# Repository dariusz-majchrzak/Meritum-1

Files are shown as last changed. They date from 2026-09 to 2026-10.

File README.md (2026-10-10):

# Meritum 1 clone
This repository provides all the files needed to build a **Meritum 1 (Model 1)** ( https://pl.wikipedia.org/wiki/Meritum_(komputer) ) hardware recreation, closely following the design of the first microcomputer to be mass‑produced in Poland.<br>

Production of the Meritum computer began in mid‑1983, and its architecture was based on a design similar to the TRS‑80 Model I. Across all versions — Meritum I, II, and III — approximately 2,500 units were produced between 1984 and 1986.<br>

It has fascinated me for years as an important part of Poland’s computing history. I never had the chance to see an original unit in person, and my attempts to buy one at auctions quickly ended with prices far beyond reach. 
I also noticed that almost no modern retro‑computing projects related to it exist.

Given that, I decided to build one myself: using the documentation available online — schematics, module descriptions, and board photos — I set out to recreate the machine as my own hardware project.

**Meritum 1 (Model 1)** <br>
Basic Technical Specifications:
* RAM: 16 KB (RAMD) + 1 KB (RAMS)
* ROM: 14 KB (BASIC)
* Video Memory: 1 KB (RAMS)
* Display Modes: Text — 16×64 or 16×32
* Peripherals: serial interface (i8251), parallel interface (i8255), tape connector
* Colors: Monochrome
<br>
As of September 27, 2026, there are 4 successful builds (based on this pcb project), so the design files can be assumed valid.<br>
<br>

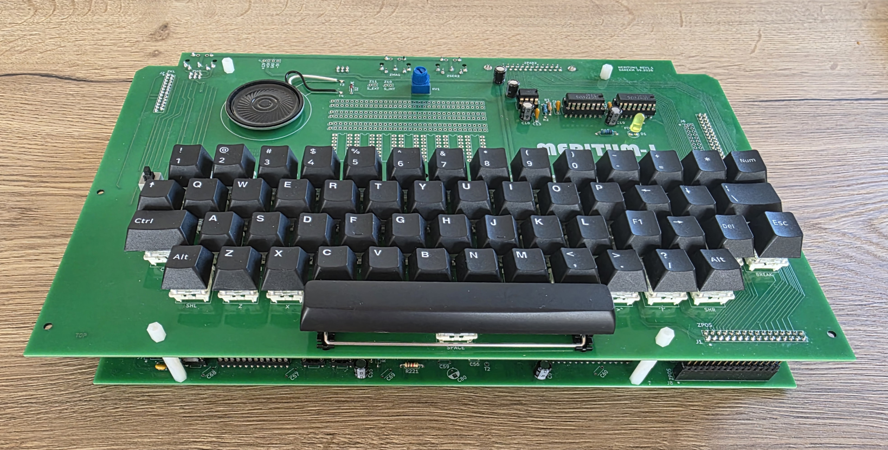
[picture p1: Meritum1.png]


Important notes:<br>
* Please note that this is a complex hardware project that requires solid technical expertise from anyone who decides to build it.<br>
* While significant care has been taken during the design and verification process, the project may still need additional fixes, especially if the original design included fixes implemented directly at the PCB level that were not reflected in the published schematics.

## PCBs
The clone consists of two separate PCBs:
* [Meritum_PGW](Meritum_PGW) (Meritum Płyta Główna) - is the main board.
* [Meritum_KLT](Meritum_KLT) (Meritum Klawiatura) - is a replacement keyboard that uses standard Cherry MX switches.

## ROMs
Since the licensing status of the ROMs used in the Meritum 1 computer is not clear to me, I have not included them in this repository.<br> 
Below, however, I provide links to a websites where they can be found, along with many other valuable resources:
* https://web.archive.org/web/20201023154655/https://sites.google.com/site/krzkomar/meritum-1
* https://www.planetemu.net/rom/mame-roms-merged/meritum1<br>
  
Many useful materials can also be found at: https://www.speccy.pl/news.php .

## Assembling
Although the mainboard includes several configuration jumpers, it does not require any additional settings that need to be adjusted before powering it on. The default configuration is sufficient.<br>

To connect mainboard with keyboard I have used:
-  single and double Row, 2.54mm straight, Gold PCB Female Sockets Connector
-  single and double Row, 2.54mm straight, Gold PCB Male Pin Header connector (h=29.5mm)
  
More to follow.

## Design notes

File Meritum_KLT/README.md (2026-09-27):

# Meritum 1 - keyboard

This part of the project is the clone of the Meritum 1 keyboard.

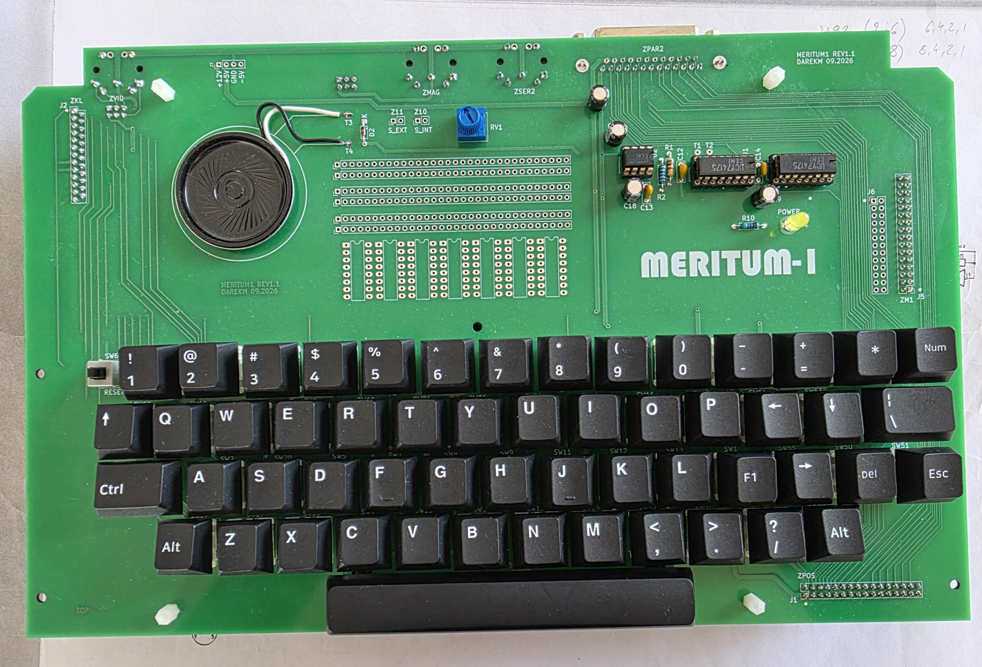
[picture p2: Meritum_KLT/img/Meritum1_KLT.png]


## Files
This directory contains: 

* [BOM](bom) - Interactive HTML BOM
* [Gerber](gerber) - files (JLCPCB-compatible zip files)
* [IMG](img) - photos of the keyboard
* [KiCAD](kicad) - project design in KiCAD 10
* [Schematic](schematic) - Schematic in PDF format

## Assembling
As for assembling the keyboard PCB, there are no major challenges here. The board is relatively straightforward to build.<br> 
One piece of information may be more important: for mounting the switches I used gold‑plated hot‑swap sockets for mechanical keyboards.
See: [Meritum1_KLT_BOTTOM](img/Meritum1_KLT_BOTTOM.png)

More to follow.

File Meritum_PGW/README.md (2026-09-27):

# Meritum 1 - mainboard

This part of the project is the clone of the Meritum 1 mainboard.

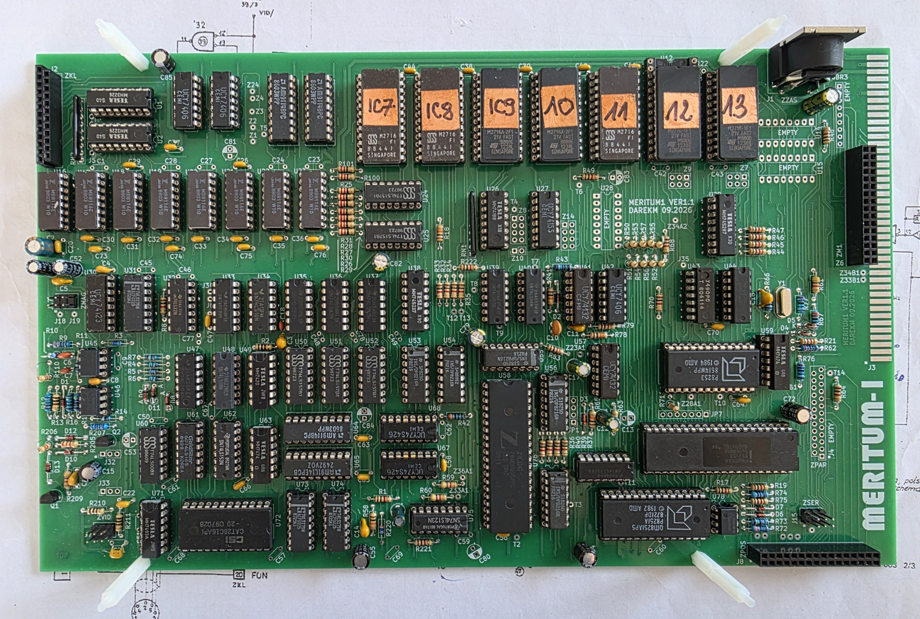
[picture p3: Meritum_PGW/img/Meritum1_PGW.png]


## Files
This directory contains: 

* [BOM](bom) - Interactive HTML BOM
* [Gerber](gerber) - files (JLCPCB-compatible zip files)
* [IMG](img) - photos of the mainboard
* [KiCAD](kicad) - project design in KiCAD 10
* [Schematic](schematic) - Schematic in PDF format

## Assembling
WIP.

More to follow.

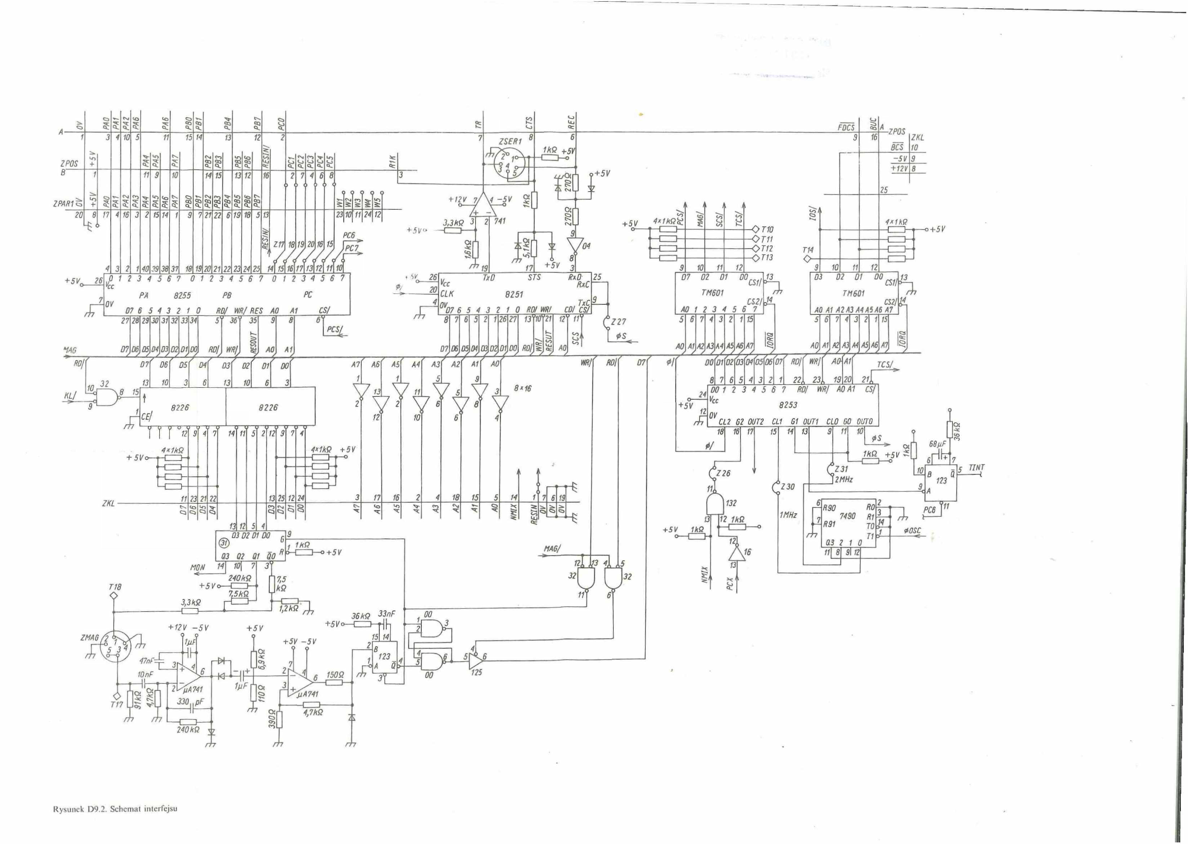
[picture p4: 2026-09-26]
docs/scans/1/interface.png

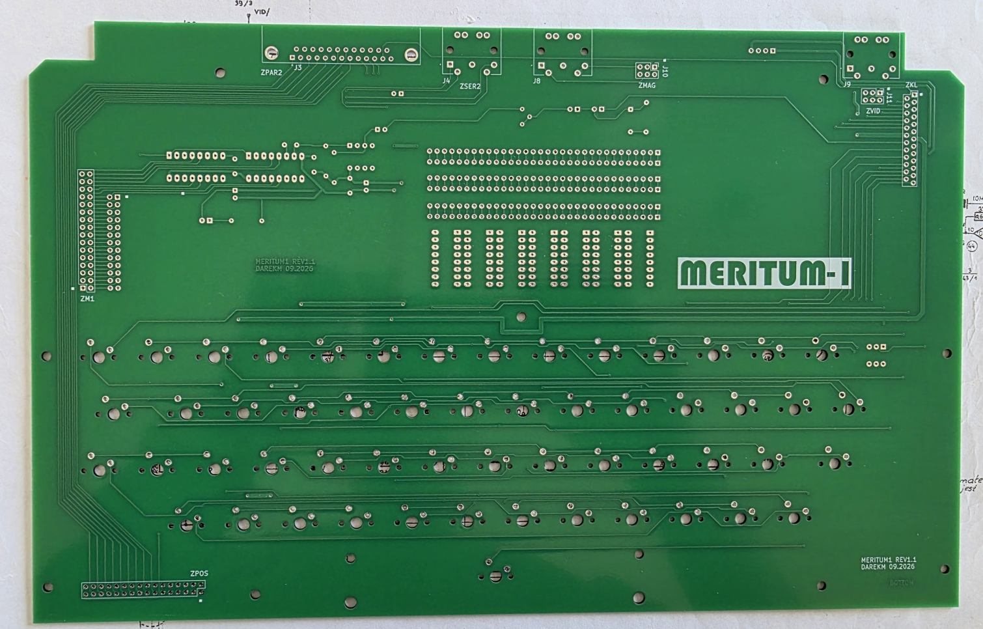
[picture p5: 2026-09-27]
Meritum_KLT/img/Meritum1_KLT_PCB_BOTTOM.png

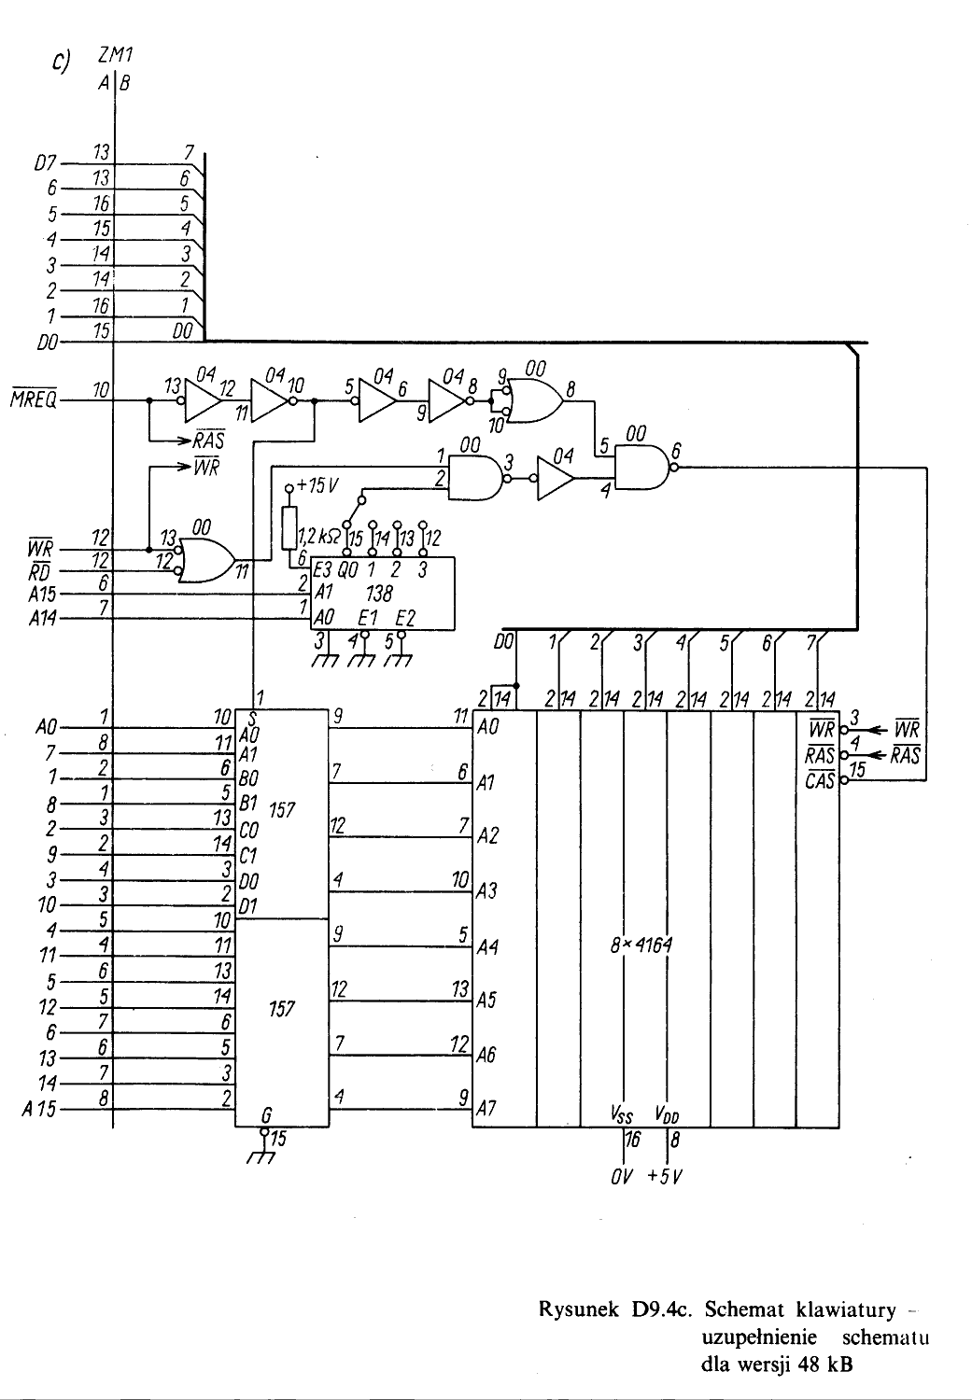
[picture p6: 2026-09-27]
docs/scans/3/D9-4c.png

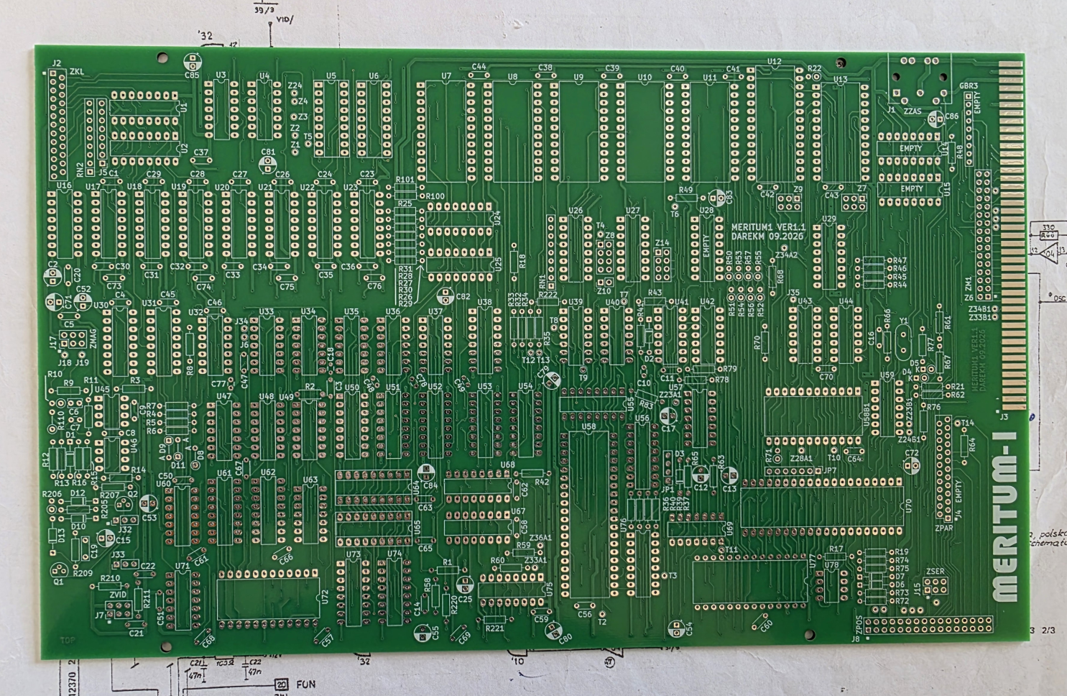
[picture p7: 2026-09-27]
Meritum_PGW/img/Meritum1_PGW_PCB_TOP.png

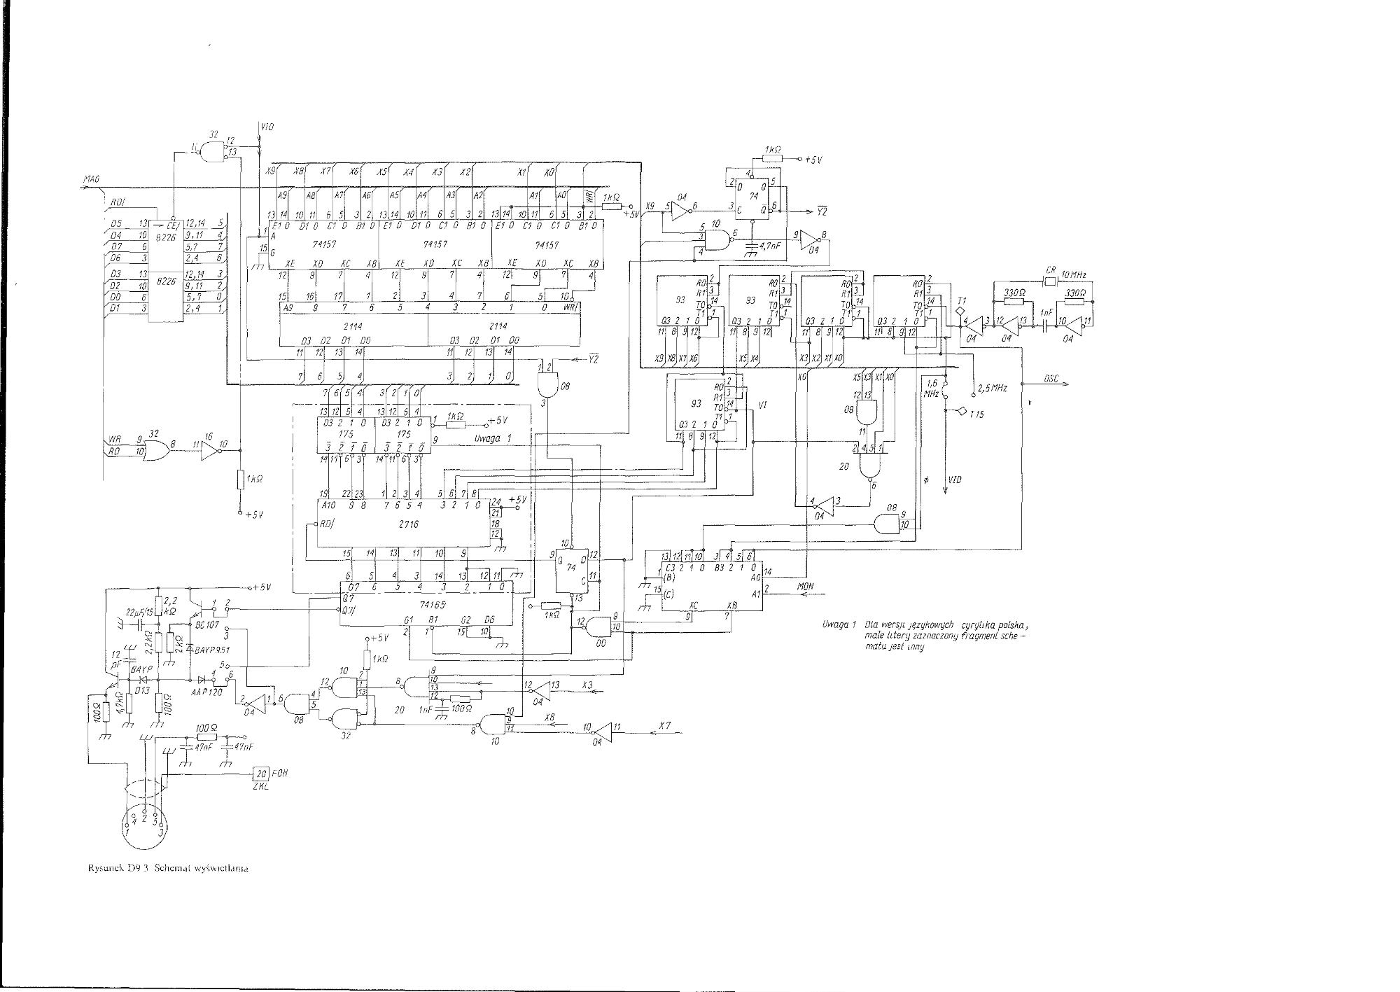
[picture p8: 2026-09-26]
docs/scans/1/display.png

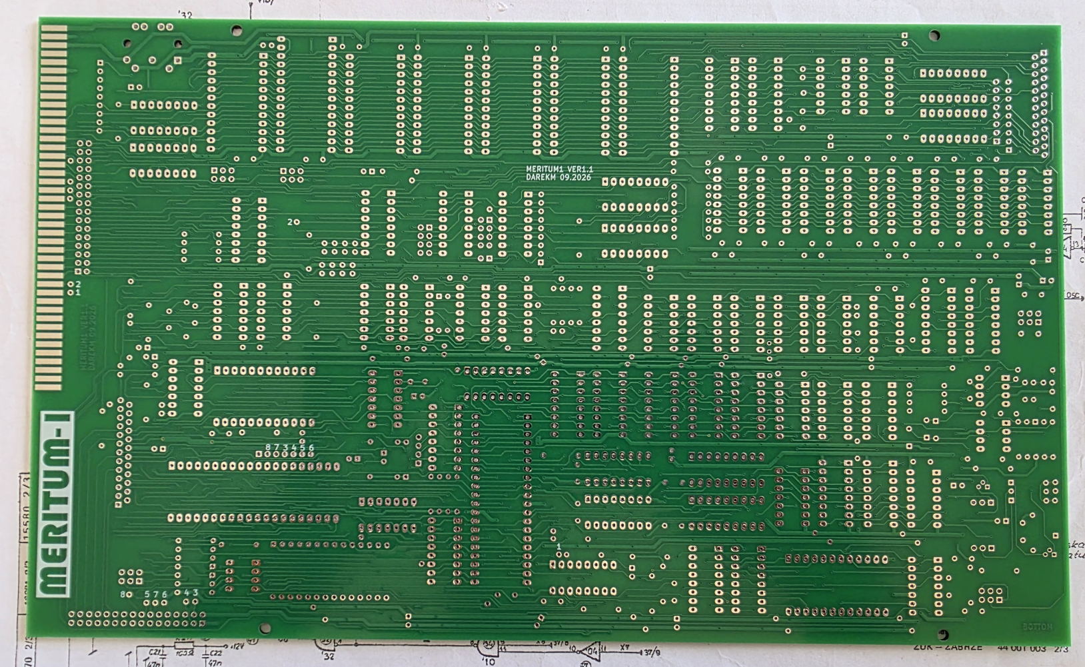
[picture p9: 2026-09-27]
Meritum_PGW/img/Meritum1_PGW_PCB_BOTTOM.png

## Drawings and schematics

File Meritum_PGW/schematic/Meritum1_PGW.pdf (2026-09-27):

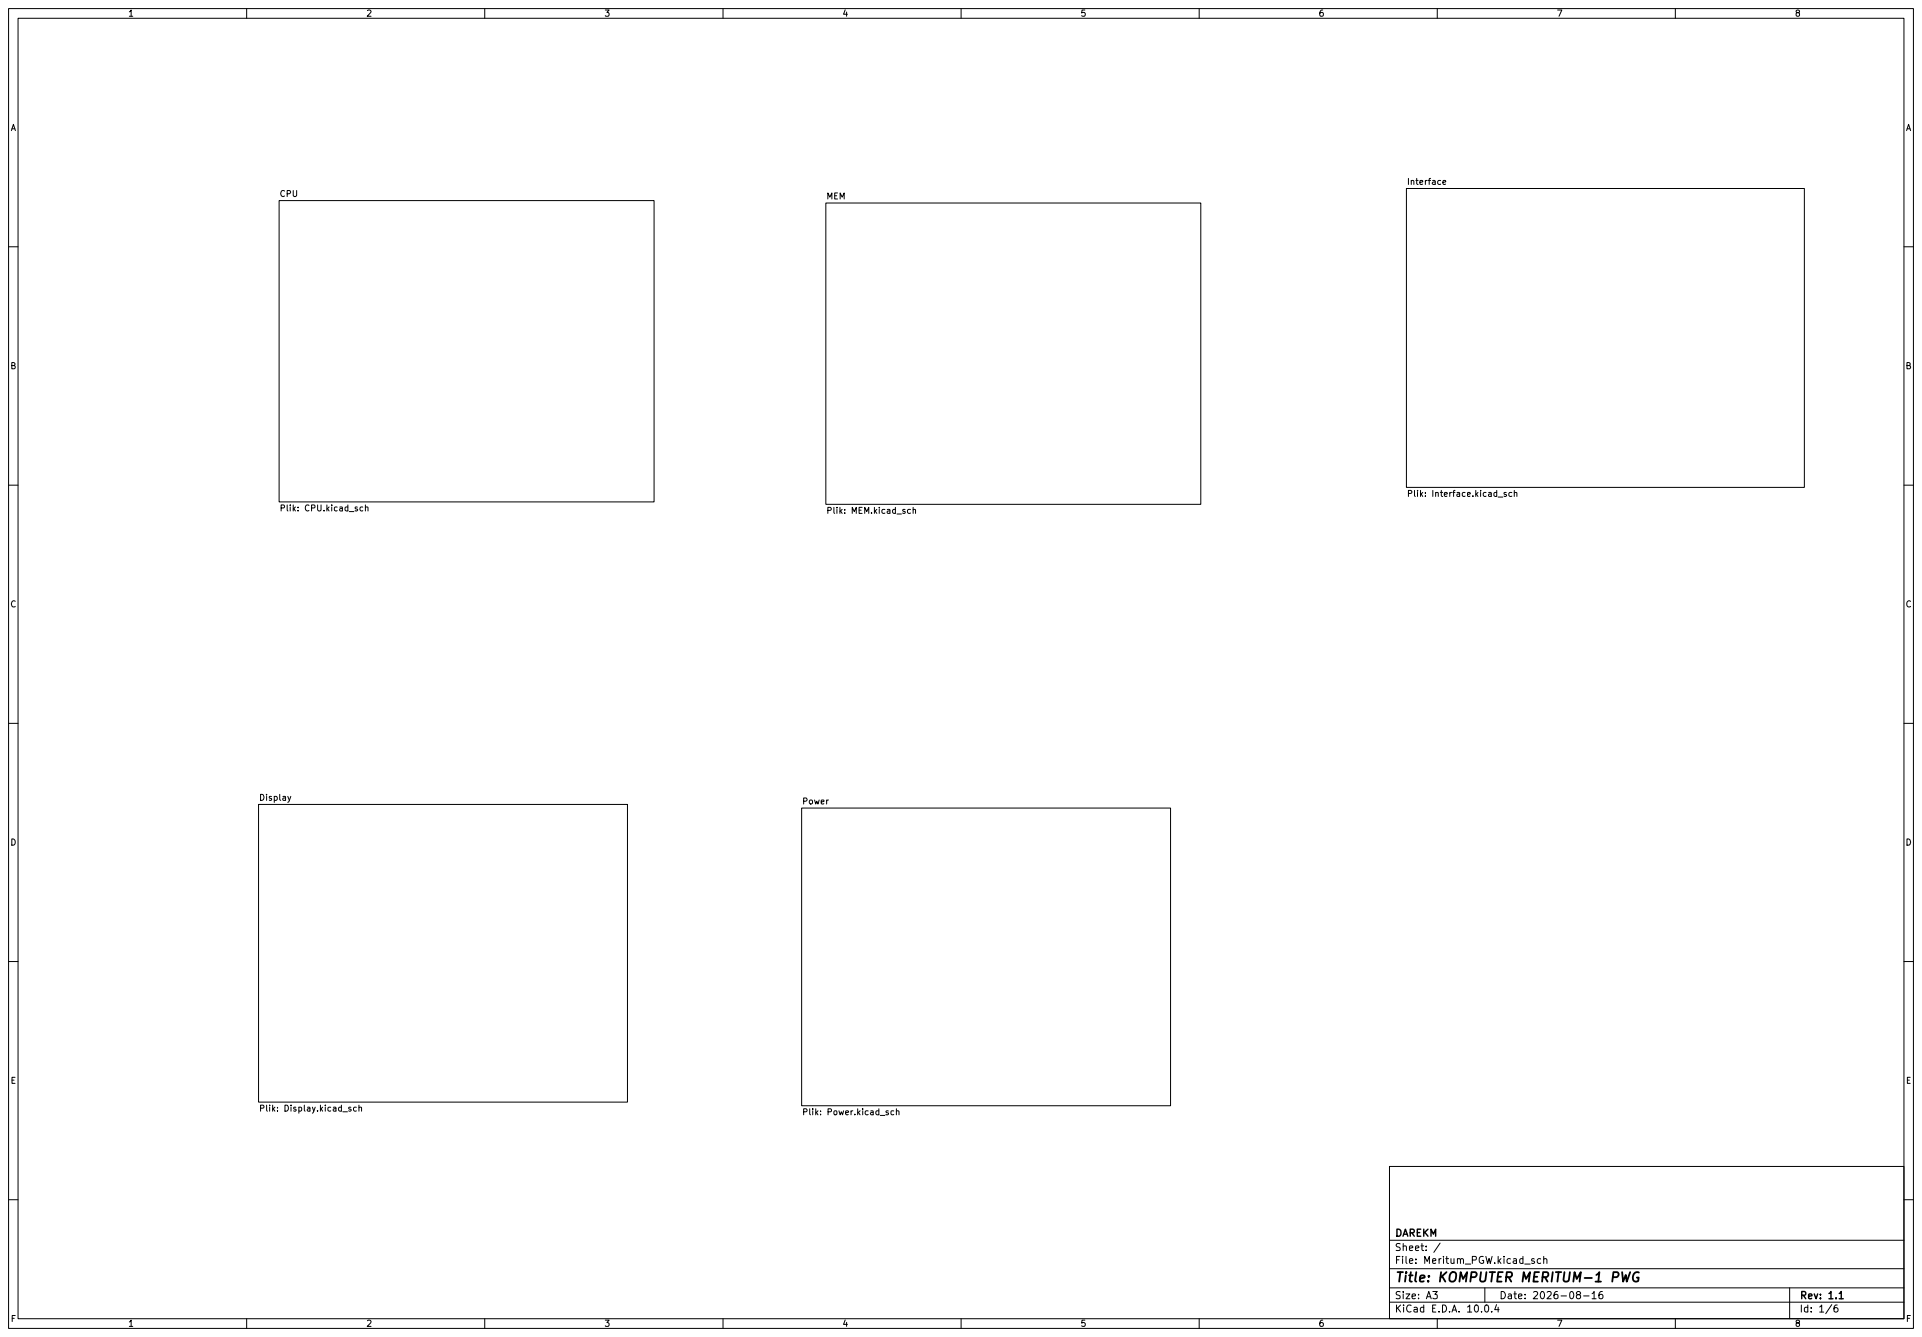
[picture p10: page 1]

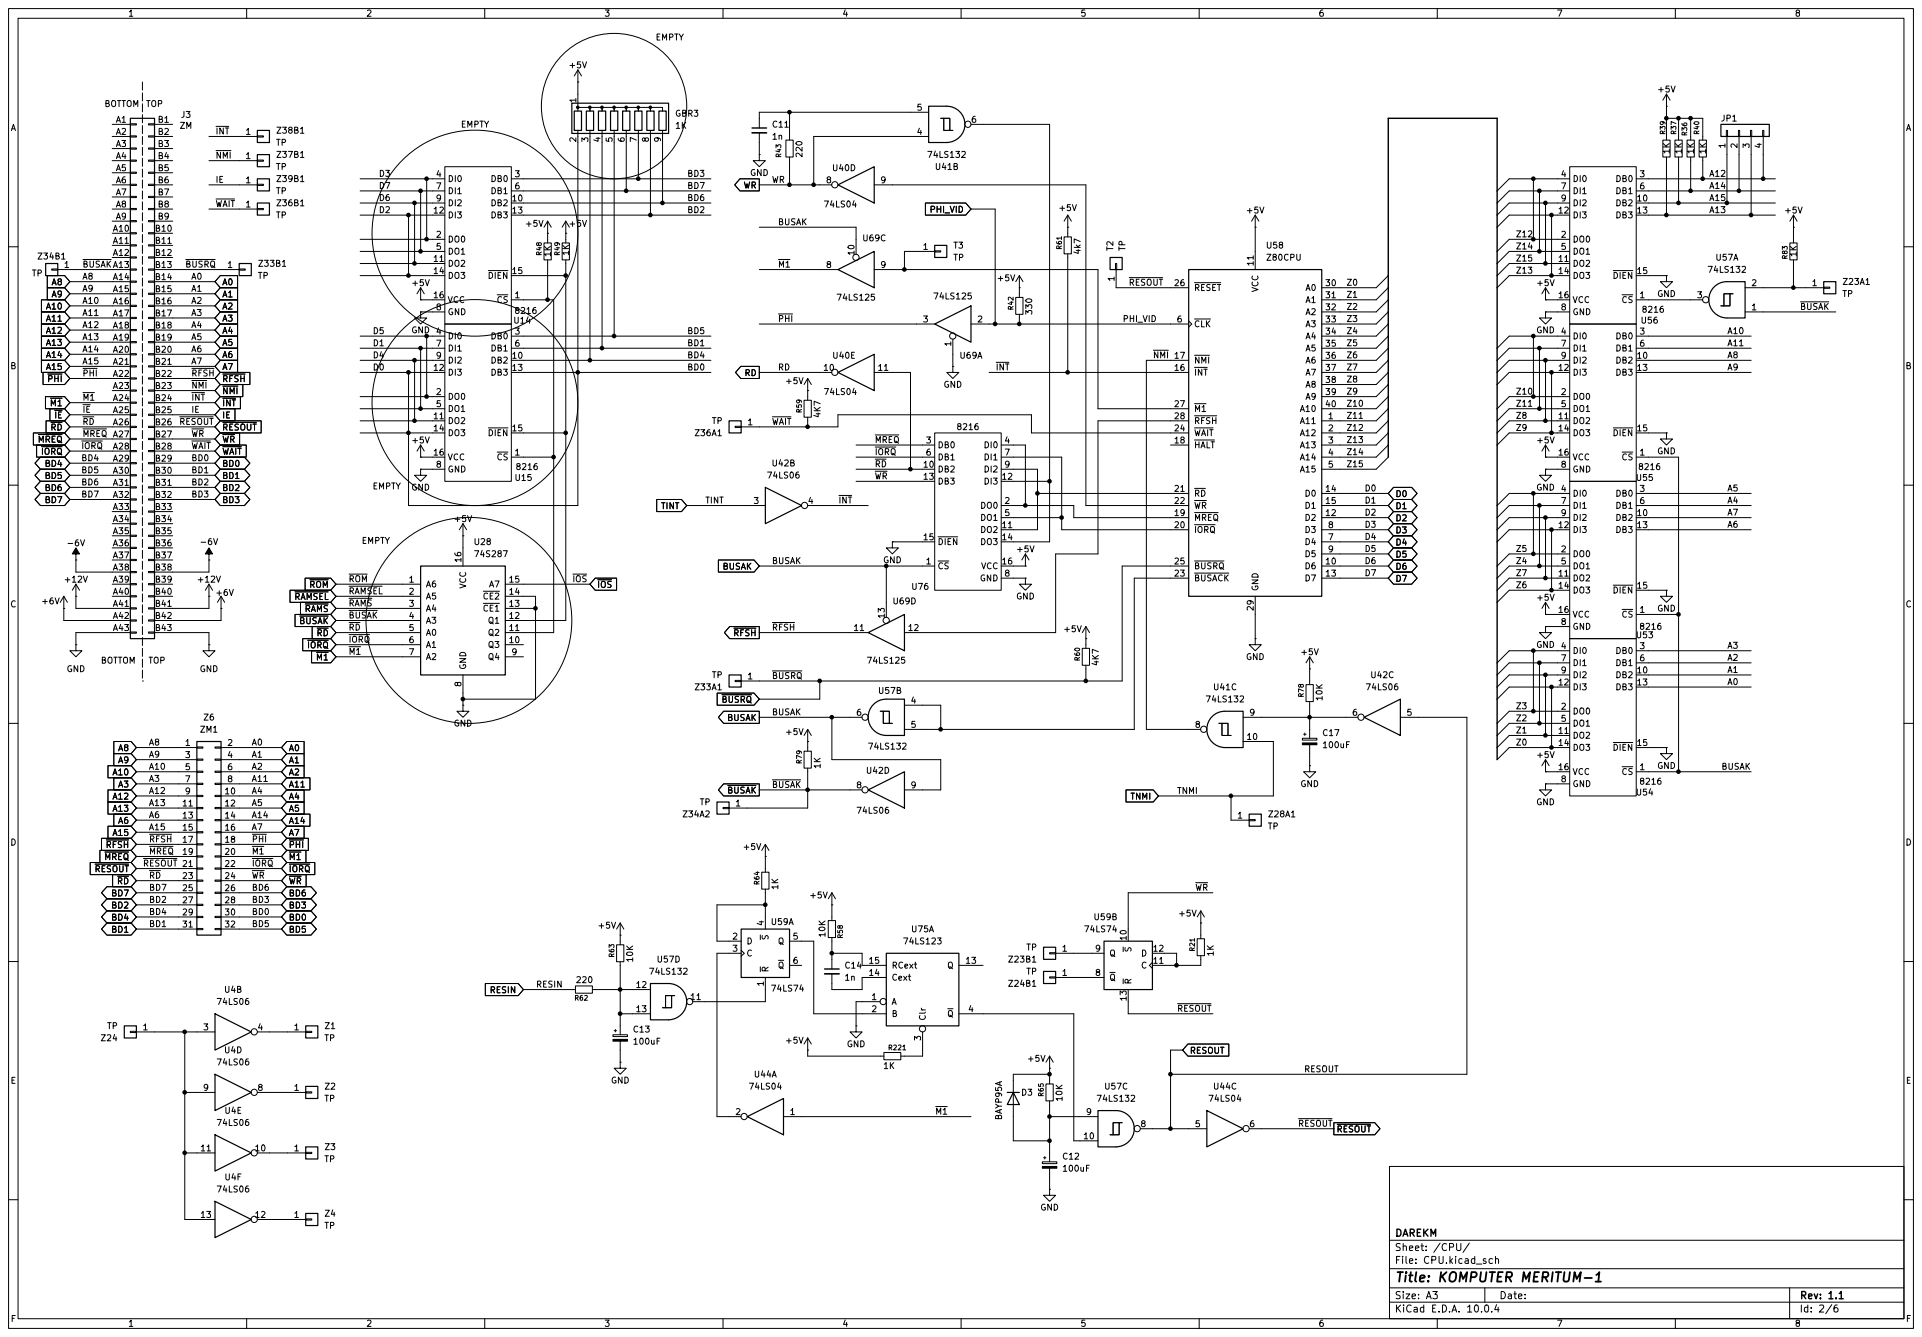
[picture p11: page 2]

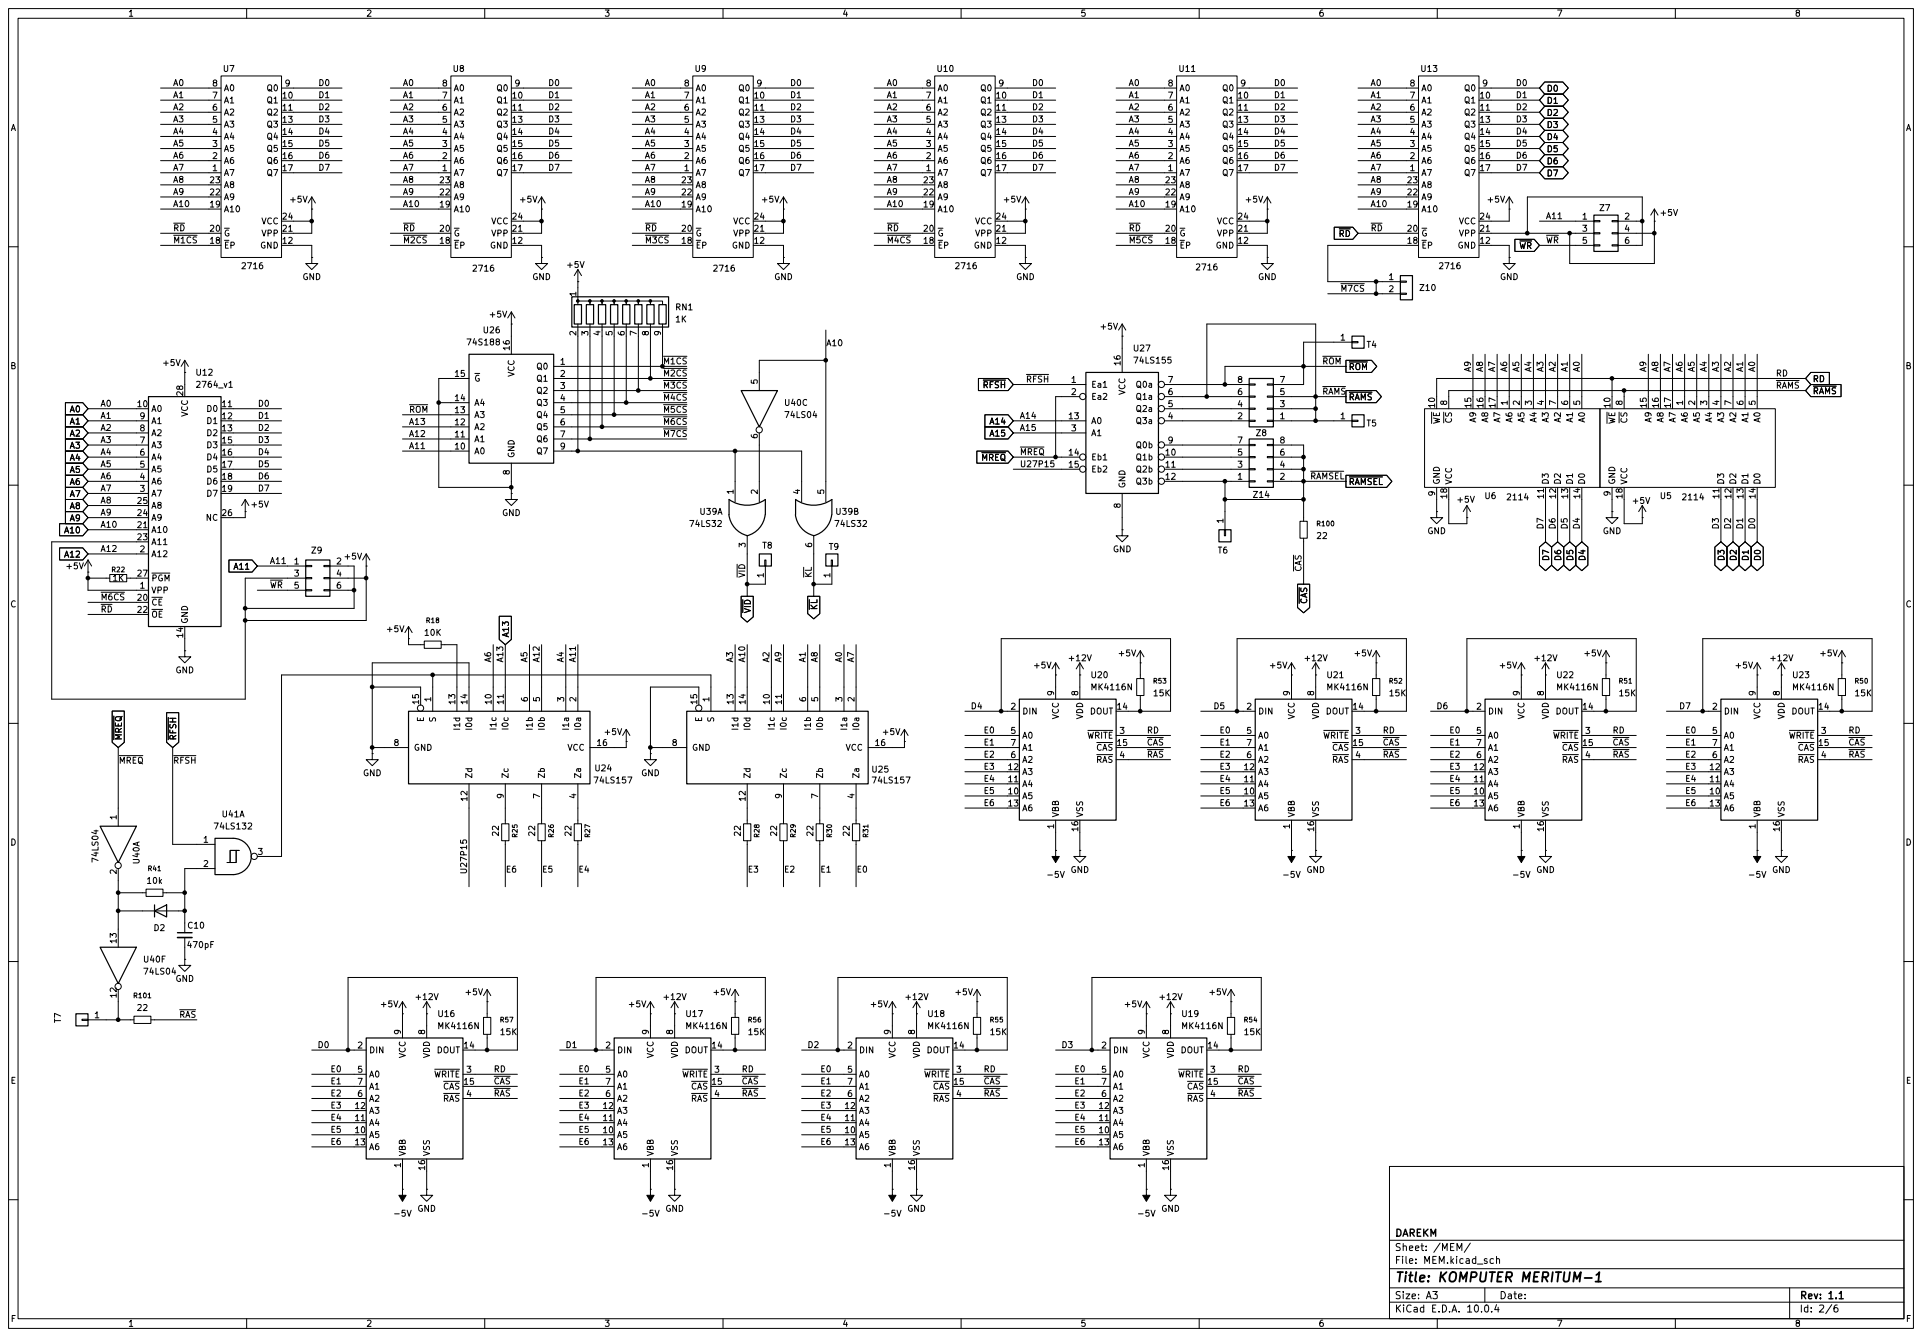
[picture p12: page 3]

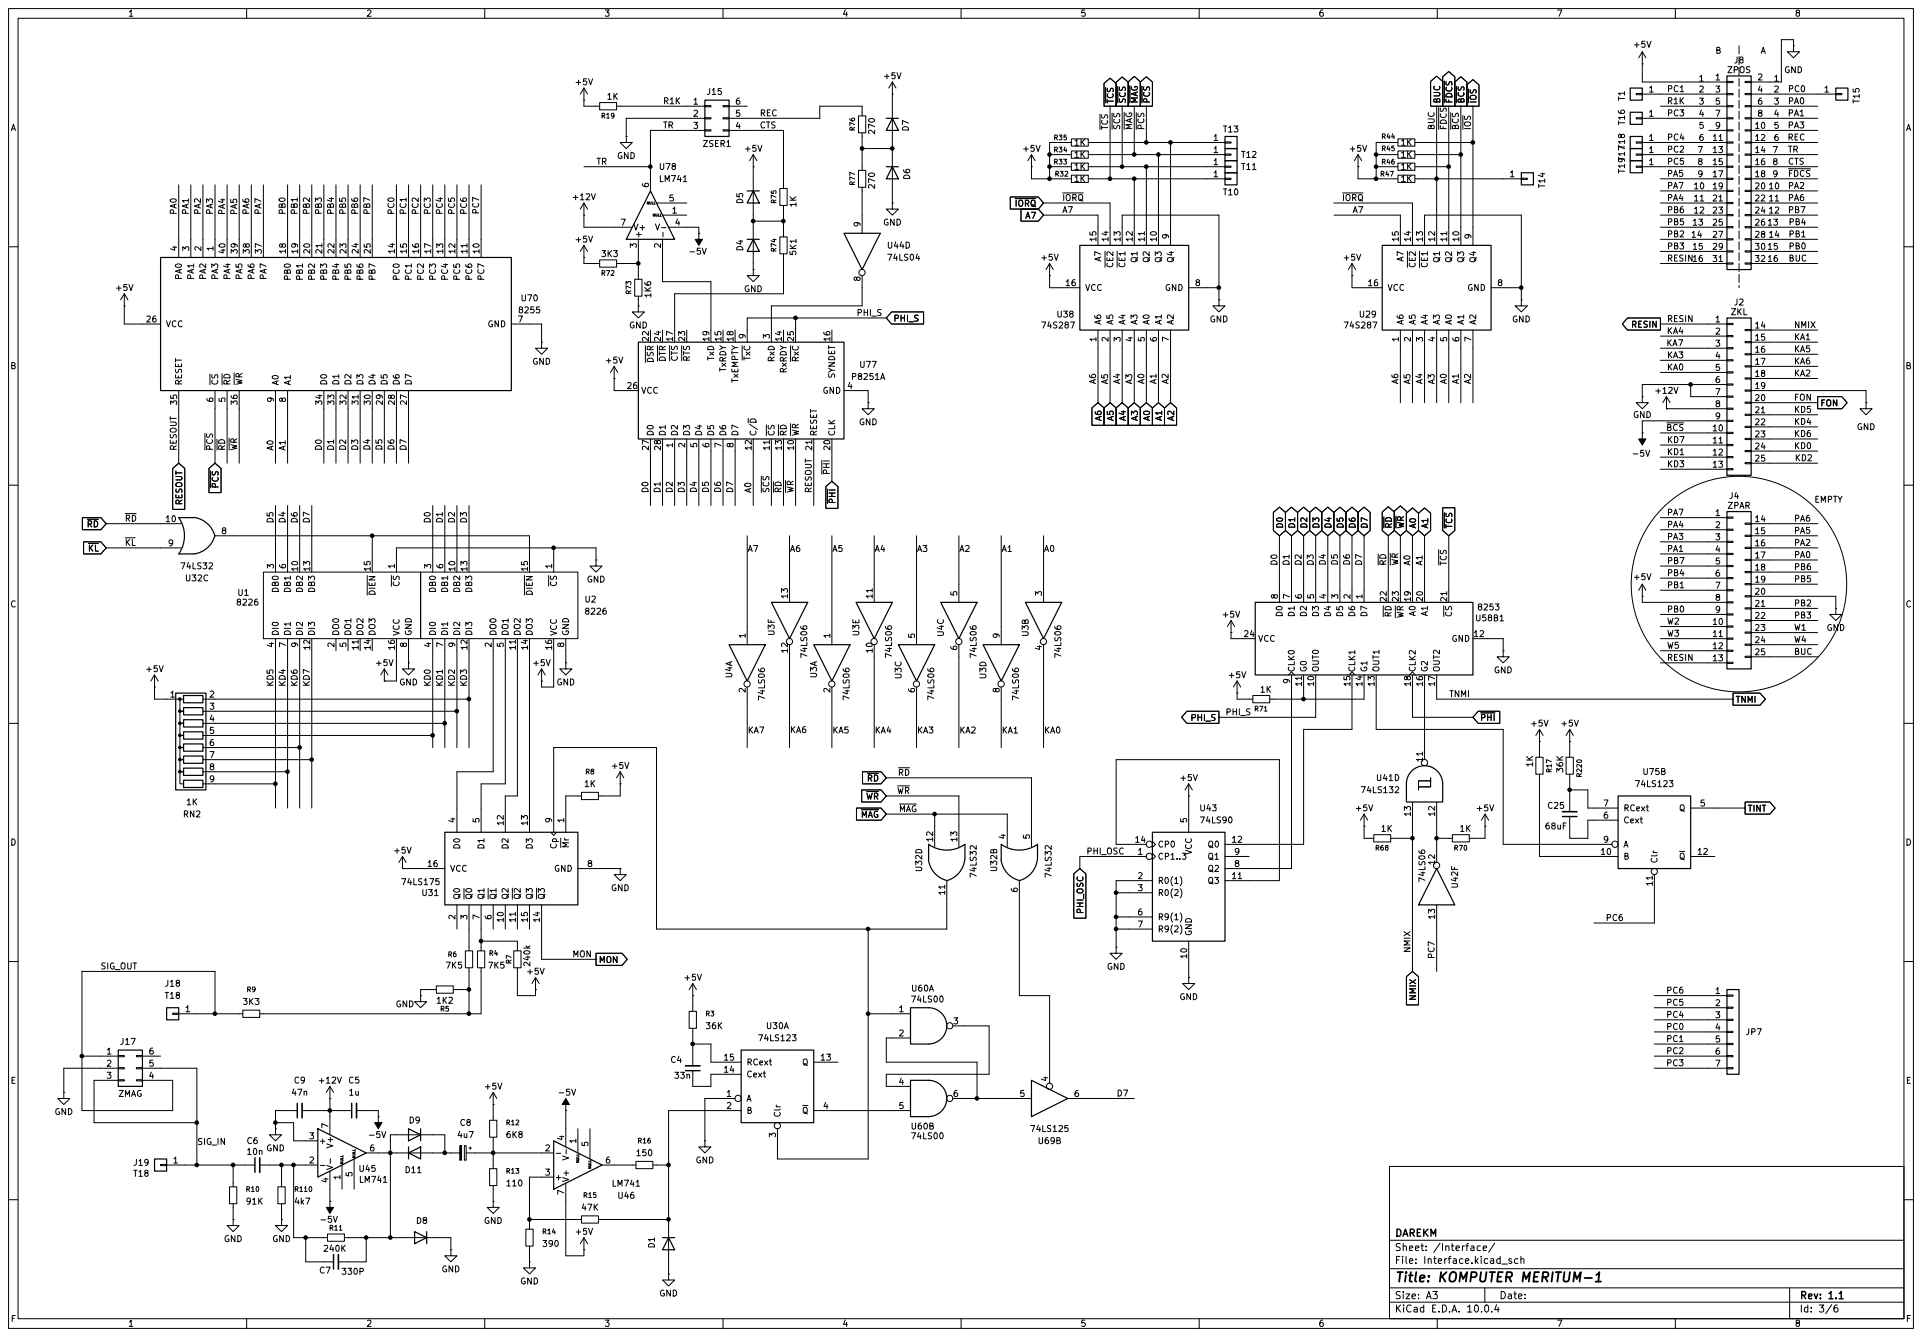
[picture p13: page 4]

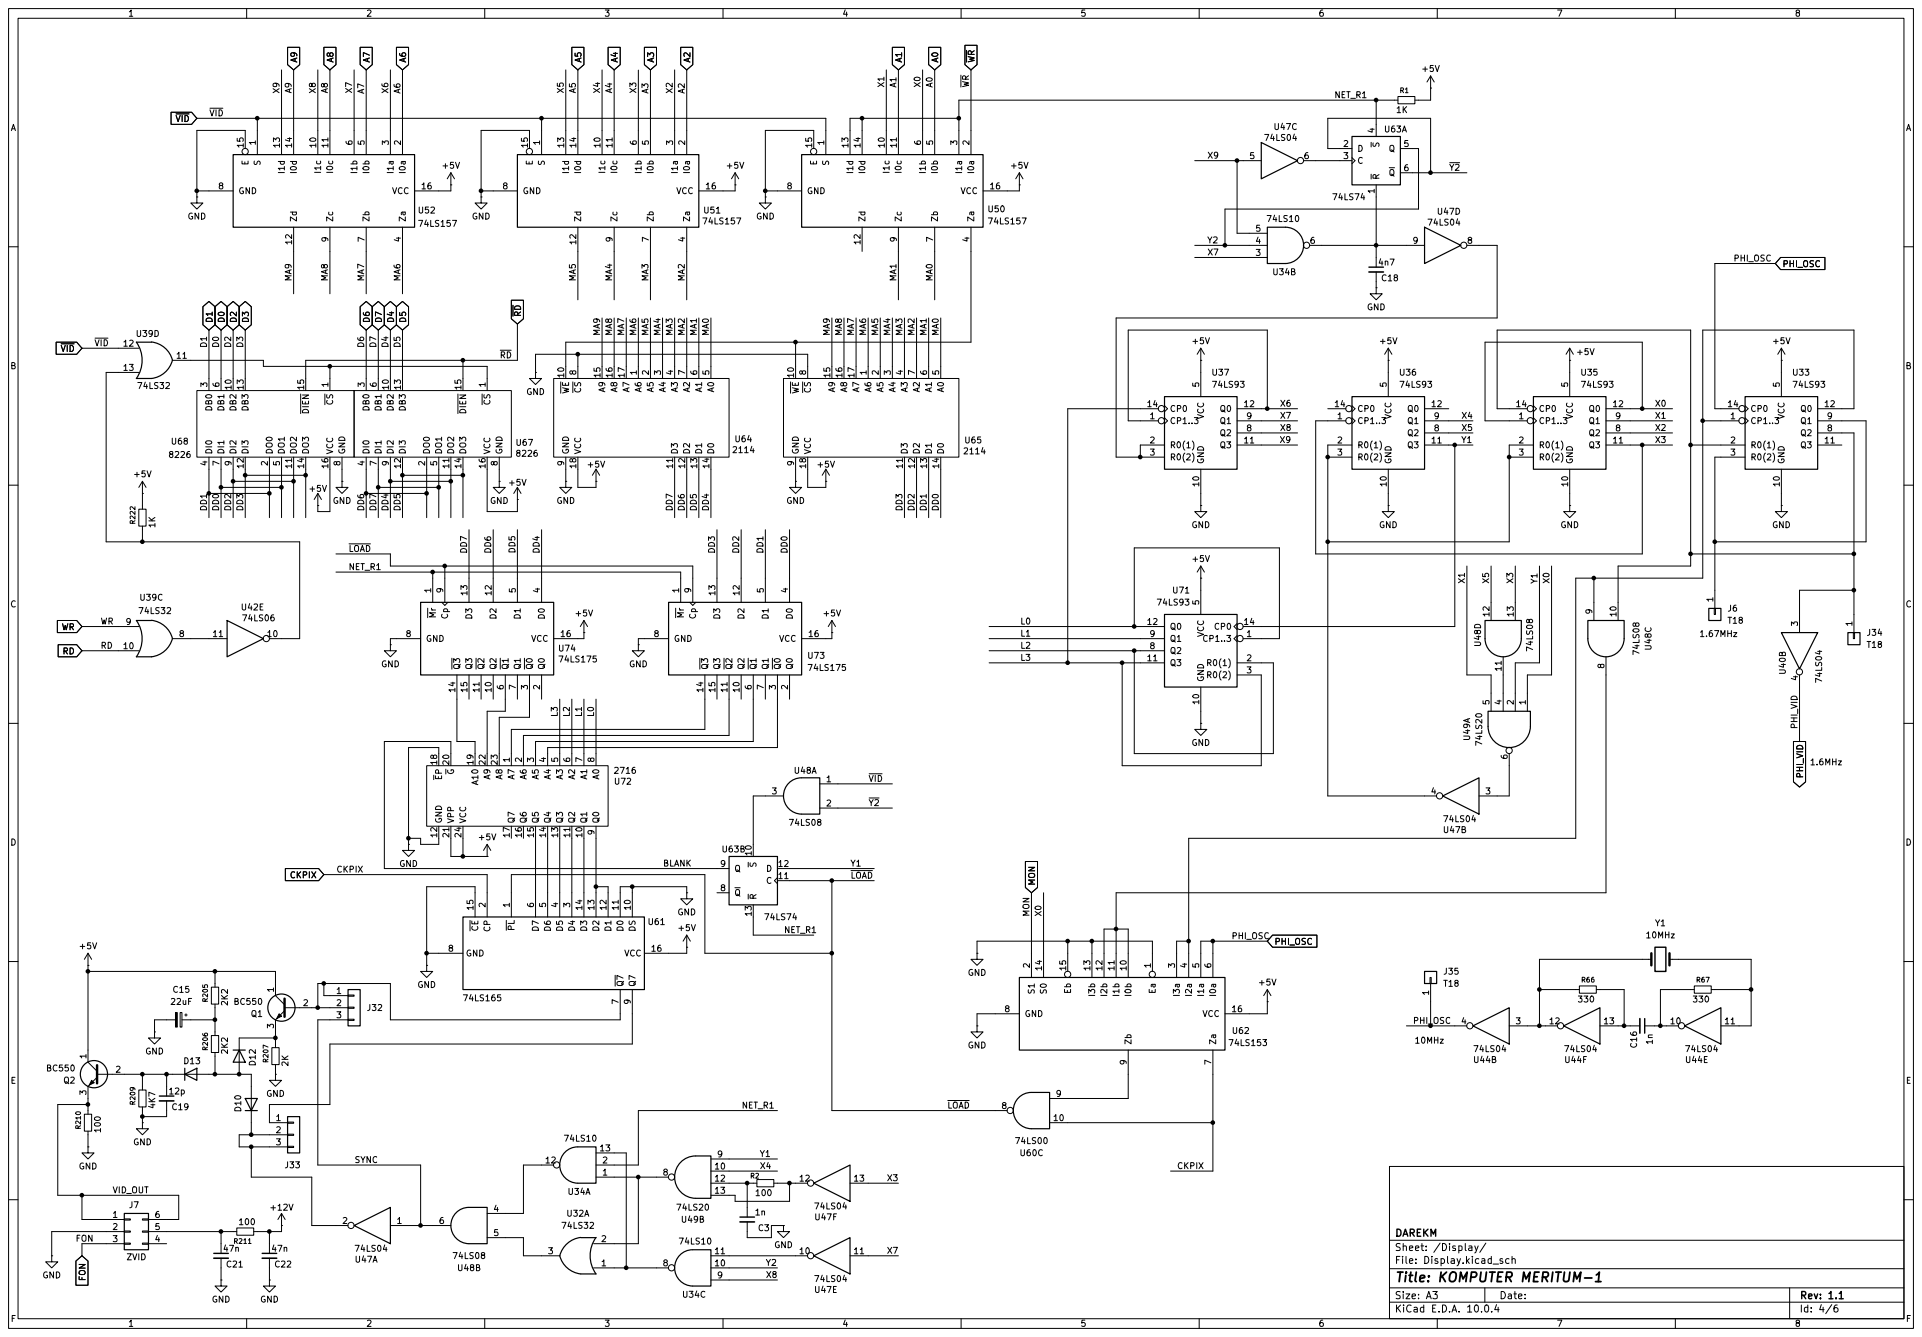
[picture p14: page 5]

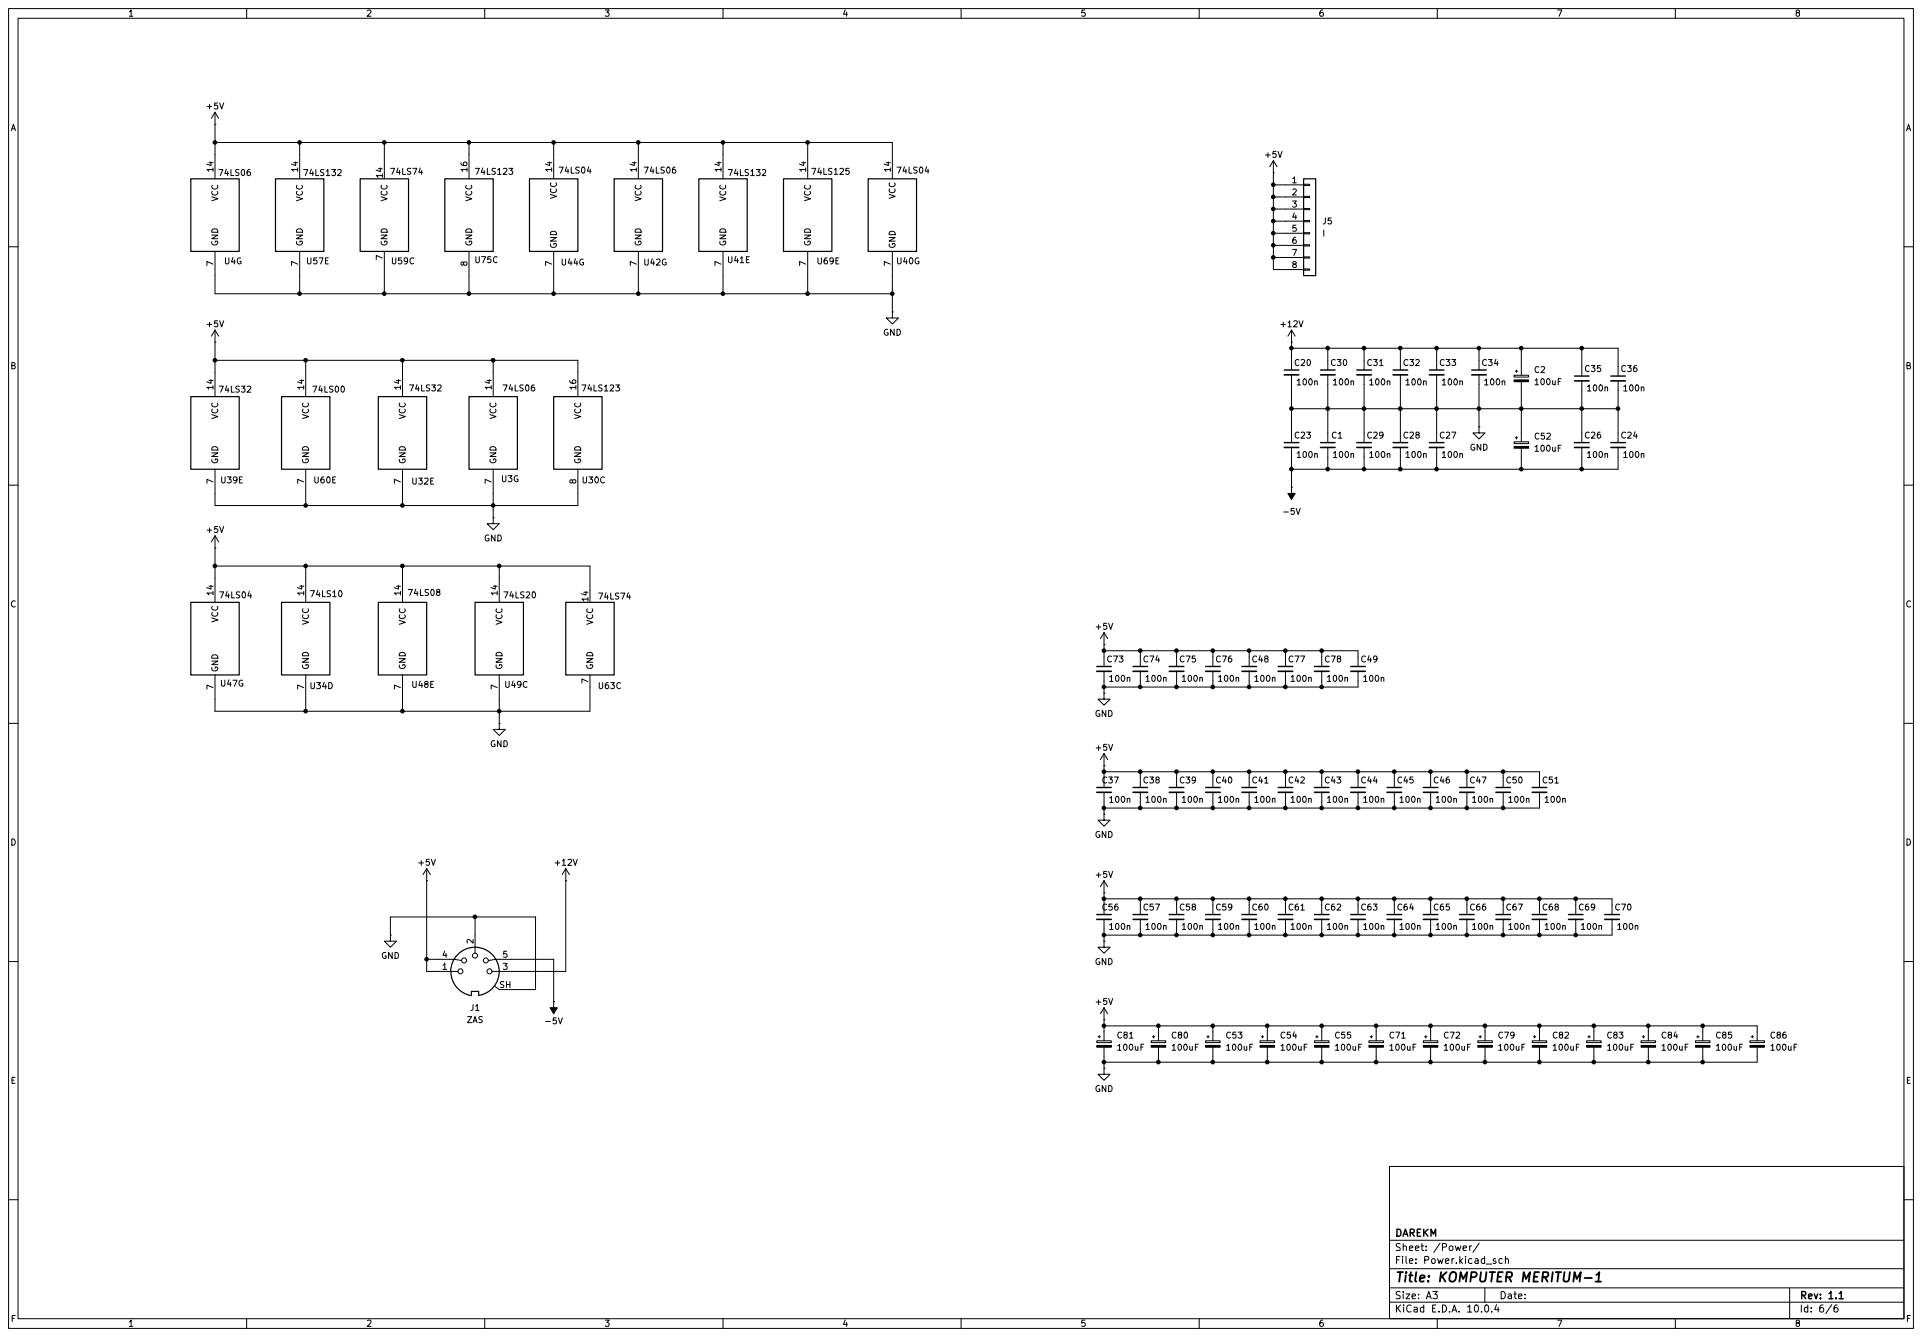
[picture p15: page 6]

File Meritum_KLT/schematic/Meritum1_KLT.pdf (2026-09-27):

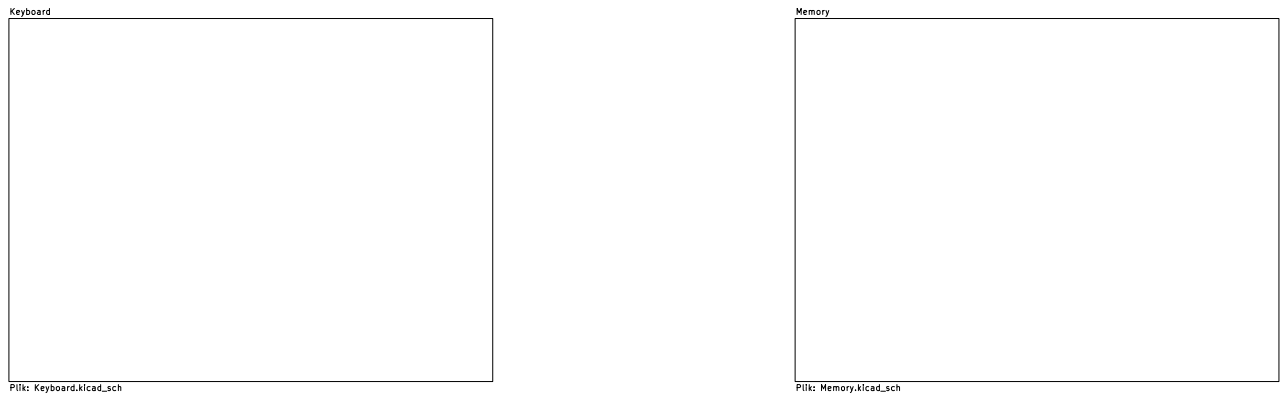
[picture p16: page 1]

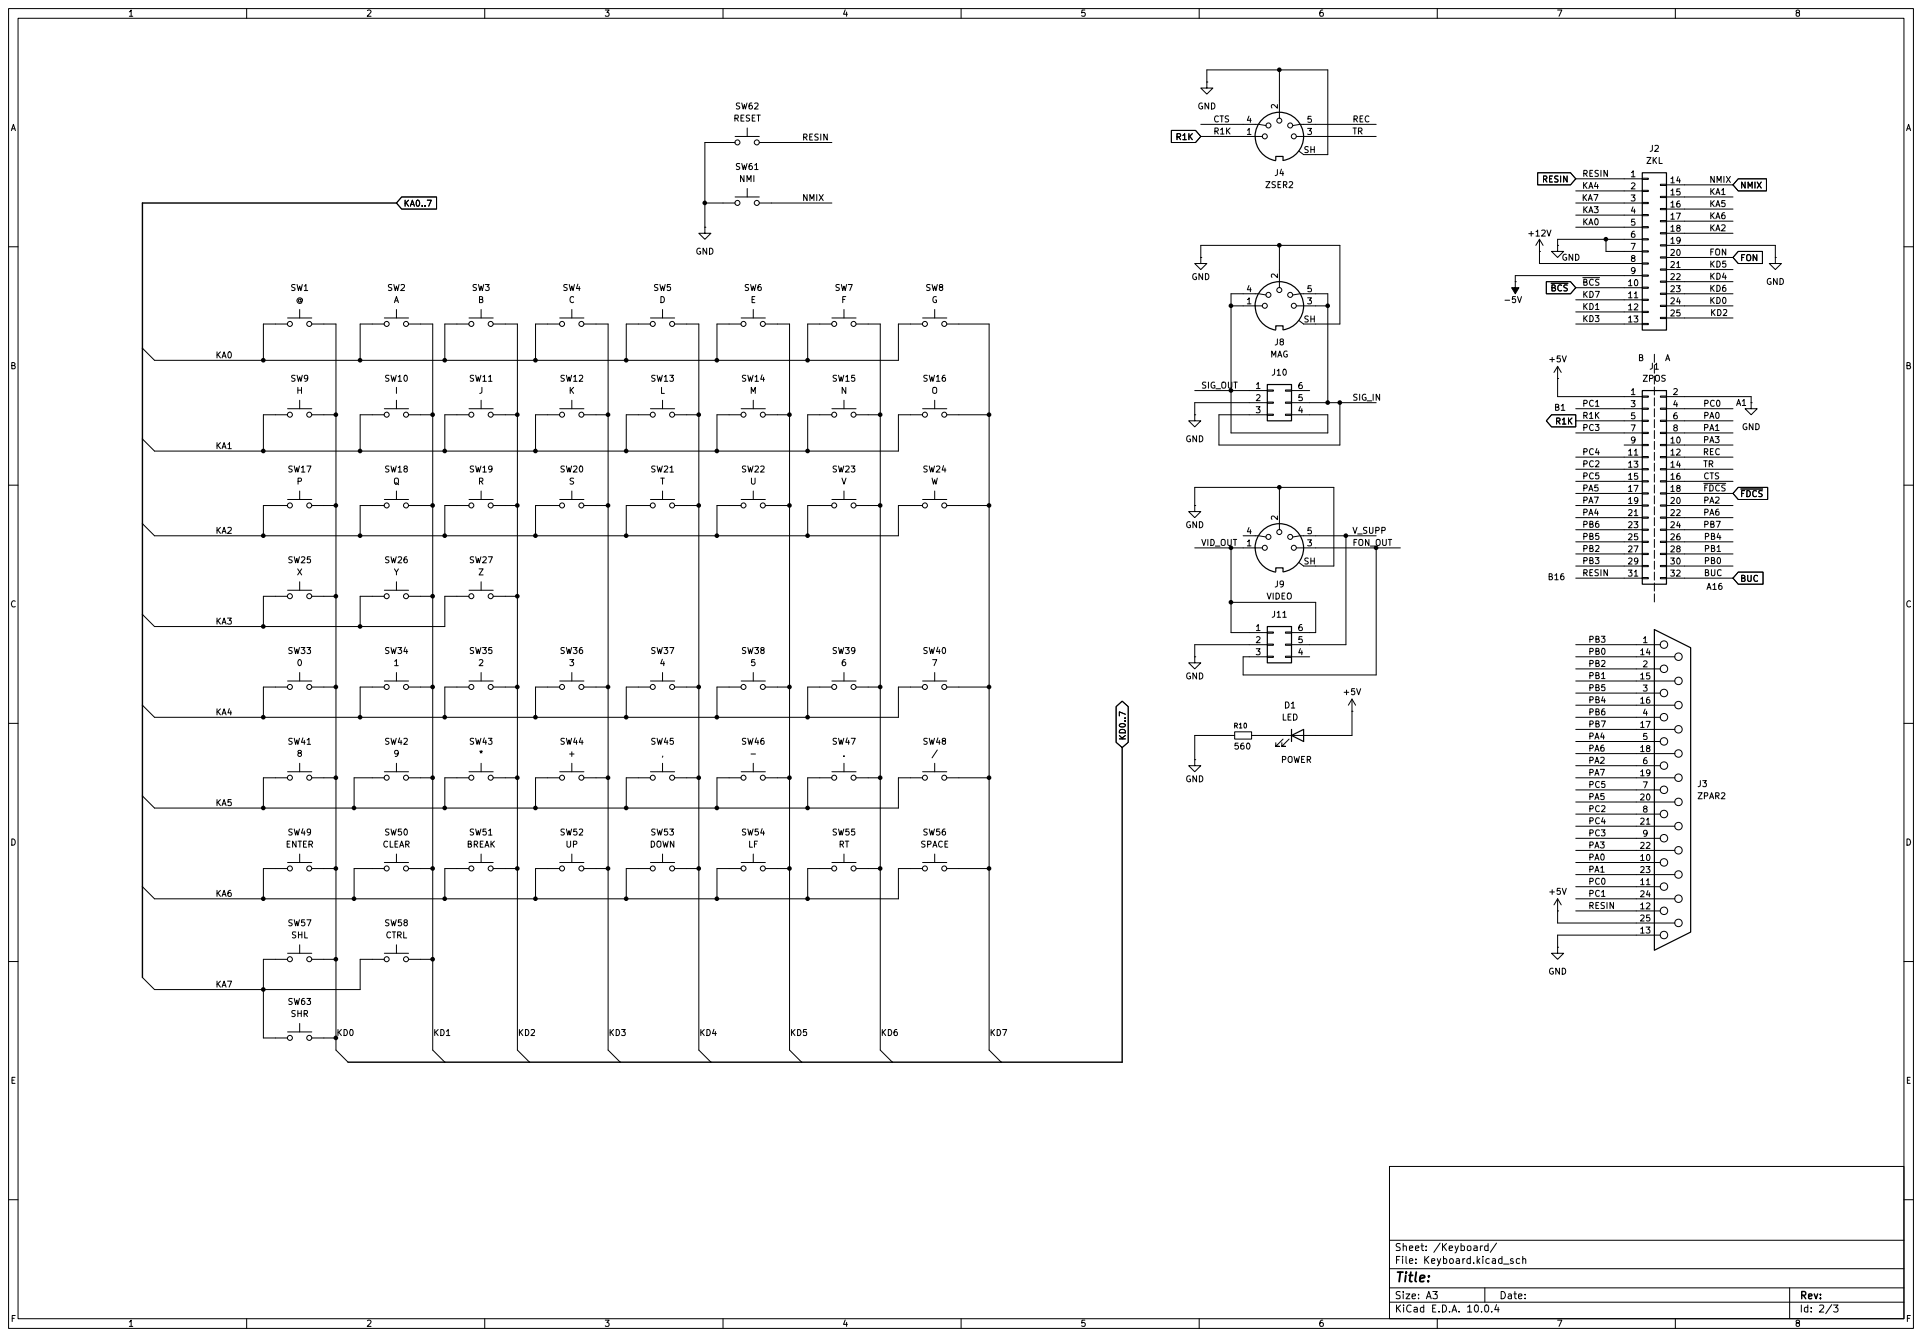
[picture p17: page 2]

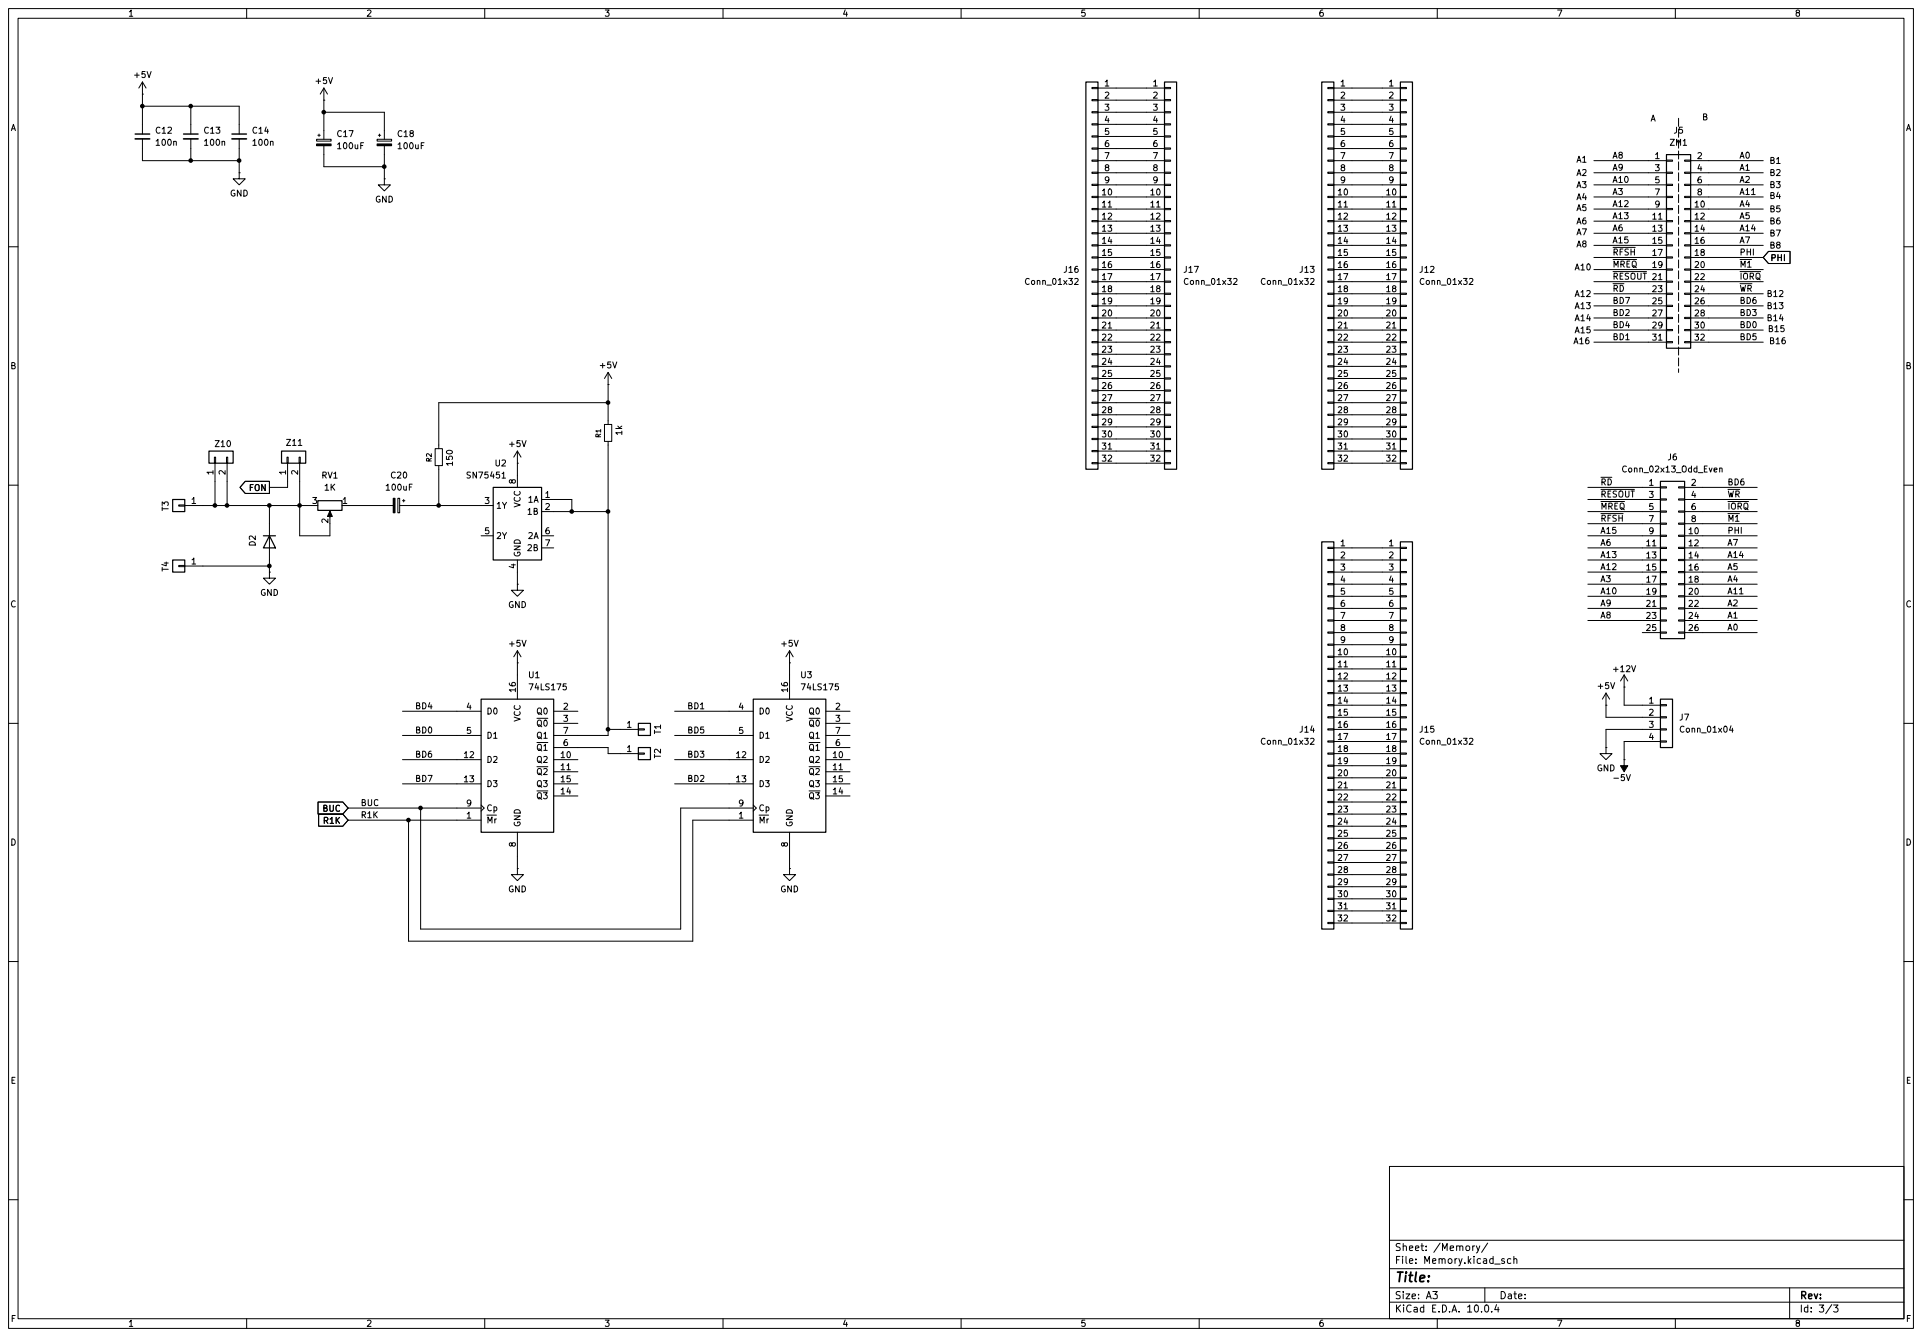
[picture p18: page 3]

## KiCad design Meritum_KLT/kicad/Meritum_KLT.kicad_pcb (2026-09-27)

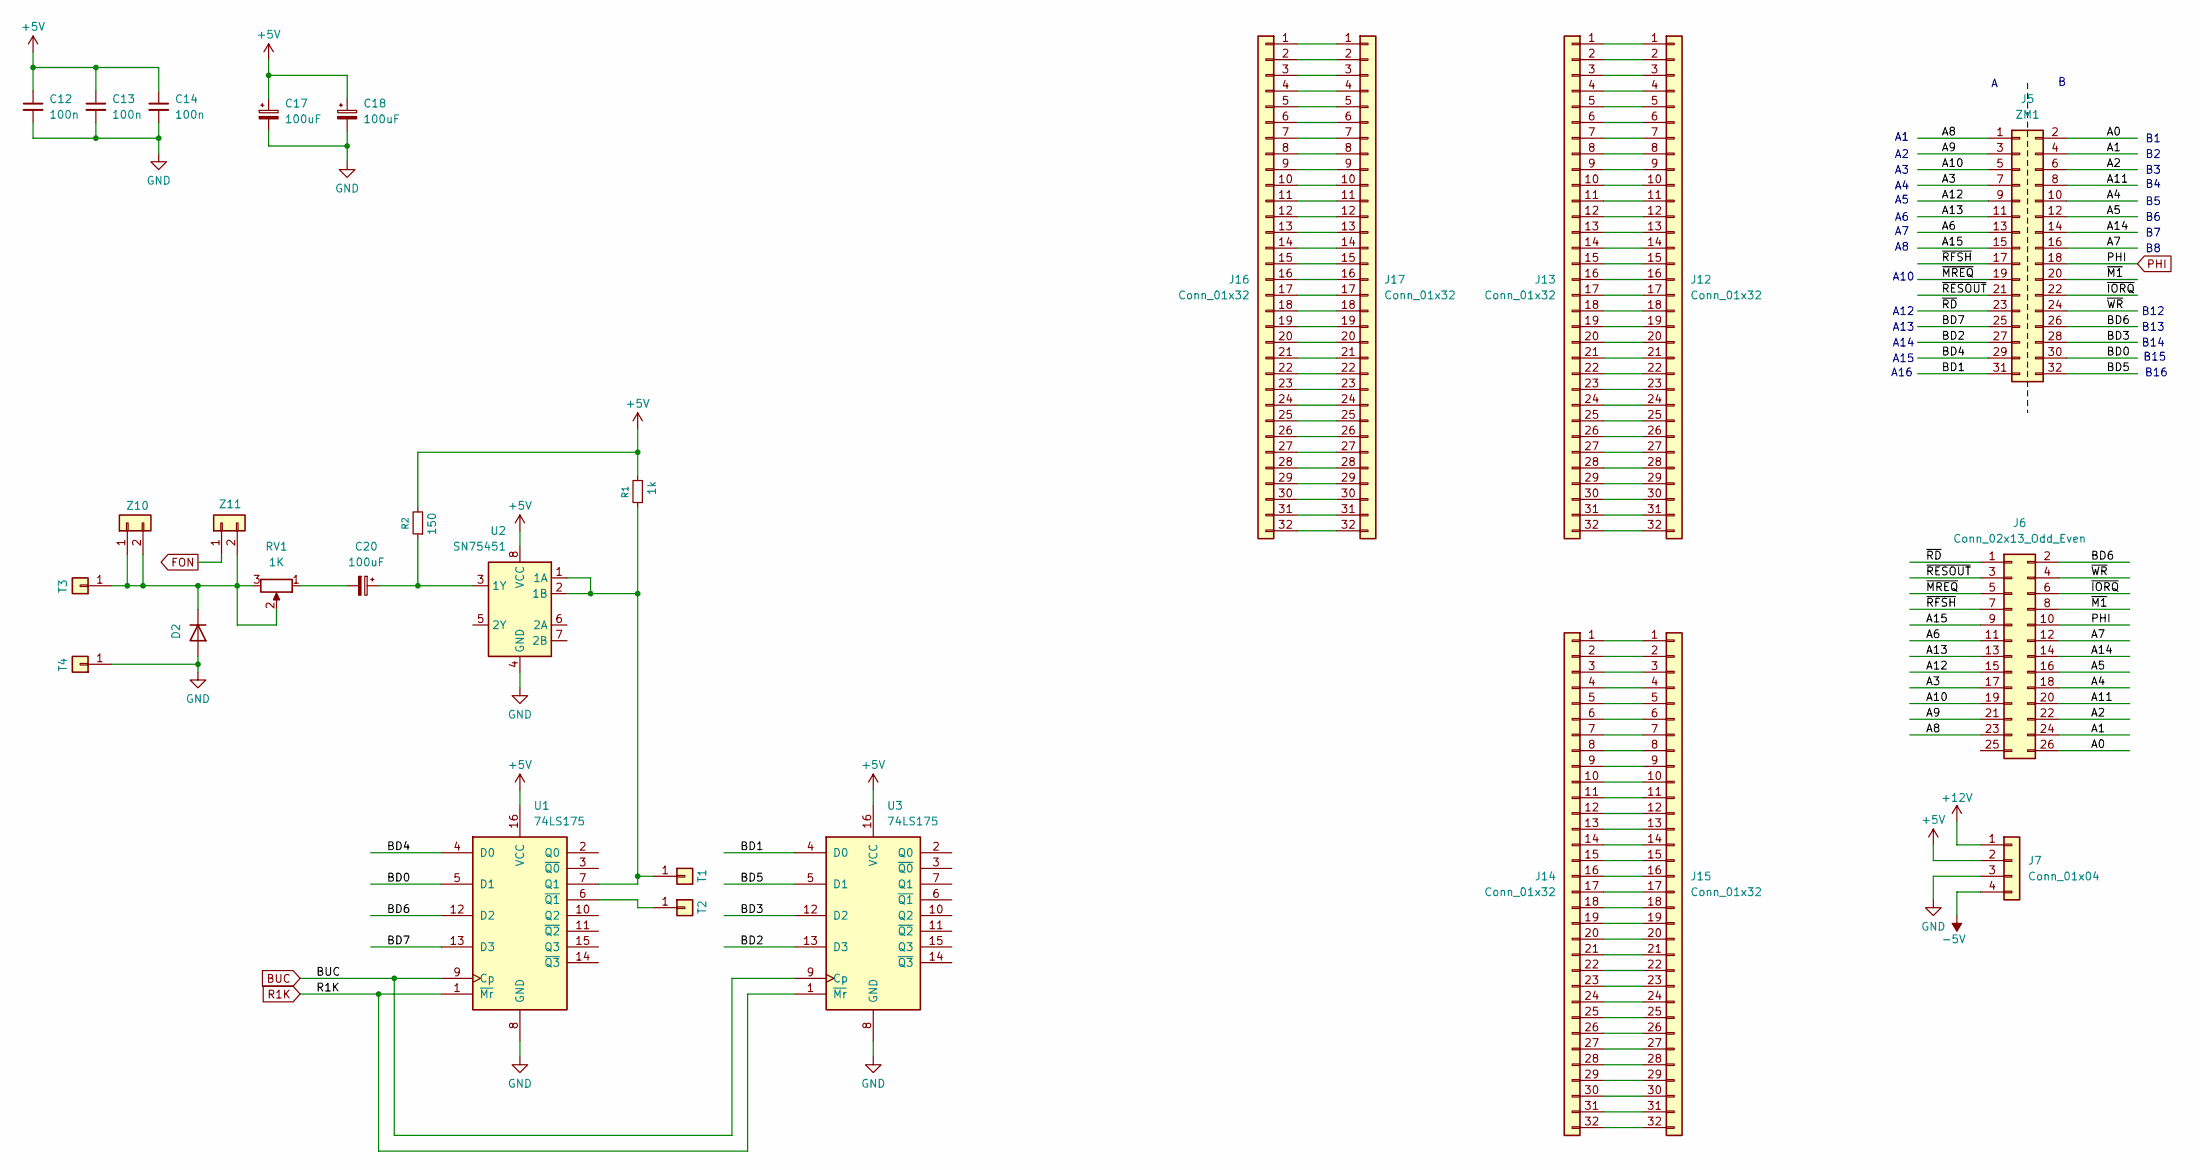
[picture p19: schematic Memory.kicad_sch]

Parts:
C12, C13, C14: 100n; C_Rect_L7.0mm_W2.5mm_P5.00mm
C17, C18, C20: 100uF; CP_Radial_D5.0mm_P2.50mm
D2: 1N4148; D_DO-35_SOD27_P7.62mm_Horizontal
J5: ZM1; PinHeader_2x16_P2.54mm_Vertical
J6: Conn_02x13_Odd_Even; PinHeader_2x13_P2.54mm_Vertical
J7: Conn_01x04; PinHeader_1x04_P2.54mm_Vertical
J12, J13, J14, J15, J16, J17: Conn_01x32; PinHeader_1x32_P2.54mm_Vertical
R1: 1k; r_400
R2: 150; r_400
RV1: 1K; Potentiometer_Bourns_3386P_Vertical
T1, T2, T3, T4: T18; pin
U1, U3: 74LS175; DIP-16_W7.62mm_LongPads
U2: SN75451; DIP-8_W7.62mm
Z10, Z11: Conn_01x02; PinHeader_1x02_P2.54mm_Vertical

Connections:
+5V: C12.1, C13.1, C14.1, C17.1, C18.1, J7.2, R1.2, R2.2, U1.16 (VCC), U2.8 (VCC), U3.16 (VCC); also elsewhere on the board
+12V: J7.1; also elsewhere on the board
-5V: J7.4; also elsewhere on the board
/Memory/A0: J5.2, J6.26
/Memory/A1: J5.4, J6.24
/Memory/A2: J5.6, J6.22
/Memory/A3: J5.7, J6.17
/Memory/A4: J5.10, J6.18
/Memory/A5: J5.12, J6.16
/Memory/A6: J5.13, J6.11
/Memory/A7: J5.16, J6.12
/Memory/A8: J5.1, J6.23
/Memory/A9: J5.3, J6.21
/Memory/A10: J5.5, J6.19
/Memory/A11: J5.8, J6.20
/Memory/A12: J5.9, J6.15
/Memory/A13: J5.11, J6.13
/Memory/A14: J5.14, J6.14
/Memory/A15: J5.15, J6.9
/Memory/BD0: J5.30, U1.5 (D1)
/Memory/BD1: J5.31, U3.4 (D0)
/Memory/BD2: J5.27, U3.13 (D3)
/Memory/BD3: J5.28, U3.12 (D2)
/Memory/BD4: J5.29, U1.4 (D0)
/Memory/BD5: J5.32, U3.5 (D1)
/Memory/BD6: J5.26, J6.2, U1.12 (D2)
/Memory/BD7: J5.25, U1.13 (D3)
/Memory/~IORQ: J5.22, J6.6
/Memory/~M1: J5.20, J6.8
/Memory/~MREQ: J5.19, J6.5
/Memory/~RD: J5.23, J6.1
/Memory/~RESOUT: J5.21, J6.3
/Memory/~RFSH: J5.17, J6.7
/Memory/~WR: J5.24, J6.4
BUC: U1.9 (Cp), U3.9 (Cp); also elsewhere on the board
FON: Z11.1; also elsewhere on the board
GND: C12.2, C13.2, C14.2, C17.2, C18.2, D2.2 (A), J7.3, T4.1 (Pin_1_1), U1.8 (GND), U2.4 (GND), U3.8 (GND); also elsewhere on the board
unnamed: C20.2, RV1.1
unnamed: D2.1 (K), RV1.2, RV1.3, T3.1 (Pin_1_1), Z10.1, Z10.2, Z11.2
unnamed: J12.1, J13.1
unnamed: J12.2, J13.2
unnamed: J12.3, J13.3
unnamed: J12.4, J13.4
unnamed: J12.5, J13.5
unnamed: J12.6, J13.6
unnamed: J12.7, J13.7
unnamed: J12.8, J13.8
unnamed: J12.9, J13.9
unnamed: J12.10, J13.10
unnamed: J12.11, J13.11
unnamed: J12.12, J13.12
unnamed: J12.13, J13.13
unnamed: J12.14, J13.14
unnamed: J12.15, J13.15
unnamed: J12.16, J13.16
unnamed: J12.17, J13.17
unnamed: J12.18, J13.18
unnamed: J12.19, J13.19
unnamed: J12.20, J13.20
unnamed: J12.21, J13.21
unnamed: J12.22, J13.22
unnamed: J12.23, J13.23
unnamed: J12.24, J13.24
unnamed: J12.25, J13.25
unnamed: J12.26, J13.26
unnamed: J12.27, J13.27
unnamed: J12.28, J13.28
unnamed: J12.29, J13.29
unnamed: J12.30, J13.30
unnamed: J12.31, J13.31
unnamed: J12.32, J13.32
unnamed: J14.1, J15.1
unnamed: J14.2, J15.2
unnamed: J14.3, J15.3
unnamed: J14.4, J15.4
unnamed: J14.5, J15.5
unnamed: J14.6, J15.6
unnamed: J14.7, J15.7
unnamed: J14.8, J15.8
unnamed: J14.9, J15.9
unnamed: J14.10, J15.10
unnamed: J14.11, J15.11
unnamed: J14.12, J15.12
unnamed: J14.13, J15.13
unnamed: J14.14, J15.14
unnamed: J14.15, J15.15
unnamed: J14.16, J15.16
unnamed: J14.17, J15.17
unnamed: J14.18, J15.18
unnamed: J14.19, J15.19
unnamed: J14.20, J15.20
unnamed: J14.21, J15.21
unnamed: J14.22, J15.22
unnamed: J14.23, J15.23
unnamed: J14.24, J15.24
unnamed: J14.25, J15.25
unnamed: J14.26, J15.26
unnamed: J14.27, J15.27
unnamed: J14.28, J15.28
unnamed: J14.29, J15.29
unnamed: J14.30, J15.30
unnamed: J14.31, J15.31
unnamed: J14.32, J15.32
unnamed: J16.1, J17.1
unnamed: J16.2, J17.2
unnamed: J16.3, J17.3
unnamed: J16.4, J17.4
unnamed: J16.5, J17.5
unnamed: J16.6, J17.6
unnamed: J16.7, J17.7
unnamed: J16.8, J17.8
unnamed: J16.9, J17.9
unnamed: J16.10, J17.10
unnamed: J16.11, J17.11
unnamed: J16.12, J17.12
unnamed: J16.13, J17.13
unnamed: J16.14, J17.14
unnamed: J16.15, J17.15
unnamed: J16.16, J17.16
unnamed: J16.17, J17.17
unnamed: J16.18, J17.18
unnamed: J16.19, J17.19
unnamed: J16.20, J17.20
unnamed: J16.21, J17.21
unnamed: J16.22, J17.22
unnamed: J16.23, J17.23
unnamed: J16.24, J17.24
unnamed: J16.25, J17.25
unnamed: J16.26, J17.26
unnamed: J16.27, J17.27
unnamed: J16.28, J17.28
unnamed: J16.29, J17.29
unnamed: J16.30, J17.30
unnamed: J16.31, J17.31
unnamed: J16.32, J17.32
unnamed: R1.1, T1.1 (Pin_1_1), U1.7 (Q1), U2.1 (1A), U2.2 (1B)
unnamed: T2.1 (Pin_1_1), U1.6 (~Q1)
unnamed: C20.1, R2.1, U2.3 (1Y)
PHI: J5.18, J6.10
R1K: U1.1 (~Mr), U3.1 (~Mr); also elsewhere on the board

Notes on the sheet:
B13
B12
A16
B15
A15
B16
A14
A13
A10
A12
B14

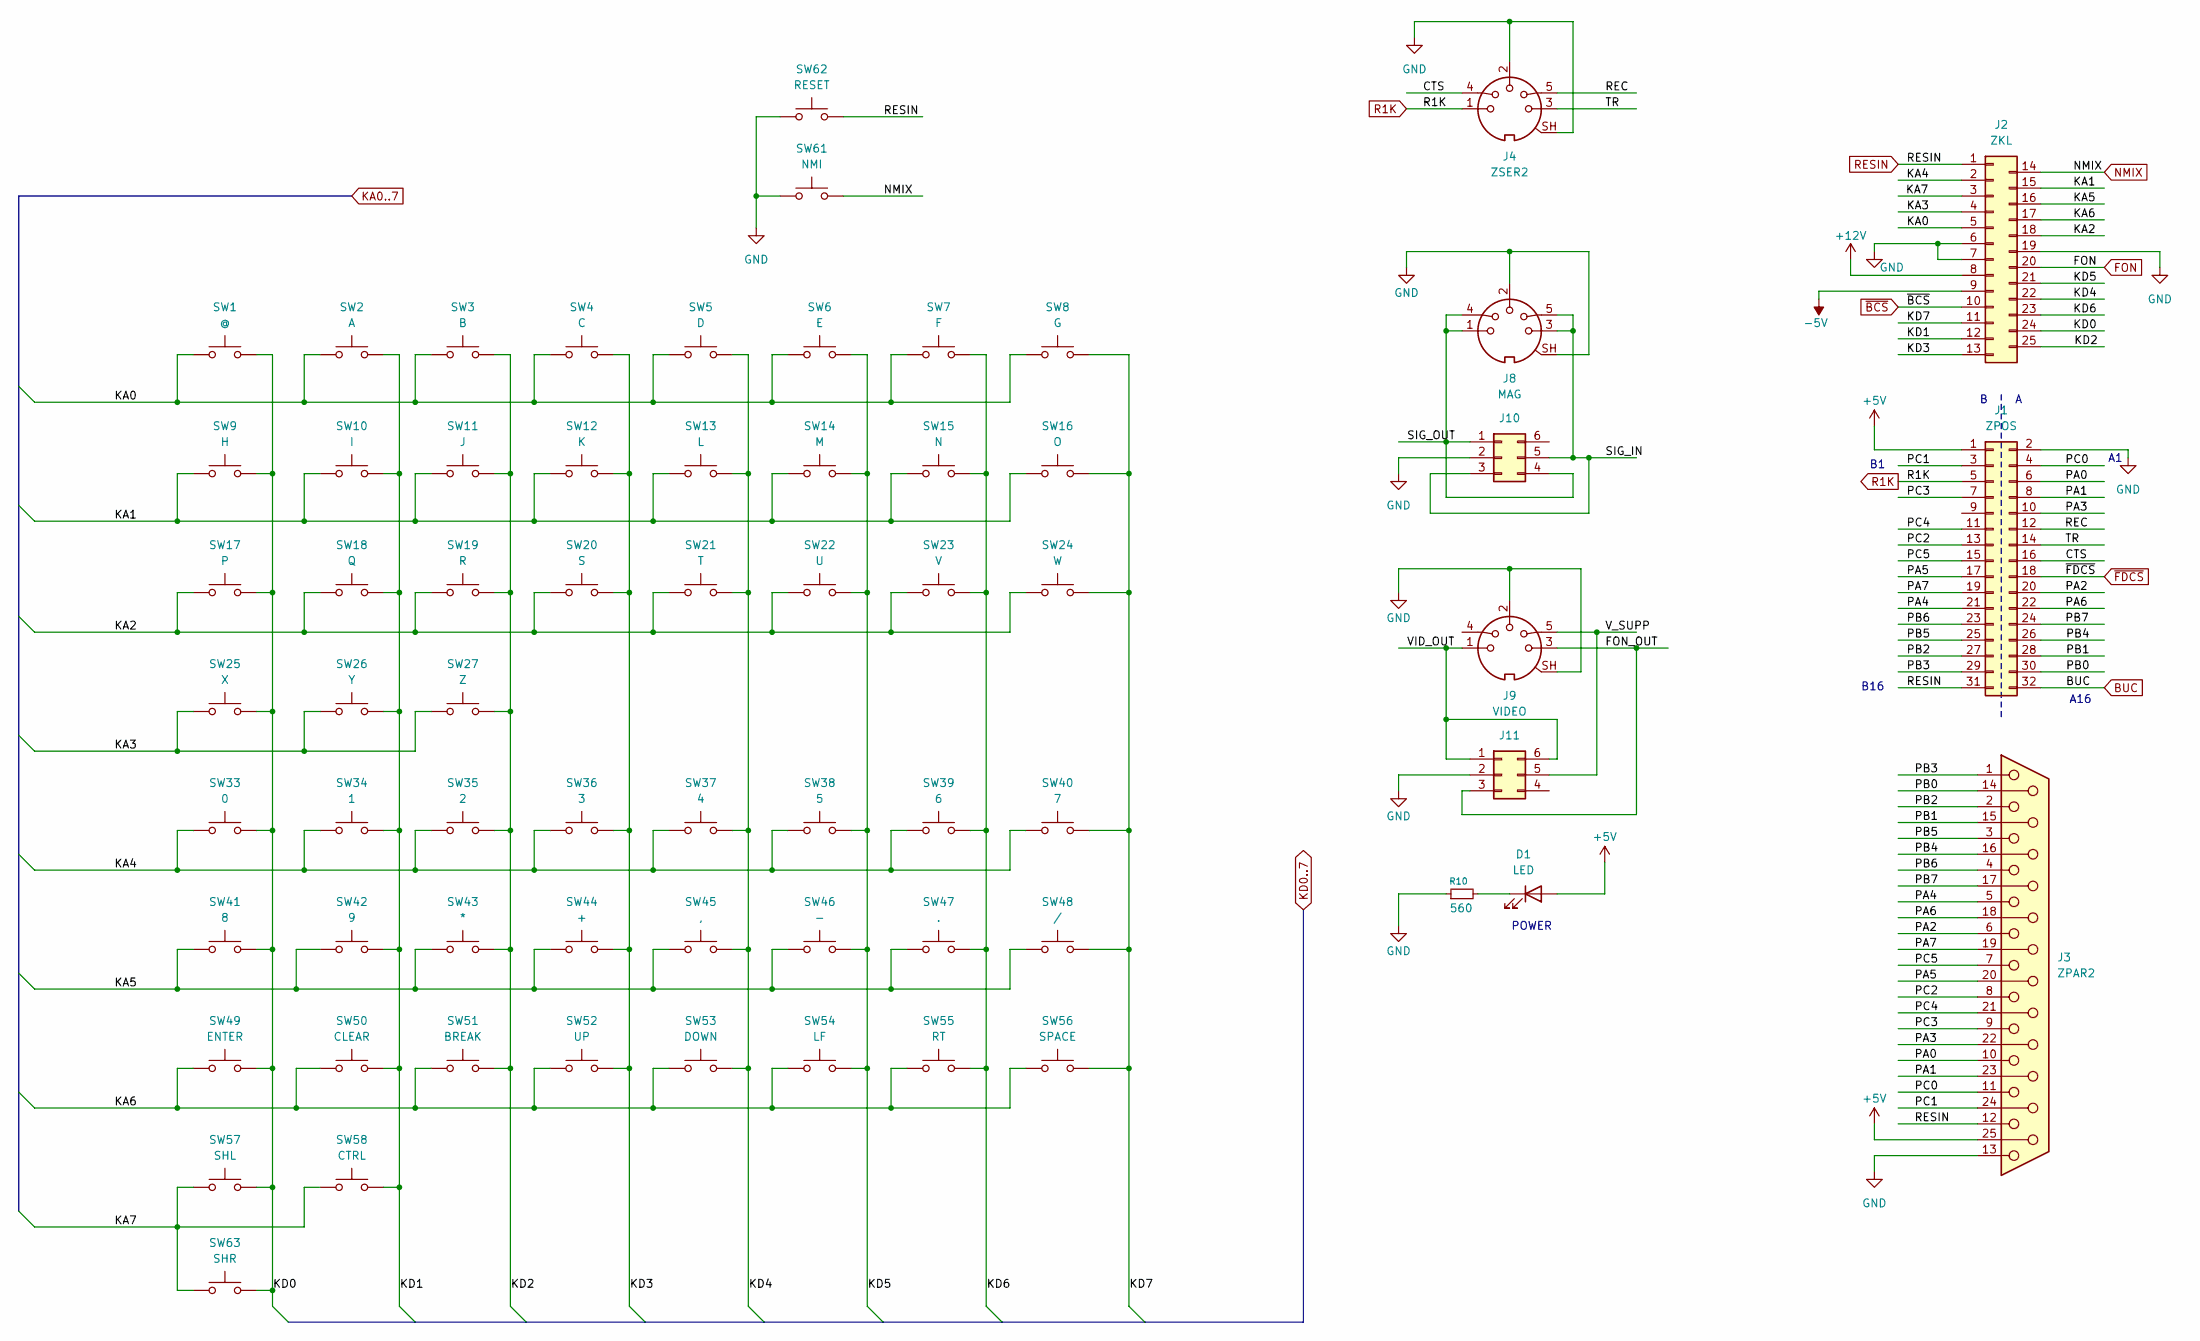
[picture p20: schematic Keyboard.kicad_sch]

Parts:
D1: LED; LED_D5.0mm
J1: ZPOS; PinHeader_2x16_P2.54mm_Vertical
J2: ZKL; PinSocket_25_P2.54mm_Vertical
J3: ZPAR2; DSUB-25_Socket_Horizontal_P2.77x2.84mm_EdgePinOffset7.70mm_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
J4: ZSER2; CUI_SDS-50J
J8: MAG; CUI_SDS-50J
J9: VIDEO; CUI_SDS-50J
J10, J11: Conn_02x03_Counter_Clockwise; PinHeader_2x03_P2.54mm_Vertical
R10: 560; r_400
SW1: @; SW_Cherry_MX_1.00u_PCB
SW2: A; SW_Cherry_MX_1.00u_PCB
SW3: B; SW_Cherry_MX_1.00u_PCB
SW4: C; SW_Cherry_MX_1.00u_PCB
SW5: D; SW_Cherry_MX_1.00u_PCB
SW6: E; SW_Cherry_MX_1.00u_PCB
SW7: F; SW_Cherry_MX_1.00u_PCB
SW8: G; SW_Cherry_MX_1.00u_PCB
SW9: H; SW_Cherry_MX_1.00u_PCB
SW10: I; SW_Cherry_MX_1.00u_PCB
SW11: J; SW_Cherry_MX_1.00u_PCB
SW12: K; SW_Cherry_MX_1.00u_PCB
SW13: L; SW_Cherry_MX_1.00u_PCB
SW14: M; SW_Cherry_MX_1.00u_PCB
SW15: N; SW_Cherry_MX_1.00u_PCB
SW16: O; SW_Cherry_MX_1.00u_PCB
SW17: P; SW_Cherry_MX_1.00u_PCB
SW18: Q; SW_Cherry_MX_1.00u_PCB
SW19: R; SW_Cherry_MX_1.00u_PCB
SW20: S; SW_Cherry_MX_1.00u_PCB
SW21: T; SW_Cherry_MX_1.00u_PCB
SW22: U; SW_Cherry_MX_1.00u_PCB
SW23: V; SW_Cherry_MX_1.00u_PCB
SW24: W; SW_Cherry_MX_1.00u_PCB
SW25: X; SW_Cherry_MX_1.00u_PCB
SW26: Y; SW_Cherry_MX_1.00u_PCB
SW27: Z; SW_Cherry_MX_1.00u_PCB
SW33: 0; SW_Cherry_MX_1.00u_PCB
SW34: 1; SW_Cherry_MX_1.00u_PCB
SW35: 2; SW_Cherry_MX_1.00u_PCB
SW36: 3; SW_Cherry_MX_1.00u_PCB
SW37: 4; SW_Cherry_MX_1.00u_PCB
SW38: 5; SW_Cherry_MX_1.00u_PCB
SW39: 6; SW_Cherry_MX_1.00u_PCB
SW40: 7; SW_Cherry_MX_1.00u_PCB
SW41: 8; SW_Cherry_MX_1.00u_PCB
SW42: 9; SW_Cherry_MX_1.00u_PCB
SW43: *; SW_Cherry_MX_1.00u_PCB
SW44: +; SW_Cherry_MX_1.00u_PCB
SW45: ,; SW_Cherry_MX_1.00u_PCB
SW46: -; SW_Cherry_MX_1.00u_PCB
SW47: .; SW_Cherry_MX_1.00u_PCB
SW48: /; SW_Cherry_MX_1.00u_PCB
SW49: ENTER; SW_Cherry_MX_1.50u_PCB
SW50: CLEAR; SW_Cherry_MX_1.00u_PCB
SW51: BREAK; SW_Cherry_MX_1.00u_PCB
SW52: UP; SW_Cherry_MX_1.00u_PCB
SW53: DOWN; SW_Cherry_MX_1.00u_PCB
SW54: LF; SW_Cherry_MX_1.00u_PCB
SW55: RT; SW_Cherry_MX_1.00u_PCB
SW56: SPACE; SW_Cherry_MX_6.25u_PCB
SW57: SHL; SW_Cherry_MX_1.00u_PCB
SW58: CTRL; SW_Cherry_MX_1.50u_PCB
SW61: NMI; SW_Cherry_MX_1.00u_PCB
SW62: RESET; SW_Push_2P2T_Toggle_CK_PVA2OAH5xxxxxxV2
SW63: SHR; SW_Cherry_MX_1.00u_PCB

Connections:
+5V: D1.2 (A), J1.1, J3.25; also elsewhere on the board
+12V: J2.8; also elsewhere on the board
-5V: J2.9; also elsewhere on the board
/Keyboard/CTS: J1.16, J4.4
/Keyboard/FON_OUT: J9.3, J11.3
/Keyboard/KA0: J2.5, SW1.1, SW2.1, SW3.1, SW4.1, SW5.1, SW6.1, SW7.1, SW8.1
/Keyboard/KA1: J2.15, SW9.1, SW10.1, SW11.1, SW12.1, SW13.1, SW14.1, SW15.1, SW16.1
/Keyboard/KA2: J2.18, SW17.1, SW18.1, SW19.1, SW20.1, SW21.1, SW22.1, SW23.1, SW24.1
/Keyboard/KA3: J2.4, SW25.1, SW26.1, SW27.1
/Keyboard/KA4: J2.2, SW33.1, SW34.1, SW35.1, SW36.1, SW37.1, SW38.1, SW39.1, SW40.1
/Keyboard/KA5: J2.16, SW41.1, SW42.1, SW43.1, SW44.1, SW45.1, SW46.1, SW47.1, SW48.1
/Keyboard/KA6: J2.17, SW49.1, SW50.1, SW51.1, SW52.1, SW53.1, SW54.1, SW55.1, SW56.1
/Keyboard/KA7: J2.3, SW57.1, SW58.1, SW63.1
/Keyboard/KD0: J2.24, SW1.2, SW9.2, SW17.2, SW25.2, SW33.2, SW41.2, SW49.2, SW57.2, SW63.2
/Keyboard/KD1: J2.12, SW2.2, SW10.2, SW18.2, SW26.2, SW34.2, SW42.2, SW50.2, SW58.2
/Keyboard/KD2: J2.25, SW3.2, SW11.2, SW19.2, SW27.2, SW35.2, SW43.2, SW51.2
/Keyboard/KD3: J2.13, SW4.2, SW12.2, SW20.2, SW36.2, SW44.2, SW52.2
/Keyboard/KD4: J2.22, SW5.2, SW13.2, SW21.2, SW37.2, SW45.2, SW53.2
/Keyboard/KD5: J2.21, SW6.2, SW14.2, SW22.2, SW38.2, SW46.2, SW54.2
/Keyboard/KD6: J2.23, SW7.2, SW15.2, SW23.2, SW39.2, SW47.2, SW55.2
/Keyboard/KD7: J2.11, SW8.2, SW16.2, SW24.2, SW40.2, SW48.2, SW56.2
/Keyboard/PA0: J1.6, J3.10
/Keyboard/PA1: J1.8, J3.23
/Keyboard/PA2: J1.20, J3.6
/Keyboard/PA3: J1.10, J3.22
/Keyboard/PA4: J1.21, J3.5
/Keyboard/PA5: J1.17, J3.20
/Keyboard/PA6: J1.22, J3.18
/Keyboard/PA7: J1.19, J3.19
/Keyboard/PB0: J1.30, J3.14
/Keyboard/PB1: J1.28, J3.15
/Keyboard/PB2: J1.27, J3.2
/Keyboard/PB3: J1.29, J3.1
/Keyboard/PB4: J1.26, J3.16
/Keyboard/PB5: J1.25, J3.3
/Keyboard/PB6: J1.23, J3.4
/Keyboard/PB7: J1.24, J3.17
/Keyboard/PC0: J1.4, J3.11
/Keyboard/PC1: J1.3, J3.24
/Keyboard/PC2: J1.13, J3.8
/Keyboard/PC3: J1.7, J3.9
/Keyboard/PC4: J1.11, J3.21
/Keyboard/PC5: J1.15, J3.7
/Keyboard/REC: J1.12, J4.5
/Keyboard/SIG_IN: J8.3, J8.5, J10.3, J10.5
/Keyboard/SIG_OUT: J8.1, J8.4, J10.1, J10.4
/Keyboard/TR: J1.14, J4.3
/Keyboard/VID_OUT: J9.1, J11.1, J11.6
/Keyboard/V_SUPP: J9.5, J11.5
BUC: J1.32; also elsewhere on the board
FON: J2.20; also elsewhere on the board
GND: J1.2, J2.6, J2.7, J2.19, J3.13, J4.2, J4.SH, J8.2, J8.SH, J9.2, J9.SH, J10.2, J11.2, R10.1, SW61.1, SW62.1; also elsewhere on the board
NMIX: J2.14, SW61.2
unnamed: D1.1 (K), R10.2
R1K: J1.5, J4.1; also elsewhere on the board
RESIN: J1.31, J2.1, J3.12, SW62.2
~BCS: J2.10
~FDCS: J1.18

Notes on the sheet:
POWER
B16
A16

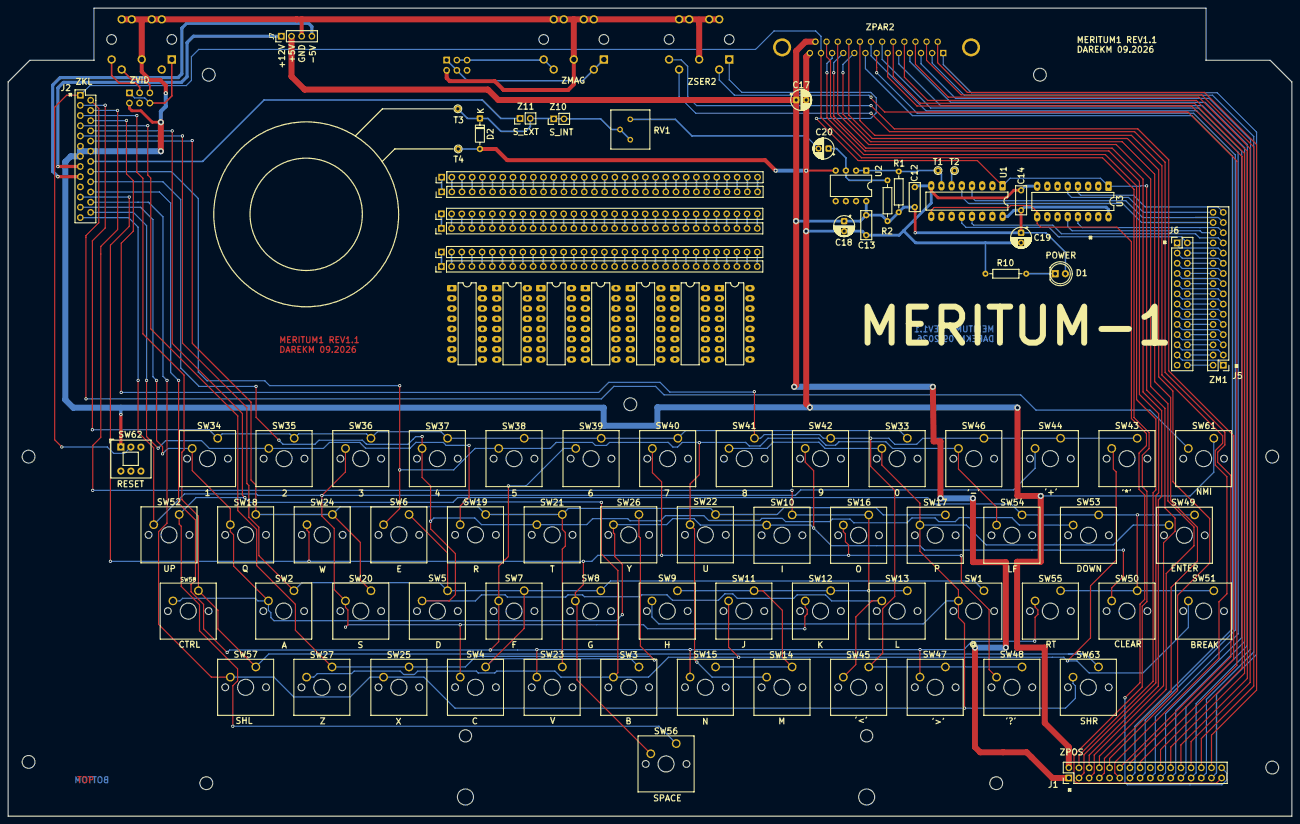
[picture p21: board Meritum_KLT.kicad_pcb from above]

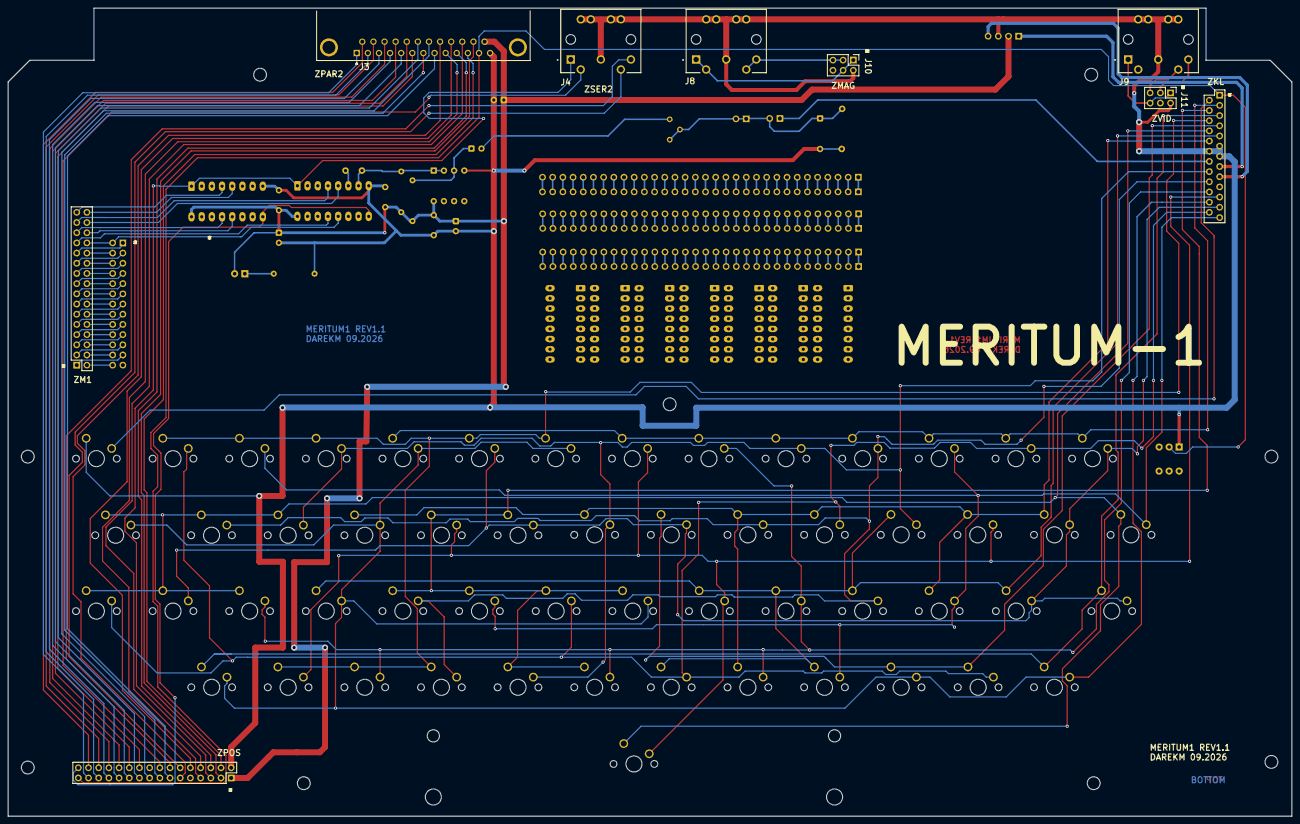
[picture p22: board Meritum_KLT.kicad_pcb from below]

Board: 2 copper layers, 320.0 x 201.4 mm, 95 parts (6 on the bottom side), 189 nets.

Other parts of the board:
C19: 100uF; CP_Radial_D5.0mm_P2.50mm

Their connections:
+5V: C19.1; also elsewhere on the board
GND: C19.2; also elsewhere on the board

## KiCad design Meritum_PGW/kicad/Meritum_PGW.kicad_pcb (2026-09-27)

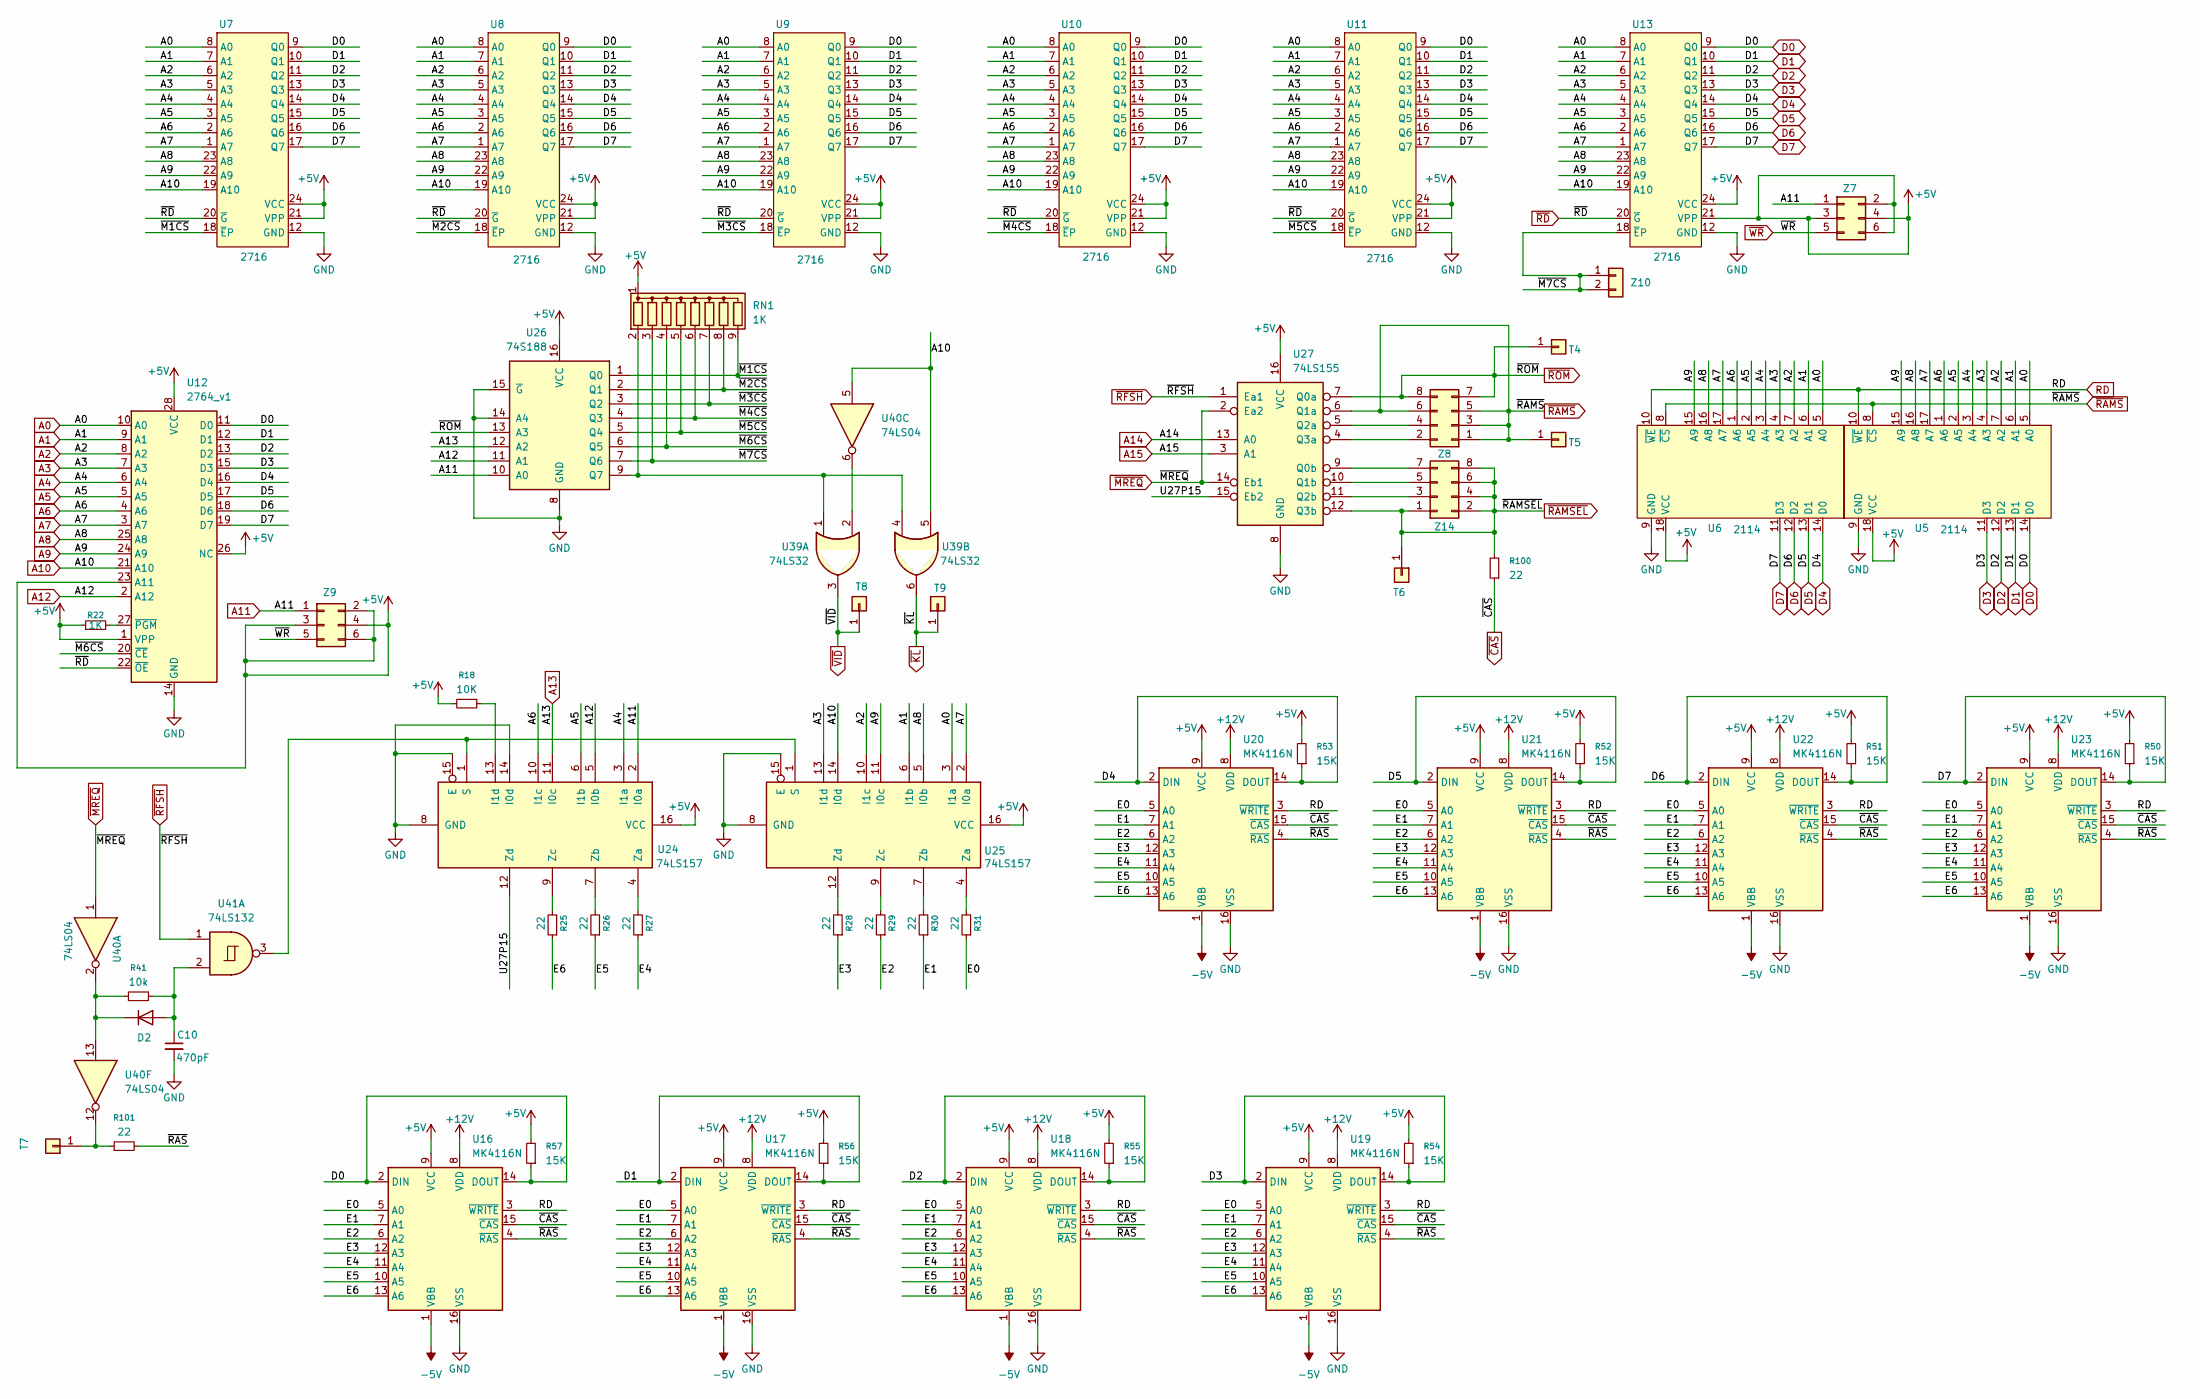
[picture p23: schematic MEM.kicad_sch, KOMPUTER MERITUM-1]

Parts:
C10: 470pF; c_100
D2: 1N4148; D_DO-35_SOD27_P10.16mm_Horizontal
R18: 10K; r_400
R22: 1K; R_Axial_DIN0207_L6.3mm_D2.5mm_P2.54mm_Vertical
R25, R26, R27, R28, R29, R30, R31, R100, R101: 22; r_400
R41: 10k; r_400
R50, R51, R52, R53, R54, R55, R56, R57: 15K; R_Axial_DIN0207_L6.3mm_D2.5mm_P2.54mm_Vertical
RN1: 1K; R_Array_SIP9
T4, T5, T6, T7, T8, T9: T18; pin
U5, U6: 2114; DIP-18_W7.62mm_Socket_LongPads
U7, U8, U9, U10, U11, U13: 2716; DIP-24_W15.24mm_LongPads
U12: 2764_v1; DIP-28_W15.24mm_LongPads
U16, U17, U18, U19, U20, U21, U22, U23: MK4116N; DIP-16_W7.62mm_LongPads
U24, U25: 74LS157; DIP-16_W7.62mm_LongPads
U26: 74S188; DIP-16_W7.62mm_LongPads
U27: 74LS155; DIP-16_W7.62mm_LongPads
U39: 74LS32; DIP-14_W7.62mm_LongPads
U40: 74LS04; DIP-14_W7.62mm_LongPads
U41: 74LS132; DIP-14_W7.62mm_LongPads
Z7: Z3; PinHeader_2x03_P2.54mm_Vertical
Z8, Z14: Conn_02x04_Odd_Even; PinHeader_2x04_P2.54mm_Vertical
Z9: Z4; PinHeader_2x03_P2.54mm_Vertical
Z10: Conn_01x02; PinHeader_1x02_P2.54mm_Vertical

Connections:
+5V: R18.2, R22.1, R50.2, R51.2, R52.2, R53.2, R54.2, R55.2, R56.2, R57.2, RN1.1 (common), U5.18 (VCC), U6.18 (VCC), U7.21 (VPP), U7.24 (VCC), U8.21 (VPP), U8.24 (VCC), U9.21 (VPP), U9.24 (VCC), U10.21 (VPP), U10.24 (VCC), U11.21 (VPP), U11.24 (VCC), U12.1 (VPP), U12.23 (A11), U12.26 (NC), U12.28 (VCC), U13.21 (VPP), U13.24 (VCC), U16.9 (VCC), U17.9 (VCC), U18.9 (VCC), U19.9 (VCC), U20.9 (VCC), U21.9 (VCC), U22.9 (VCC), U23.9 (VCC), U24.16 (VCC), U25.16 (VCC), U26.16 (VCC), U27.16 (VCC), Z7.2, Z7.3, Z7.4, Z7.6, Z9.2, Z9.3, Z9.4, Z9.6; also elsewhere on the board
+12V: U16.8 (VDD), U17.8 (VDD), U18.8 (VDD), U19.8 (VDD), U20.8 (VDD), U21.8 (VDD), U22.8 (VDD), U23.8 (VDD); also elsewhere on the board
-5V: U16.1 (VBB), U17.1 (VBB), U18.1 (VBB), U19.1 (VBB), U20.1 (VBB), U21.1 (VBB), U22.1 (VBB), U23.1 (VBB); also elsewhere on the board
/MEM/E0: R31.1, U16.5 (A0), U17.5 (A0), U18.5 (A0), U19.5 (A0), U20.5 (A0), U21.5 (A0), U22.5 (A0), U23.5 (A0)
/MEM/E1: R30.1, U16.7 (A1), U17.7 (A1), U18.7 (A1), U19.7 (A1), U20.7 (A1), U21.7 (A1), U22.7 (A1), U23.7 (A1)
/MEM/E2: R29.1, U16.6 (A2), U17.6 (A2), U18.6 (A2), U19.6 (A2), U20.6 (A2), U21.6 (A2), U22.6 (A2), U23.6 (A2)
/MEM/E3: R28.1, U16.12 (A3), U17.12 (A3), U18.12 (A3), U19.12 (A3), U20.12 (A3), U21.12 (A3), U22.12 (A3), U23.12 (A3)
/MEM/E4: R27.1, U16.11 (A4), U17.11 (A4), U18.11 (A4), U19.11 (A4), U20.11 (A4), U21.11 (A4), U22.11 (A4), U23.11 (A4)
/MEM/E5: R26.1, U16.10 (A5), U17.10 (A5), U18.10 (A5), U19.10 (A5), U20.10 (A5), U21.10 (A5), U22.10 (A5), U23.10 (A5)
/MEM/E6: R25.1, U16.13 (A6), U17.13 (A6), U18.13 (A6), U19.13 (A6), U20.13 (A6), U21.13 (A6), U22.13 (A6), U23.13 (A6)
/MEM/U27P15: U24.12 (Zd), U27.15 (Eb2)
/MEM/~M1CS: RN1.9 (R8), U7.18 (~EP), U26.1 (Q0)
/MEM/~M2CS: RN1.8 (R7), U8.18 (~EP), U26.2 (Q1)
/MEM/~M3CS: RN1.7 (R6), U9.18 (~EP), U26.3 (Q2)
/MEM/~M4CS: RN1.6 (R5), U10.18 (~EP), U26.4 (Q3)
/MEM/~M5CS: RN1.5 (R4), U11.18 (~EP), U26.5 (Q4)
/MEM/~M6CS: RN1.4 (R3), U12.20 (~CE), U26.6 (Q5)
/MEM/~M7CS: RN1.3 (R2), U13.18 (~EP), U26.7 (Q6), Z10.1, Z10.2
/MEM/~RAS: R101.2, U16.4 (~RAS), U17.4 (~RAS), U18.4 (~RAS), U19.4 (~RAS), U20.4 (~RAS), U21.4 (~RAS), U22.4 (~RAS), U23.4 (~RAS)
A0: U5.5 (A0), U6.5 (A0), U7.8 (A0), U8.8 (A0), U9.8 (A0), U10.8 (A0), U11.8 (A0), U12.10 (A0), U13.8 (A0), U25.3 (I1a); also elsewhere on the board
A1: U5.6 (A1), U6.6 (A1), U7.7 (A1), U8.7 (A1), U9.7 (A1), U10.7 (A1), U11.7 (A1), U12.9 (A1), U13.7 (A1), U25.6 (I1b); also elsewhere on the board
A2: U5.7 (A2), U6.7 (A2), U7.6 (A2), U8.6 (A2), U9.6 (A2), U10.6 (A2), U11.6 (A2), U12.8 (A2), U13.6 (A2), U25.10 (I1c); also elsewhere on the board
A3: U5.4 (A3), U6.4 (A3), U7.5 (A3), U8.5 (A3), U9.5 (A3), U10.5 (A3), U11.5 (A3), U12.7 (A3), U13.5 (A3), U25.13 (I1d); also elsewhere on the board
A4: U5.3 (A4), U6.3 (A4), U7.4 (A4), U8.4 (A4), U9.4 (A4), U10.4 (A4), U11.4 (A4), U12.6 (A4), U13.4 (A4), U24.3 (I1a); also elsewhere on the board
A5: U5.2 (A5), U6.2 (A5), U7.3 (A5), U8.3 (A5), U9.3 (A5), U10.3 (A5), U11.3 (A5), U12.5 (A5), U13.3 (A5), U24.6 (I1b); also elsewhere on the board
A6: U5.1 (A6), U6.1 (A6), U7.2 (A6), U8.2 (A6), U9.2 (A6), U10.2 (A6), U11.2 (A6), U12.4 (A6), U13.2 (A6), U24.10 (I1c); also elsewhere on the board
A7: U5.17 (A7), U6.17 (A7), U7.1 (A7), U8.1 (A7), U9.1 (A7), U10.1 (A7), U11.1 (A7), U12.3 (A7), U13.1 (A7), U25.2 (I0a); also elsewhere on the board
A8: U5.16 (A8), U6.16 (A8), U7.23 (A8), U8.23 (A8), U9.23 (A8), U10.23 (A8), U11.23 (A8), U12.25 (A8), U13.23 (A8), U25.5 (I0b); also elsewhere on the board
A9: U5.15 (A9), U6.15 (A9), U7.22 (A9), U8.22 (A9), U9.22 (A9), U10.22 (A9), U11.22 (A9), U12.24 (A9), U13.22 (A9), U25.11 (I0c); also elsewhere on the board
A10: U7.19 (A10), U8.19 (A10), U9.19 (A10), U10.19 (A10), U11.19 (A10), U12.21 (A10), U13.19 (A10), U25.14 (I0d), U39.5, U40.5; also elsewhere on the board
A11: U24.2 (I0a), U26.10 (A0), Z7.1, Z9.1; also elsewhere on the board
A12: U12.2 (A12), U24.5 (I0b), U26.11 (A1); also elsewhere on the board
A13: U24.11 (I0c), U26.12 (A2); also elsewhere on the board
A14: U27.13 (A0); also elsewhere on the board
A15: U27.3 (A1); also elsewhere on the board
BD0: R57.1, U5.14 (D0), U7.9 (Q0), U8.9 (Q0), U9.9 (Q0), U10.9 (Q0), U11.9 (Q0), U12.11 (D0), U13.9 (Q0), U16.2 (DIN), U16.14 (DOUT); also elsewhere on the board
D1: R56.1, U5.13 (D1), U7.10 (Q1), U8.10 (Q1), U9.10 (Q1), U10.10 (Q1), U11.10 (Q1), U12.12 (D1), U13.10 (Q1), U17.2 (DIN), U17.14 (DOUT); also elsewhere on the board
D2: R55.1, U5.12 (D2), U7.11 (Q2), U8.11 (Q2), U9.11 (Q2), U10.11 (Q2), U11.11 (Q2), U12.13 (D2), U13.11 (Q2), U18.2 (DIN), U18.14 (DOUT); also elsewhere on the board
D3: R54.1, U5.11 (D3), U7.13 (Q3), U8.13 (Q3), U9.13 (Q3), U10.13 (Q3), U11.13 (Q3), U12.15 (D3), U13.13 (Q3), U19.2 (DIN), U19.14 (DOUT); also elsewhere on the board
D4: R53.1, U6.14 (D0), U7.14 (Q4), U8.14 (Q4), U9.14 (Q4), U10.14 (Q4), U11.14 (Q4), U12.16 (D4), U13.14 (Q4), U20.2 (DIN), U20.14 (DOUT); also elsewhere on the board
D5: R52.1, U6.13 (D1), U7.15 (Q5), U8.15 (Q5), U9.15 (Q5), U10.15 (Q5), U11.15 (Q5), U12.17 (D5), U13.15 (Q5), U21.2 (DIN), U21.14 (DOUT); also elsewhere on the board
D6: R51.1, U6.12 (D2), U7.16 (Q6), U8.16 (Q6), U9.16 (Q6), U10.16 (Q6), U11.16 (Q6), U12.18 (D6), U13.16 (Q6), U22.2 (DIN), U22.14 (DOUT); also elsewhere on the board
D7: R50.1, U6.11 (D3), U7.17 (Q7), U8.17 (Q7), U9.17 (Q7), U10.17 (Q7), U11.17 (Q7), U12.19 (D7), U13.17 (Q7), U23.2 (DIN), U23.14 (DOUT); also elsewhere on the board
GND: C10.2, U5.9 (GND), U6.9 (GND), U7.12 (GND), U8.12 (GND), U9.12 (GND), U10.12 (GND), U11.12 (GND), U12.14 (GND), U13.12 (GND), U16.16 (VSS), U17.16 (VSS), U18.16 (VSS), U19.16 (VSS), U20.16 (VSS), U21.16 (VSS), U22.16 (VSS), U23.16 (VSS), U24.8 (GND), U24.14 (I0d), U24.15 (E), U25.8 (GND), U25.15 (E), U26.8 (GND), U26.14 (A4), U26.15 (~G), U27.8 (GND); also elsewhere on the board
unnamed: C10.1, D2.2 (A), R41.2, U41.2
unnamed: D2.1 (K), R41.1, U40.2, U40.13
unnamed: RN1.2 (R1), U26.9 (Q7), U39.1, U39.4
unnamed: R101.1, T7.1 (Pin_1_1), U40.12
unnamed: R22.2, U12.27 (~PGM)
unnamed: R18.1, U24.13 (I1d)
unnamed: U24.1 (S), U25.1 (S), U41.3
unnamed: R27.2, U24.4 (Za)
unnamed: R26.2, U24.7 (Zb)
unnamed: R25.2, U24.9 (Zc)
unnamed: R31.2, U25.4 (Za)
unnamed: R30.2, U25.7 (Zb)
unnamed: R29.2, U25.9 (Zc)
unnamed: R28.2, U25.12 (Zd)
unnamed: U27.9 (Q0b), Z14.7
unnamed: U27.10 (Q1b), Z14.5
unnamed: U27.5 (Q2a), Z8.4
unnamed: U27.11 (Q2b), Z14.3
unnamed: U27.4 (Q3a), Z8.2
unnamed: U39.2, U40.6
RD: U5.10 (~WE), U6.10 (~WE), U16.3 (~WRITE), U17.3 (~WRITE), U18.3 (~WRITE), U19.3 (~WRITE), U20.3 (~WRITE), U21.3 (~WRITE), U22.3 (~WRITE), U23.3 (~WRITE); also elsewhere on the board
~CAS: R100.1, U16.15 (~CAS), U17.15 (~CAS), U18.15 (~CAS), U19.15 (~CAS), U20.15 (~CAS), U21.15 (~CAS), U22.15 (~CAS), U23.15 (~CAS)
~KL: T9.1 (Pin_1_1), U39.6; also elsewhere on the board
~MREQ: U27.2 (Ea2), U27.14 (Eb1), U40.1; also elsewhere on the board
~RAMSEL: R100.2, T6.1 (Pin_1_1), U27.12 (Q3b), Z14.1, Z14.2, Z14.4, Z14.6, Z14.8; also elsewhere on the board
~RAMS: T5.1 (Pin_1_1), U5.8 (~CS), U6.8 (~CS), U27.6 (Q1a), Z8.1, Z8.3, Z8.5, Z8.6; also elsewhere on the board
~RD: U7.20 (~G), U8.20 (~G), U9.20 (~G), U10.20 (~G), U11.20 (~G), U12.22 (~OE), U13.20 (~G); also elsewhere on the board
~RFSH: U27.1 (Ea1), U41.1; also elsewhere on the board
~ROM: T4.1 (Pin_1_1), U26.13 (A3), U27.7 (Q0a), Z8.7, Z8.8; also elsewhere on the board
~VID: T8.1 (Pin_1_1), U39.3; also elsewhere on the board
~WR: Z7.5, Z9.5; also elsewhere on the board

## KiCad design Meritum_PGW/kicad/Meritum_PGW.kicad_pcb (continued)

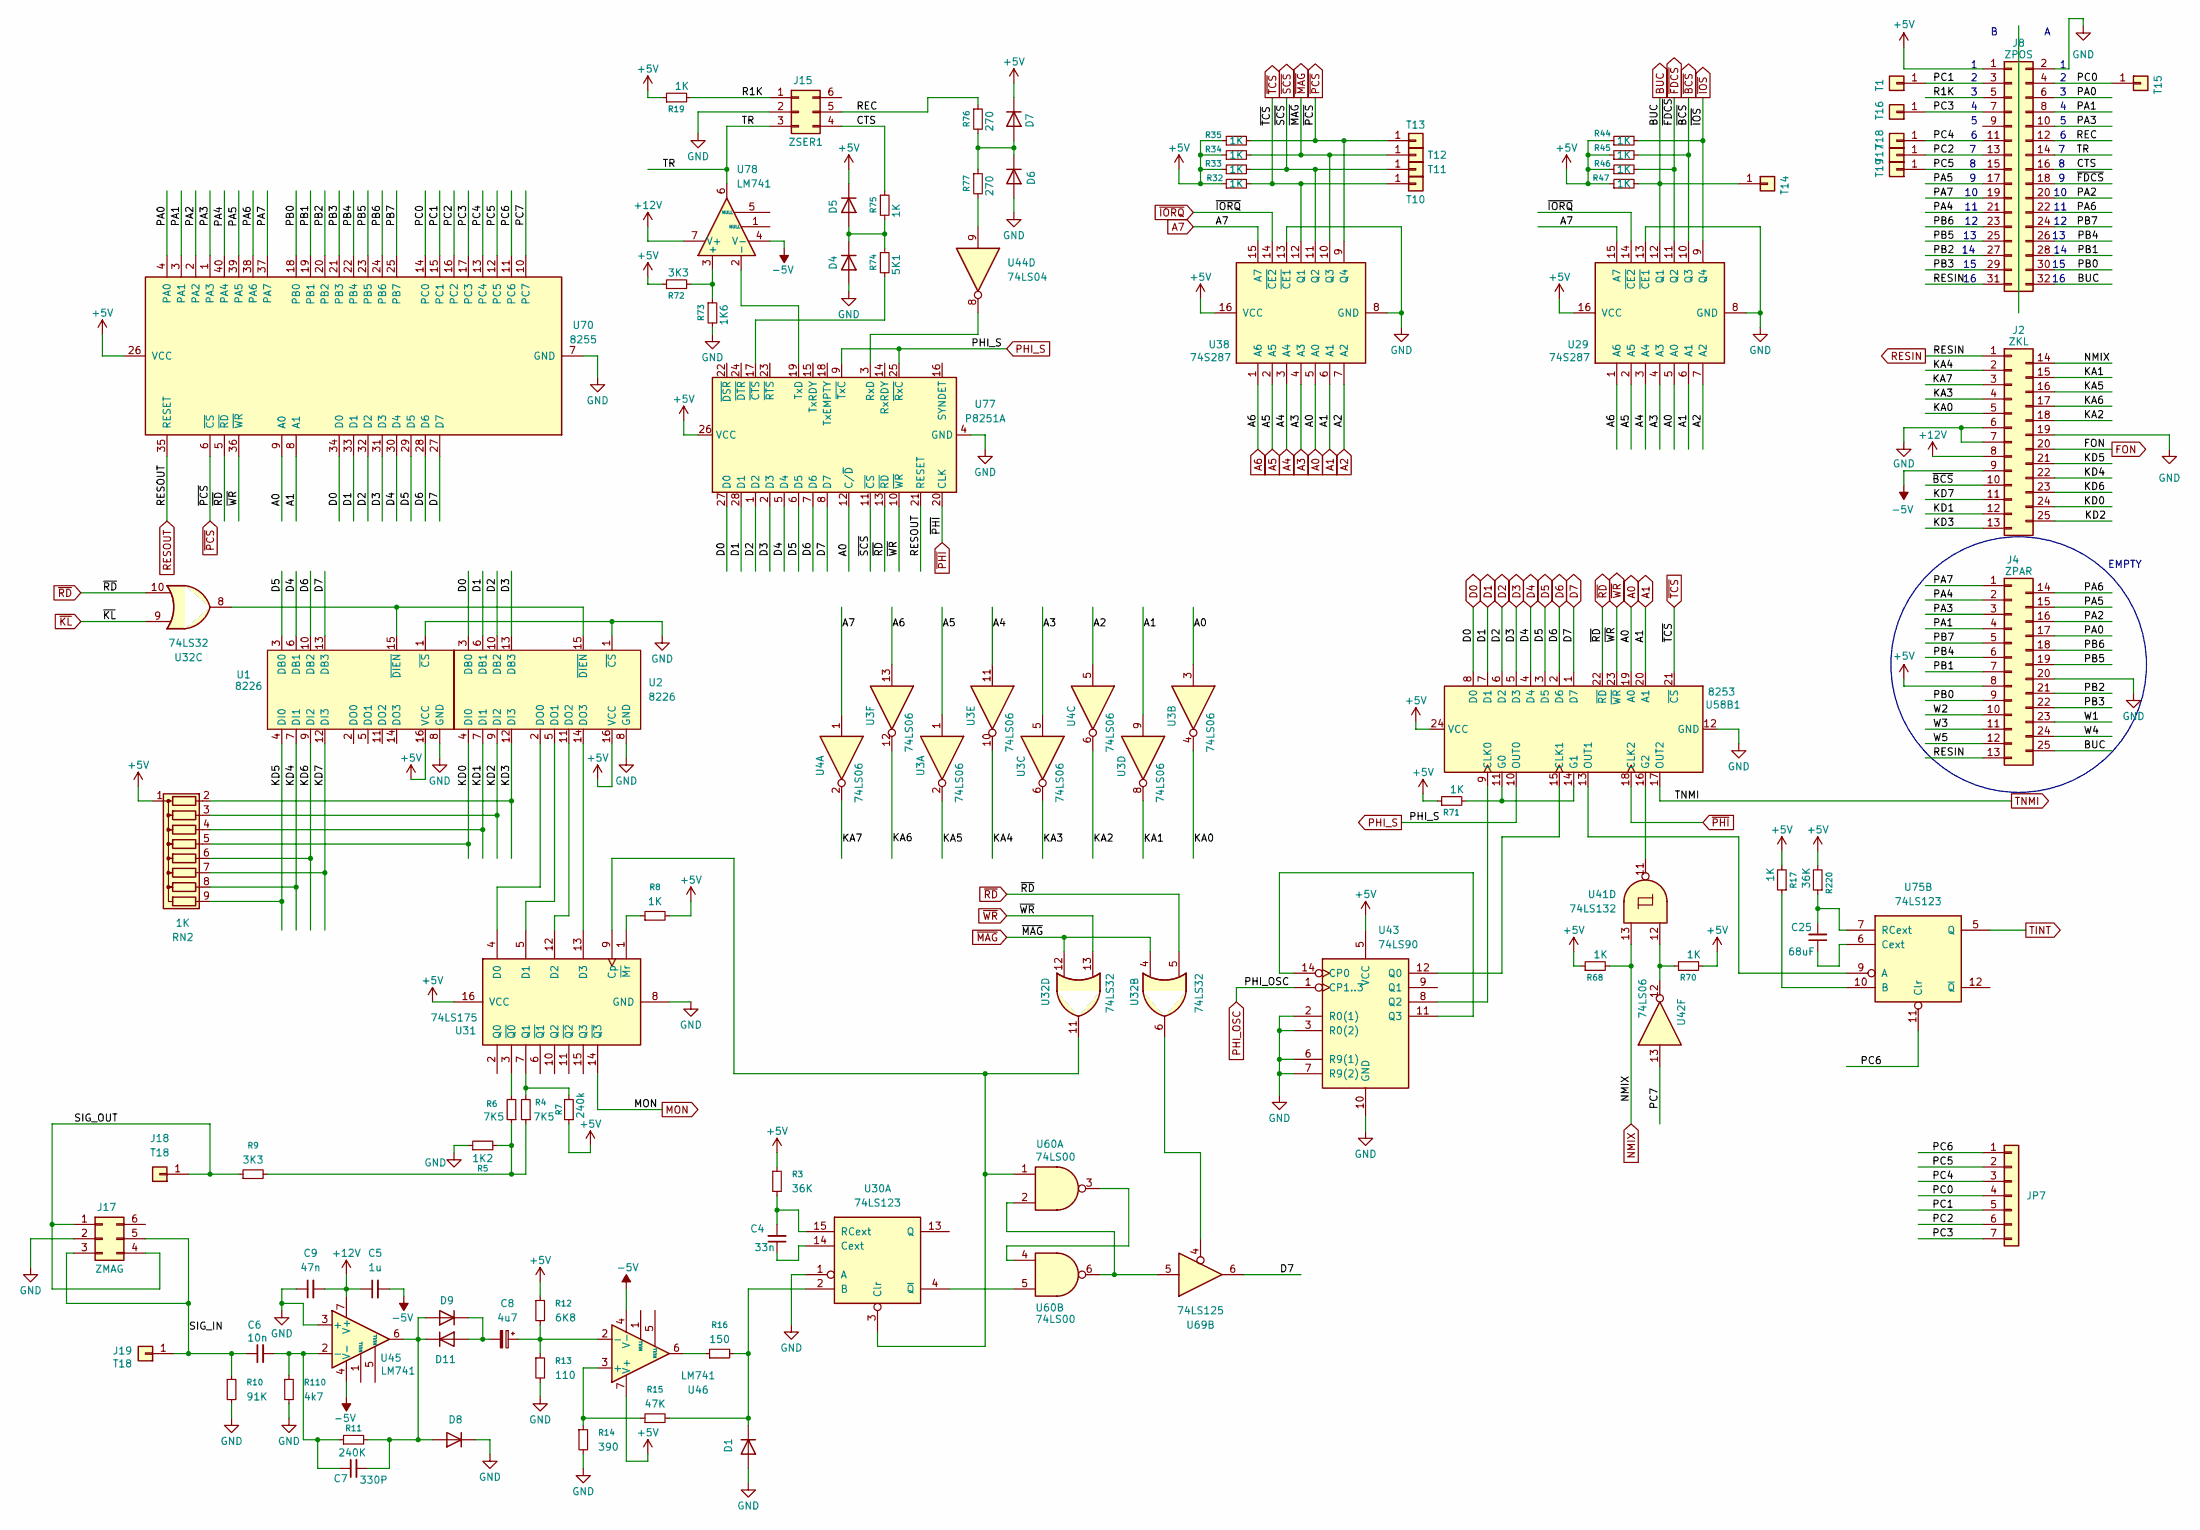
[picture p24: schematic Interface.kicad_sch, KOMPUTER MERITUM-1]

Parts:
C4: 33n; c_200
C5: 1u; c_200
C6: 10n; C_Rect_L4.0mm_W2.5mm_P2.50mm
C7: 330P; c_100
C8: 4u7; c_200
C9: 47n; c_200
C25: 68uF; CP_Radial_D5.0mm_P2.50mm
D1: 1N4148; D_DO-35_SOD27_P10.16mm_Horizontal
D4, D5: 1N4148WT; D_DO-35_SOD27_P2.54mm_Vertical_KathodeUp
D6, D7: 1N4148WT; D_DO-35_SOD27_P10.16mm_Horizontal
D8, D9, D11: 1N4148; D_DO-35_SOD27_P5.08mm_Vertical_AnodeUp
J2: ZKL; PinSocket_25_P2.54mm_Vertical
J4: ZPAR; PinSocket_25_P2.54mm_Vertical
J8: ZPOS; PinSocket_2x16_P2.54mm_Vertical_Meritum
J15: ZSER1; PinHeader_2x03_P2.54mm_Vertical
J17: ZMAG; PinHeader_2x03_P2.54mm_Vertical
J18, J19: T18; pin
JP7: Conn_01x07; PinHeader_1x07_P2.54mm_Vertical
R3, R220: 36K; r_400
R4, R6: 7K5; r_400
R5: 1K2; r_400
R7: 240k; r_400
R8, R17, R19, R32, R33, R34, R35, R44, R45, R46, R47, R68, R70, R75: 1K; r_400
R9, R72: 3K3; r_400
R10: 91K; R_Axial_DIN0207_L6.3mm_D2.5mm_P2.54mm_Vertical
R11: 240K; r_400
R12: 6K8; r_400
R13: 110; r_400
R14: 390; r_400
R15: 47K; r_400
R16: 150; r_400
R71: 1K; R_Axial_DIN0207_L6.3mm_D2.5mm_P2.54mm_Vertical
R73: 1K6; r_400
R74: 5K1; r_400
R76, R77: 270; r_400
R110: 4k7; R_Axial_DIN0207_L6.3mm_D2.5mm_P5.08mm_Vertical
RN2: 1K; R_Array_SIP9
T1, T10, T11, T12, T13, T14, T15, T16, T17, T18, T19: T18; pin
U1, U2: 8226; DIP-16_W7.62mm_LongPads
U3, U4, U42: 74LS06; DIP-14_W7.62mm_LongPads
U29, U38: 74S287; DIP-16_W7.62mm_LongPads
U30, U75: 74LS123; DIP-16_W7.62mm_LongPads
U31: 74LS175; DIP-16_W7.62mm_LongPads
U32: 74LS32; DIP-14_W7.62mm_LongPads
U41: 74LS132; DIP-14_W7.62mm_LongPads
U43: 74LS90; DIP-14_W7.62mm_LongPads
U44: 74LS04; DIP-14_W7.62mm_LongPads
U45, U46, U78: LM741; DIP-8_W7.62mm_LongPads
U58B1: 8253; DIP-24_W15.24mm_LongPads
U60: 74LS00; DIP-14_W7.62mm_LongPads
U69: 74LS125; DIP-14_W7.62mm_LongPads
U70: 8255; DIP-40_W15.24mm_LongPads
U77: P8251A; DIP-28_W15.24mm

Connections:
+5V: D5.1 (K), D7.1 (K), J4.8, J8.1, R3.1, R7.1, R8.2, R12.1, R17.2, R19.1, R32.1, R33.1, R34.1, R35.1, R44.1, R45.1, R46.1, R47.1, R68.1, R70.2, R71.1, R72.1, R220.2, RN2.1 (common), U1.16 (VCC), U2.16 (VCC), U29.16 (VCC), U31.16 (VCC), U38.16 (VCC), U43.5 (VCC), U46.7 (V+), U58B1.24 (VCC), U70.26 (VCC), U77.26 (VCC); also elsewhere on the board
+12V: C5.1, C9.2, J2.8, U45.7 (V+), U78.7 (V+); also elsewhere on the board
-5V: C5.2, J2.9, U45.4 (V-), U46.4 (V-), U78.4 (V-); also elsewhere on the board
/Interface/CTS: J8.16, J15.4, R75.1
/Interface/KA0: J2.5, U3.4
/Interface/KA1: J2.15, U3.8
/Interface/KA2: J2.18, U4.6
/Interface/KA3: J2.4, U3.6
/Interface/KA4: J2.2, U3.10
/Interface/KA5: J2.16, U3.2
/Interface/KA6: J2.17, U3.12
/Interface/KA7: J2.3, U4.2
/Interface/KD0: J2.24, RN2.5 (R4), U2.4 (DI0)
/Interface/KD1: J2.12, RN2.4 (R3), U2.7 (DI1)
/Interface/KD2: J2.25, RN2.3 (R2), U2.9 (DI2)
/Interface/KD3: J2.13, RN2.2 (R1), U2.12 (DI3)
/Interface/KD4: J2.22, RN2.8 (R7), U1.7 (DI1)
/Interface/KD5: J2.21, RN2.9 (R8), U1.4 (DI0)
/Interface/KD6: J2.23, RN2.6 (R5), U1.9 (DI2)
/Interface/KD7: J2.11, RN2.7 (R6), U1.12 (DI3)
/Interface/PA0: J4.17, J8.6, U70.4 (PA0)
/Interface/PA1: J4.4, J8.8, U70.3 (PA1)
/Interface/PA2: J4.16, J8.20, U70.2 (PA2)
/Interface/PA3: J4.3, J8.10, U70.1 (PA3)
/Interface/PA4: J4.2, J8.21, U70.40 (PA4)
/Interface/PA5: J4.15, J8.17, U70.39 (PA5)
/Interface/PA6: J4.14, J8.22, U70.38 (PA6)
/Interface/PA7: J4.1, J8.19, U70.37 (PA7)
/Interface/PB0: J4.9, J8.30, U70.18 (PB0)
/Interface/PB1: J4.7, J8.28, U70.19 (PB1)
/Interface/PB2: J4.21, J8.27, U70.20 (PB2)
/Interface/PB3: J4.22, J8.29, U70.21 (PB3)
/Interface/PB4: J4.6, J8.26, U70.22 (PB4)
/Interface/PB5: J4.19, J8.25, U70.23 (PB5)
/Interface/PB6: J4.18, J8.23, U70.24 (PB6)
/Interface/PB7: J4.5, J8.24, U70.25 (PB7)
/Interface/PC0: J8.4, JP7.4, T15.1 (Pin_1_1), U70.14 (PC0)
/Interface/PC1: J8.3, JP7.5, T1.1 (Pin_1_1), U70.15 (PC1)
/Interface/PC2: J8.13, JP7.6, T17.1 (Pin_1_1), U70.16 (PC2)
/Interface/PC3: J8.7, JP7.7, T16.1 (Pin_1_1), U70.17 (PC3)
/Interface/PC4: J8.11, JP7.3, T18.1 (Pin_1_1), U70.13 (PC4)
/Interface/PC5: J8.15, JP7.2, T19.1 (Pin_1_1), U70.12 (PC5)
/Interface/PC6: JP7.1, U70.11 (PC6), U75.11 (Clr)
/Interface/PC7: U42.13, U70.10 (PC7)
/Interface/R1K: J8.5, J15.1, R19.2
/Interface/REC: J8.12, J15.5, R76.1
/Interface/SIG_IN: C6.1, J17.3, J17.5, J19.1 (Pin_1_1), R10.1
/Interface/SIG_OUT: J17.1, J17.4, J18.1 (Pin_1_1), R9.1
/Interface/TR: J8.14, J15.3, U78.6
/Interface/W1: J4.23
/Interface/W2: J4.10
/Interface/W3: J4.11
/Interface/W4: J4.24
/Interface/W5: J4.12
A0: U3.3, U29.5 (A0), U38.5 (A0), U58B1.19 (A0), U70.9 (A0), U77.12 (C/~D); also elsewhere on the board
A1: U3.9, U29.6 (A1), U38.6 (A1), U58B1.20 (A1), U70.8 (A1); also elsewhere on the board
A2: U4.5, U29.7 (A2), U38.7 (A2); also elsewhere on the board
A3: U3.5, U29.4 (A3), U38.4 (A3); also elsewhere on the board
A4: U3.11, U29.3 (A4), U38.3 (A4); also elsewhere on the board
A5: U3.1, U29.2 (A5), U38.2 (A5); also elsewhere on the board
A6: U3.13, U29.1 (A6), U38.1 (A6); also elsewhere on the board
A7: U4.1, U29.15 (A7), U38.15 (A7); also elsewhere on the board
BD0: U2.3 (DB0), U58B1.8 (D0), U70.34 (D0), U77.27 (D0); also elsewhere on the board
BUC: J4.25, J8.32, R47.2, T14.1 (Pin_1_1), U29.12 (Q1)
D1: U2.6 (DB1), U58B1.7 (D1), U70.33 (D1), U77.28 (D1); also elsewhere on the board
D2: U2.10 (DB2), U58B1.6 (D2), U70.32 (D2), U77.1 (D2); also elsewhere on the board
D3: U2.13 (DB3), U58B1.5 (D3), U70.31 (D3), U77.2 (D3); also elsewhere on the board
D4: U1.6 (DB1), U58B1.4 (D4), U70.30 (D4), U77.5 (D4); also elsewhere on the board
D5: U1.3 (DB0), U58B1.3 (D5), U70.29 (D5), U77.6 (D5); also elsewhere on the board
D6: U1.10 (DB2), U58B1.2 (D6), U70.28 (D6), U77.7 (D6); also elsewhere on the board
D7: U1.13 (DB3), U58B1.1 (D7), U69.6, U70.27 (D7), U77.8 (D7); also elsewhere on the board
FON: J2.20; also elsewhere on the board
GND: C9.1, D1.2 (A), D4.2 (A), D6.2 (A), D8.1 (K), J2.6, J2.7, J2.19, J4.20, J8.2, J15.2, J17.2, R5.1, R10.2, R13.2, R14.2, R73.2, R110.2, U1.1 (~CS), U1.8 (GND), U2.1 (~CS), U2.8 (GND), U29.8 (GND), U29.13 (~CE1), U30.1 (A), U31.8 (GND), U38.8 (GND), U38.13 (~CE1), U43.2 (R0(1)), U43.3 (R0(2)), U43.6 (R9(1)), U43.7 (R9(2)), U43.10 (GND), U45.3 (+), U58B1.12 (GND), U70.7 (GND), U77.4 (GND); also elsewhere on the board
MON: U31.14 (~Q3); also elsewhere on the board
NMIX: J2.14, R68.2, U41.13
unnamed: D1.1 (K), R15.2, R16.2, U30.2 (B)
unnamed: D4.1 (K), D5.2 (A), R74.1, R75.2
unnamed: D6.1 (K), D7.2 (A), R76.2, R77.1
unnamed: C8.2, D9.1 (K), D11.2 (A)
unnamed: C7.2, D8.2 (A), D9.2 (A), D11.1 (K), R11.2, U45.6
unnamed: R4.1, R5.2, R6.1, R9.2
unnamed: R16.1, U46.6
unnamed: R70.1, U41.12, U42.12
unnamed: R77.2, U44.9
unnamed: U1.15 (~DIEN), U2.15 (~DIEN), U32.8
unnamed: U2.2 (DO0), U31.4 (D0)
unnamed: U2.5 (DO1), U31.5 (D1)
unnamed: U2.11 (DO2), U31.12 (D2)
unnamed: U2.14 (DO3), U31.13 (D3)
unnamed: C4.1, U30.14 (Cext)
unnamed: U30.3 (Clr), U31.9 (Cp), U32.11, U60.1
unnamed: C4.2, R3.2, U30.15 (RCext)
unnamed: U30.4 (~Q), U60.5
unnamed: R4.2, R7.2, U31.7 (Q1)
unnamed: R8.1, U31.1 (~Mr)
unnamed: R6.2, U31.3 (~Q0)
unnamed: U32.6, U69.4
unnamed: U43.11 (Q3), U43.14 (CP0)
unnamed: U43.12 (Q0), U58B1.15 (CLK1)
unnamed: U43.8 (Q2), U58B1.9 (CLK0)
unnamed: C6.2, C7.1, R11.1, R110.1, U45.2 (-)
unnamed: R14.1, R15.1, U46.3 (+)
unnamed: C8.1, R12.2, R13.1, U46.2 (-)
unnamed: R71.2, U58B1.11 (G0), U58B1.14 (G1)
unnamed: U41.11, U58B1.16 (G2)
unnamed: U58B1.13 (OUT1), U75.9 (A)
unnamed: U60.2, U60.6, U69.5
unnamed: U60.3, U60.4
unnamed: R17.1, U75.10 (B)
unnamed: C25.1, U75.6 (Cext)
unnamed: C25.2, R220.1, U75.7 (RCext)
unnamed: U44.8, U77.3 (RxD)
unnamed: U77.19 (TxD), U78.2 (-)
unnamed: R74.2, U77.17 (~CTS)
unnamed: R72.2, R73.1, U78.3 (+)
PHI_OSC: U43.1 (CP1..3); also elsewhere on the board
PHI_S: U58B1.10 (OUT0), U77.9 (~TxC), U77.25 (~RxC)
RESIN: J2.1, J4.13, J8.31; also elsewhere on the board
RESOUT: U70.35 (RESET), U77.21 (RESET); also elsewhere on the board
TINT: U75.5 (Q); also elsewhere on the board
TNMI: U58B1.17 (OUT2); also elsewhere on the board
~BCS: J2.10, R45.2, U29.10 (Q3)
~FDCS: J8.18, R46.2, U29.11 (Q2)
~IORQ: U29.14 (~CE2), U38.14 (~CE2); also elsewhere on the board
~IOS: R44.2, U29.9 (Q4); also elsewhere on the board
~KL: U32.9; also elsewhere on the board
~MAG: R34.2, T12.1 (Pin_1_1), U32.4, U32.12, U38.10 (Q3)
~PCS: R35.2, T13.1 (Pin_1_1), U38.9 (Q4), U70.6 (~CS)
~PHI: U58B1.18 (CLK2), U77.20 (CLK); also elsewhere on the board
~RD: U32.5, U32.10, U58B1.22 (~RD), U70.5 (~RD), U77.13 (~RD); also elsewhere on the board
~SCS: R33.2, T11.1 (Pin_1_1), U38.11 (Q2), U77.11 (~CS)
~TCS: R32.2, T10.1 (Pin_1_1), U38.12 (Q1), U58B1.21 (~CS)
~WR: U32.13, U58B1.23 (~WR), U70.36 (~WR), U77.10 (~WR); also elsewhere on the board

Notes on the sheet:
EMPTY

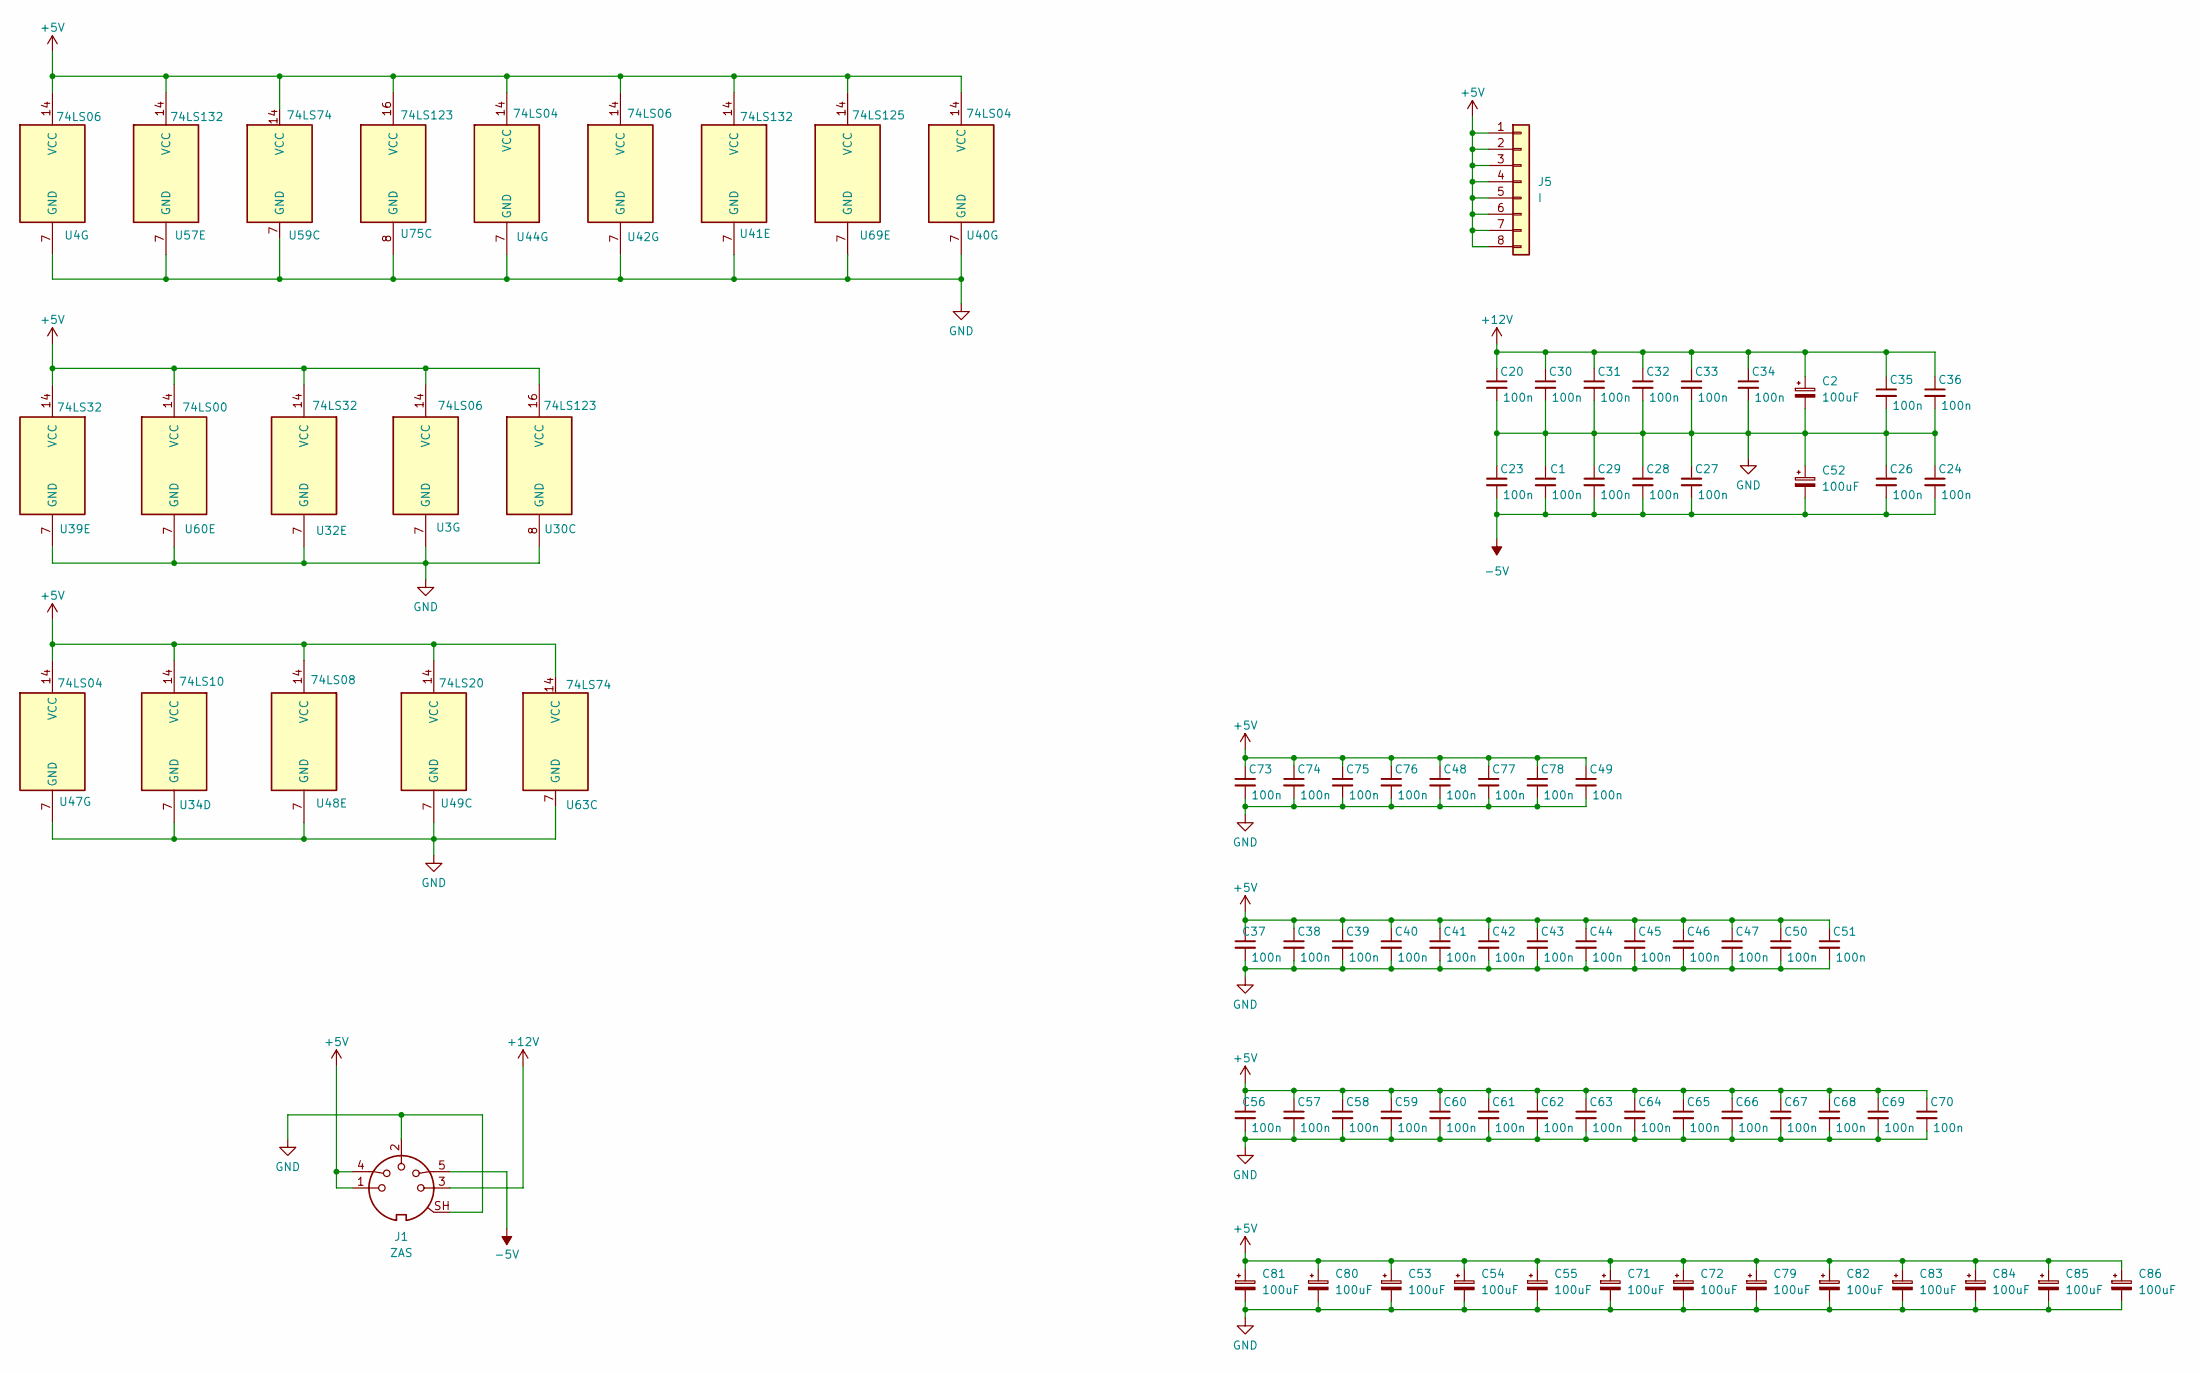
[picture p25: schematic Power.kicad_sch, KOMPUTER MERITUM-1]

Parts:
C1, C20, C23, C24, C26, C27, C28, C29, C30, C31, C32, C33, C34, C35, C36, C37, C38, C39, C40, C41, C42, C43, C44, C45, C46, C47, C50, C51, C56, C57, C58, C59, C60, C61, C62, C63, C64, C65, C66, C67, C68, C69, C70, C73, C74, C75, C76: 100n; c_200
C2, C52, C53, C54, C55, C71, C72, C79, C80, C81, C82, C83, C84, C85, C86: 100uF; CP_Radial_D5.0mm_P2.50mm
C48, C49, C77, C78: 100n; c_100
J1: ZAS; CUI_SDS-50J
J5: I; PinHeader_1x08_P2.54mm_Vertical
U3, U4, U42: 74LS06; DIP-14_W7.62mm_LongPads
U30, U75: 74LS123; DIP-16_W7.62mm_LongPads
U32, U39: 74LS32; DIP-14_W7.62mm_LongPads
U34: 74LS10; DIP-14_W7.62mm_LongPads
U40, U44, U47: 74LS04; DIP-14_W7.62mm_LongPads
U41, U57: 74LS132; DIP-14_W7.62mm_LongPads
U48: 74LS08; DIP-14_W7.62mm_LongPads
U49: 74LS20; DIP-14_W7.62mm_LongPads
U59, U63: 74LS74; DIP-14_W7.62mm_LongPads
U60: 74LS00; DIP-14_W7.62mm_LongPads
U69: 74LS125; DIP-14_W7.62mm_LongPads

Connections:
+5V: C37.1, C38.1, C39.1, C40.1, C41.1, C42.1, C43.1, C44.1, C45.1, C46.1, C47.1, C48.1, C49.1, C50.1, C51.1, C53.1, C54.1, C55.1, C56.1, C57.1, C58.1, C59.1, C60.1, C61.1, C62.1, C63.1, C64.1, C65.1, C66.1, C67.1, C68.1, C69.1, C70.1, C71.1, C72.1, C73.1, C74.1, C75.1, C76.1, C77.1, C78.1, C79.1, C80.1, C81.1, C82.1, C83.1, C84.1, C85.1, C86.1, J1.1, J1.4, J5.1, J5.2, J5.3, J5.4, J5.5, J5.6, J5.7, J5.8, U3.14 (VCC), U4.14 (VCC), U30.16 (VCC), U32.14 (VCC), U34.14 (VCC), U39.14 (VCC), U40.14 (VCC), U41.14 (VCC), U42.14 (VCC), U44.14 (VCC), U47.14 (VCC), U48.14 (VCC), U49.14 (VCC), U57.14 (VCC), U59.14 (VCC), U60.14 (VCC), U63.14 (VCC), U69.14 (VCC), U75.16 (VCC); also elsewhere on the board
+12V: C2.1, C20.1, C30.1, C31.1, C32.1, C33.1, C34.1, C35.1, C36.1, J1.3; also elsewhere on the board
-5V: C1.2, C23.2, C24.2, C26.2, C27.2, C28.2, C29.2, C52.2, J1.5; also elsewhere on the board
GND: C1.1, C2.2, C20.2, C23.1, C24.1, C26.1, C27.1, C28.1, C29.1, C30.2, C31.2, C32.2, C33.2, C34.2, C35.2, C36.2, C37.2, C38.2, C39.2, C40.2, C41.2, C42.2, C43.2, C44.2, C45.2, C46.2, C47.2, C48.2, C49.2, C50.2, C51.2, C52.1, C53.2, C54.2, C55.2, C56.2, C57.2, C58.2, C59.2, C60.2, C61.2, C62.2, C63.2, C64.2, C65.2, C66.2, C67.2, C68.2, C69.2, C70.2, C71.2, C72.2, C73.2, C74.2, C75.2, C76.2, C77.2, C78.2, C79.2, C80.2, C81.2, C82.2, C83.2, C84.2, C85.2, C86.2, J1.2, J1.SH, U3.7 (GND), U4.7 (GND), U30.8 (GND), U32.7 (GND), U34.7 (GND), U39.7 (GND), U40.7 (GND), U41.7 (GND), U42.7 (GND), U44.7 (GND), U47.7 (GND), U48.7 (GND), U49.7 (GND), U57.7 (GND), U59.7 (GND), U60.7 (GND), U63.7 (GND), U69.7 (GND), U75.8 (GND); also elsewhere on the board

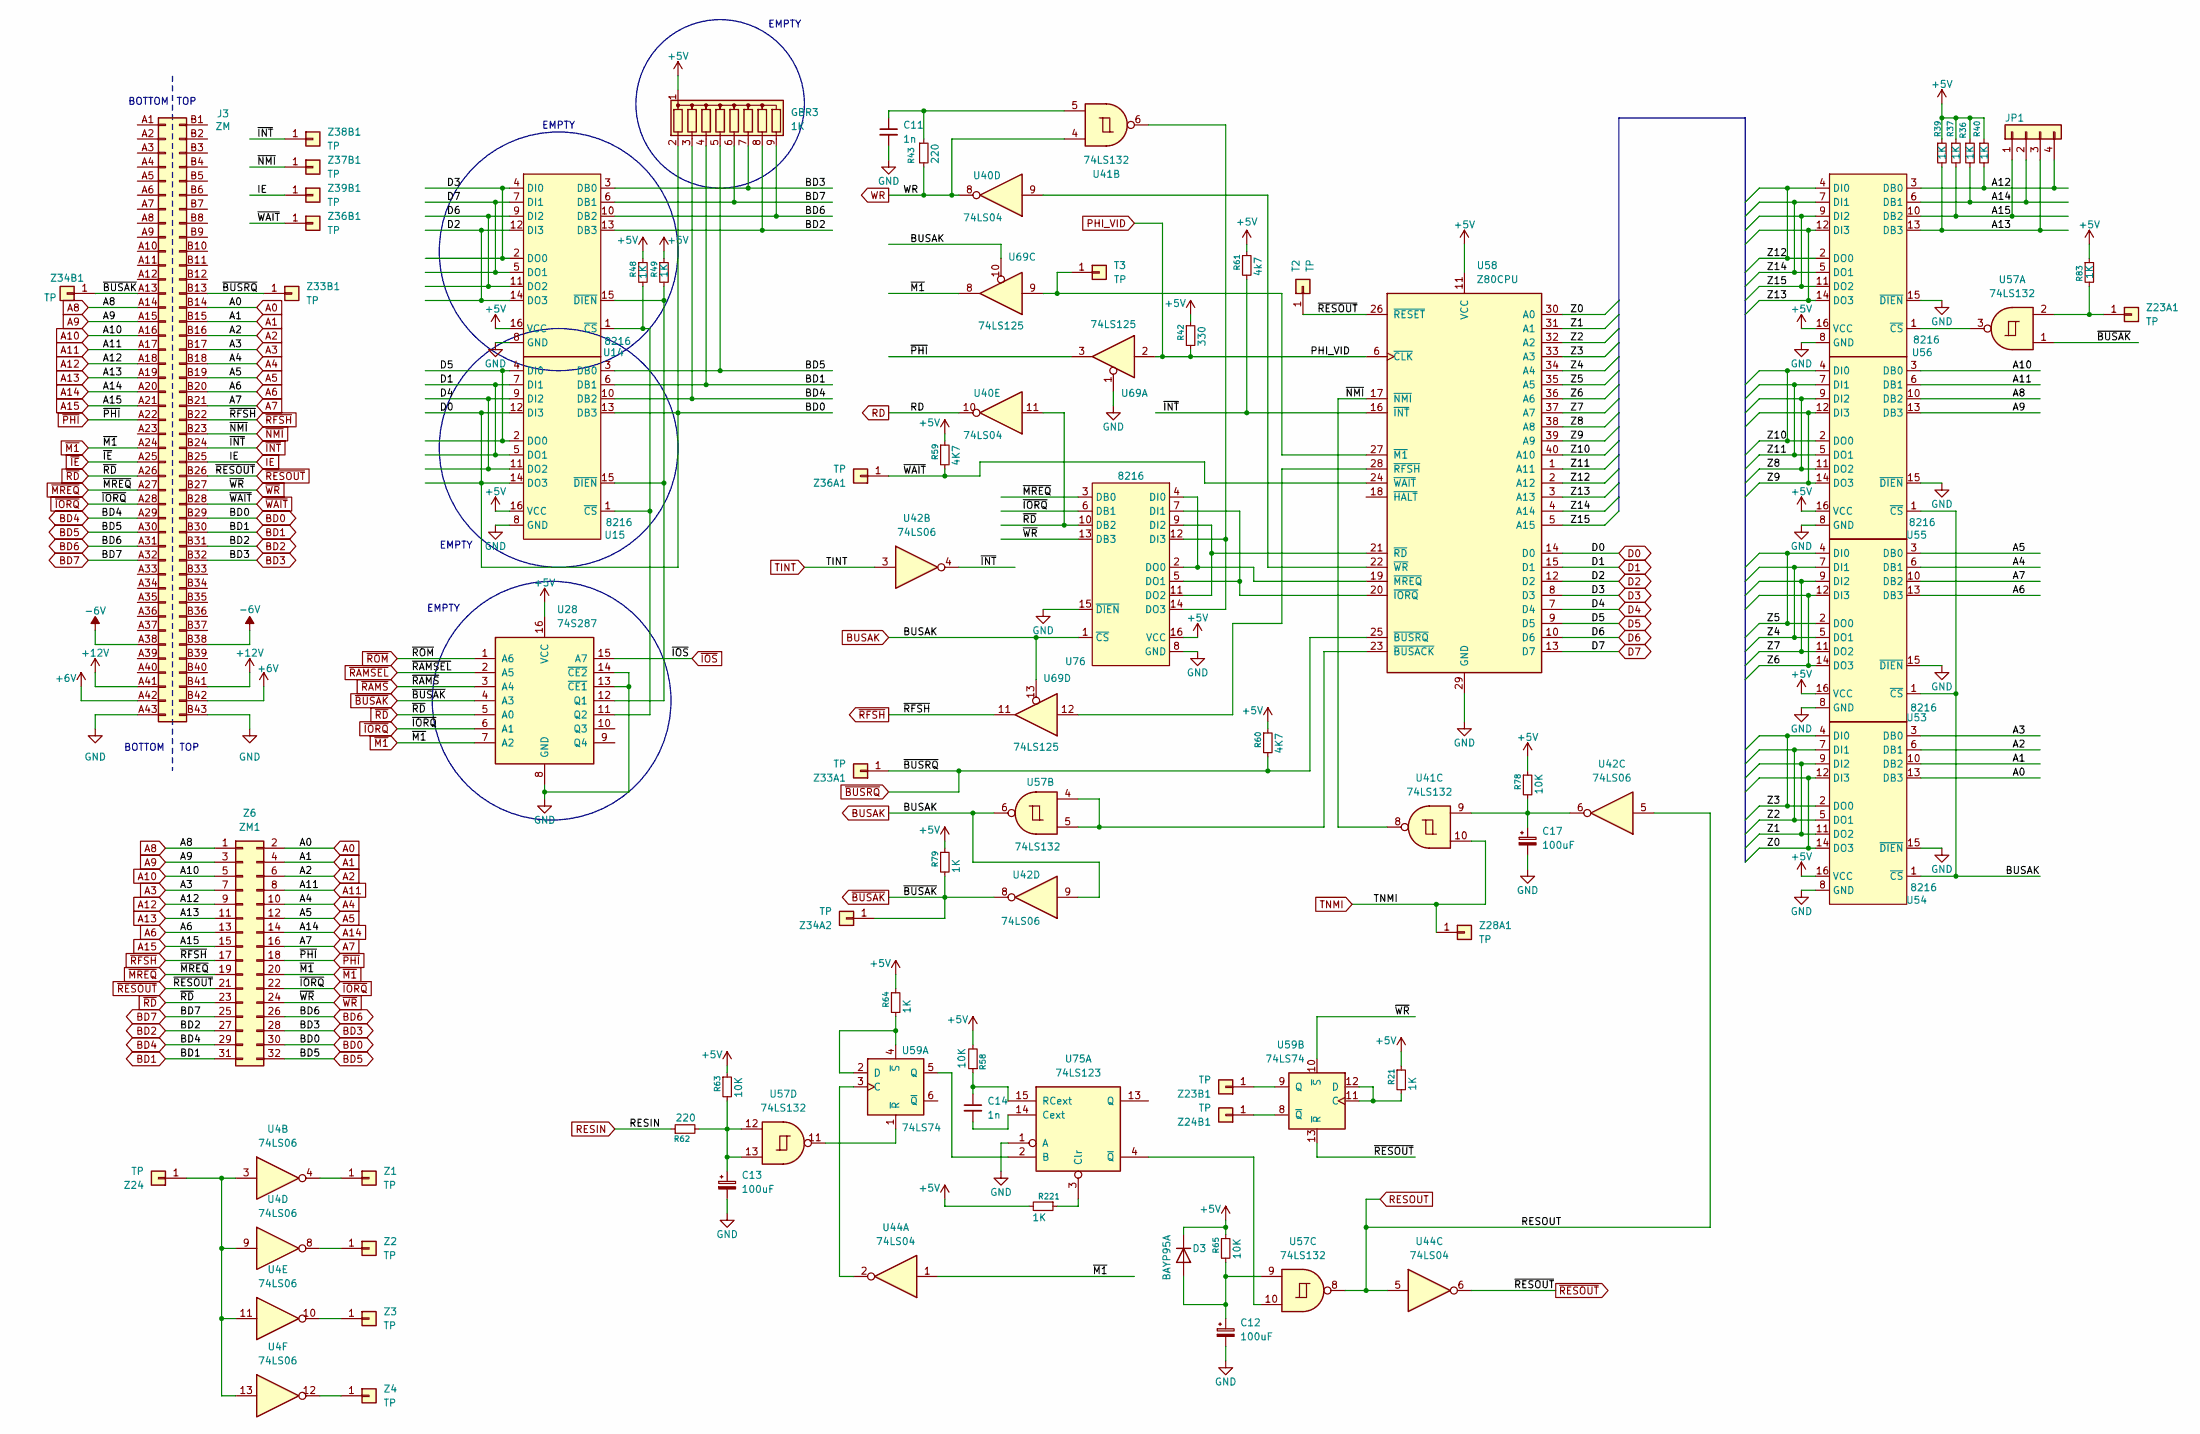
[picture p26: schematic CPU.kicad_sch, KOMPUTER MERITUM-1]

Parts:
C11, C14: 1n; c_200
C12, C13, C17: 100uF; CP_Radial_D5.0mm_P2.50mm
D3: BAYP95A; D_DO-35_SOD27_P10.16mm_Horizontal
GBR3: 1K; R_Array_SIP9
J3: ZM; Meritum_ZM
JP1: Conn_01x04; PinHeader_1x04_P2.54mm_Vertical
R21, R36, R37, R39, R40, R48, R49, R64, R79, R83, R221: 1K; r_400
R42: 330; r_400
R43, R62: 220; r_400
R58, R63, R65, R78: 10K; r_400
R59, R60: 4K7; r_400
R61: 4k7; r_400
T2, T3: TP; pin
U4, U42: 74LS06; DIP-14_W7.62mm_LongPads
U14, U15, U53, U54, U55, U56, U76: 8216; DIP-16_W7.62mm_LongPads
U28: 74S287; DIP-16_W7.62mm_LongPads
U40, U44: 74LS04; DIP-14_W7.62mm_LongPads
U41, U57: 74LS132; DIP-14_W7.62mm_LongPads
U58: Z80CPU; DIP-40_W15.24mm_LongPads
U59: 74LS74; DIP-14_W7.62mm_LongPads
U69: 74LS125; DIP-14_W7.62mm_LongPads
U75: 74LS123; DIP-16_W7.62mm_LongPads
Z1, Z2, Z3, Z4, Z23A1, Z23B1, Z24, Z24B1, Z28A1, Z33A1, Z33B1, Z34A2, Z34B1, Z36A1, Z36B1, Z37B1, Z38B1, Z39B1: TP; pin
Z6: ZM1; PinSocket_2x16_P2.54mm_Vertical_Meritum

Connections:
+5V: D3.1 (K), GBR3.1 (common), R21.1, R36.1, R37.1, R39.1, R40.1, R42.1, R48.1, R49.1, R58.2, R59.1, R60.1, R61.1, R63.1, R64.1, R65.1, R78.1, R79.1, R83.1, R221.2, U14.16 (VCC), U15.16 (VCC), U28.16 (VCC), U53.16 (VCC), U54.16 (VCC), U55.16 (VCC), U56.16 (VCC), U58.11 (VCC), U76.16 (VCC); also elsewhere on the board
+6V: J3.A42 (Pin_a42), J3.B42 (Pin_b42)
+12V: J3.A41 (Pin_a41), J3.B41 (Pin_b41); also elsewhere on the board
-6V: J3.A38 (Pin_a38), J3.B38 (Pin_b38)
/CPU/Z0: U54.12 (DI3), U54.14 (DO3), U58.30 (A0)
/CPU/Z1: U54.9 (DI2), U54.11 (DO2), U58.31 (A1)
/CPU/Z2: U54.5 (DO1), U54.7 (DI1), U58.32 (A2)
/CPU/Z3: U54.2 (DO0), U54.4 (DI0), U58.33 (A3)
/CPU/Z4: U53.5 (DO1), U53.7 (DI1), U58.34 (A4)
/CPU/Z5: U53.2 (DO0), U53.4 (DI0), U58.35 (A5)
/CPU/Z6: U53.12 (DI3), U53.14 (DO3), U58.36 (A6)
/CPU/Z7: U53.9 (DI2), U53.11 (DO2), U58.37 (A7)
/CPU/Z8: U55.9 (DI2), U55.11 (DO2), U58.38 (A8)
/CPU/Z9: U55.12 (DI3), U55.14 (DO3), U58.39 (A9)
/CPU/Z10: U55.2 (DO0), U55.4 (DI0), U58.40 (A10)
/CPU/Z11: U55.5 (DO1), U55.7 (DI1), U58.1 (A11)
/CPU/Z12: U56.2 (DO0), U56.4 (DI0), U58.2 (A12)
/CPU/Z13: U56.12 (DI3), U56.14 (DO3), U58.3 (A13)
/CPU/Z14: U56.5 (DO1), U56.7 (DI1), U58.4 (A14)
/CPU/Z15: U56.9 (DI2), U56.11 (DO2), U58.5 (A15)
A0: J3.B14 (Pin_b14), U54.13 (DB3), Z6.2; also elsewhere on the board
A1: J3.B15 (Pin_b15), U54.10 (DB2), Z6.4; also elsewhere on the board
A2: J3.B16 (Pin_b16), U54.6 (DB1), Z6.6; also elsewhere on the board
A3: J3.B17 (Pin_b17), U54.3 (DB0), Z6.7; also elsewhere on the board
A4: J3.B18 (Pin_b18), U53.6 (DB1), Z6.10; also elsewhere on the board
A5: J3.B19 (Pin_b19), U53.3 (DB0), Z6.12; also elsewhere on the board
A6: J3.B20 (Pin_b20), U53.13 (DB3), Z6.13; also elsewhere on the board
A7: J3.B21 (Pin_b21), U53.10 (DB2), Z6.16; also elsewhere on the board
A8: J3.A14 (Pin_a14), U55.10 (DB2), Z6.1; also elsewhere on the board
A9: J3.A15 (Pin_a15), U55.13 (DB3), Z6.3; also elsewhere on the board
A10: J3.A16 (Pin_a16), U55.3 (DB0), Z6.5; also elsewhere on the board
A11: J3.A17 (Pin_a17), U55.6 (DB1), Z6.8; also elsewhere on the board
A12: J3.A18 (Pin_a18), JP1.4, R40.2, U56.3 (DB0), Z6.9; also elsewhere on the board
A13: J3.A19 (Pin_a19), JP1.3, R39.2, U56.13 (DB3), Z6.11; also elsewhere on the board
A14: J3.A20 (Pin_a20), JP1.2, R36.2, U56.6 (DB1), Z6.14; also elsewhere on the board
A15: J3.A21 (Pin_a21), JP1.1, R37.2, U56.10 (DB2), Z6.15; also elsewhere on the board
BD0: GBR3.2 (R1), J3.B29 (Pin_b29), U15.12 (DI3), U15.13 (DB3), U15.14 (DO3), U58.14 (D0), Z6.30; also elsewhere on the board
BD1: GBR3.4 (R3), J3.B30 (Pin_b30), U15.6 (DB1), Z6.31
BD2: GBR3.8 (R7), J3.B31 (Pin_b31), U14.13 (DB3), Z6.27
BD3: GBR3.7 (R6), J3.B32 (Pin_b32), U14.3 (DB0), Z6.28
BD4: GBR3.3 (R2), J3.A29 (Pin_a29), U15.10 (DB2), Z6.29
BD5: GBR3.5 (R4), J3.A30 (Pin_a30), U15.3 (DB0), Z6.32
BD6: GBR3.9 (R8), J3.A31 (Pin_a31), U14.10 (DB2), Z6.26
BD7: GBR3.6 (R5), J3.A32 (Pin_a32), U14.6 (DB1), Z6.25
BUSAK: U42.9, U53.1 (~CS), U54.1 (~CS), U55.1 (~CS), U57.6, U69.10, U69.13, U76.1 (~CS)
D1: U15.5 (DO1), U15.7 (DI1), U58.15 (D1); also elsewhere on the board
D2: U14.12 (DI3), U14.14 (DO3), U58.12 (D2); also elsewhere on the board
D3: U14.2 (DO0), U14.4 (DI0), U58.8 (D3); also elsewhere on the board
D4: U15.9 (DI2), U15.11 (DO2), U58.7 (D4); also elsewhere on the board
D5: U15.2 (DO0), U15.4 (DI0), U58.9 (D5); also elsewhere on the board
D6: U14.9 (DI2), U14.11 (DO2), U58.10 (D6); also elsewhere on the board
D7: U14.5 (DO1), U14.7 (DI1), U58.13 (D7); also elsewhere on the board
GND: C11.2, C12.2, C13.2, C17.2, J3.A43 (Pin_a43), J3.B43 (Pin_b43), U14.8 (GND), U15.8 (GND), U28.8 (GND), U28.13 (~CE1), U28.14 (~CE2), U53.8 (GND), U53.15 (~DIEN), U54.8 (GND), U54.15 (~DIEN), U55.8 (GND), U55.15 (~DIEN), U56.8 (GND), U56.15 (~DIEN), U58.29 (GND), U69.1, U75.1 (A), U76.8 (GND), U76.15 (~DIEN); also elsewhere on the board
IE: J3.B25 (Pin_b25), Z39B1.1 (Pin_1_1)
unnamed: C11.1, R43.1, U41.5
unnamed: C13.1, R62.2, R63.2, U57.12, U57.13
unnamed: C17.1, R78.2, U41.9, U42.6
unnamed: C12.1, D3.2 (A), R65.2, U57.9
unnamed: T3.1 (Pin_1_1), U58.27 (~M1), U69.9
unnamed: R48.2, U14.1 (~CS), U15.1 (~CS), U28.11 (Q2)
unnamed: R49.2, U14.15 (~DIEN), U15.15 (~DIEN), U28.12 (Q1)
unnamed: U56.1 (~CS), U57.3
unnamed: U57.4, U57.5, U58.23 (~BUSACK)
unnamed: U58.20 (~IORQ), U76.5 (DO1), U76.7 (DI1)
unnamed: U58.19 (~MREQ), U76.2 (DO0), U76.4 (DI0)
unnamed: U58.21 (~RD), U76.9 (DI2), U76.11 (DO2)
unnamed: U58.28 (~RFSH), U69.12
unnamed: U40.9, U58.22 (~WR)
unnamed: U44.2, U59.3 (C)
unnamed: R64.2, U59.2 (D), U59.4 (~S)
unnamed: U59.5 (Q), U75.2 (B)
unnamed: U57.11, U59.1 (~R)
unnamed: R21.2, U59.11 (C), U59.12 (D)
unnamed: U59.9 (Q), Z23B1.1 (Pin_1_1)
unnamed: U59.8 (~Q), Z24B1.1 (Pin_1_1)
unnamed: C14.2, U75.14 (Cext)
unnamed: R221.1, U75.3 (Clr)
unnamed: C14.1, R58.1, U75.15 (RCext)
unnamed: U57.10, U75.4 (~Q)
unnamed: U41.6, U76.12 (DI3), U76.14 (DO3)
unnamed: U4.4, Z1.1 (Pin_1_1)
unnamed: U4.8, Z2.1 (Pin_1_1)
unnamed: U4.10, Z3.1 (Pin_1_1)
unnamed: U4.12, Z4.1 (Pin_1_1)
unnamed: R83.2, U57.2, Z23A1.1 (Pin_1_1)
unnamed: U4.3, U4.9, U4.11, U4.13, Z24.1 (Pin_1_1)
PHI_VID: R42.2, U58.6 (~CLK), U69.2; also elsewhere on the board
RD: U40.10; also elsewhere on the board
RESIN: R62.1; also elsewhere on the board
RESOUT: U42.5, U44.5, U57.8; also elsewhere on the board
TINT: U42.3; also elsewhere on the board
TNMI: U41.10, Z28A1.1 (Pin_1_1); also elsewhere on the board
WR: R43.2, U40.8, U41.4; also elsewhere on the board
~BUSAK: J3.A13 (Pin_a13), R79.2, U28.4 (A3), U42.8, U57.1, Z34A2.1 (Pin_1_1), Z34B1.1 (Pin_1_1)
~BUSRQ: J3.B13 (Pin_b13), R60.2, U58.25 (~BUSRQ), Z33A1.1 (Pin_1_1), Z33B1.1 (Pin_1_1)
~IE: J3.A25 (Pin_a25)
~INT: J3.B24 (Pin_b24), R61.2, U42.4, U58.16 (~INT), Z38B1.1 (Pin_1_1)
~IORQ: J3.A28 (Pin_a28), U28.6 (A1), U76.6 (DB1), Z6.22; also elsewhere on the board
~IOS: U28.15 (A7); also elsewhere on the board
~M1: J3.A24 (Pin_a24), U28.7 (A2), U44.1, U69.8, Z6.20
~MREQ: J3.A27 (Pin_a27), U76.3 (DB0), Z6.19; also elsewhere on the board
~NMI: J3.B23 (Pin_b23), U41.8, U58.17 (~NMI), Z37B1.1 (Pin_1_1)
~PHI: J3.A22 (Pin_a22), U69.3, Z6.18; also elsewhere on the board
~RAMSEL: U28.2 (A5); also elsewhere on the board
~RAMS: U28.3 (A4); also elsewhere on the board
~RD: J3.A26 (Pin_a26), U28.5 (A0), U40.11, U76.10 (DB2), Z6.23; also elsewhere on the board
~RESOUT: J3.B26 (Pin_b26), T2.1 (Pin_1_1), U44.6, U58.26 (~RESET), U59.13 (~R), Z6.21
~RFSH: J3.B22 (Pin_b22), U69.11, Z6.17; also elsewhere on the board
~ROM: U28.1 (A6); also elsewhere on the board
~WAIT: J3.B28 (Pin_b28), R59.2, U58.24 (~WAIT), Z36A1.1 (Pin_1_1), Z36B1.1 (Pin_1_1)
~WR: J3.B27 (Pin_b27), U59.10 (~S), U76.13 (DB3), Z6.24; also elsewhere on the board

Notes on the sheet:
TOP
EMPTY
BOTTOM

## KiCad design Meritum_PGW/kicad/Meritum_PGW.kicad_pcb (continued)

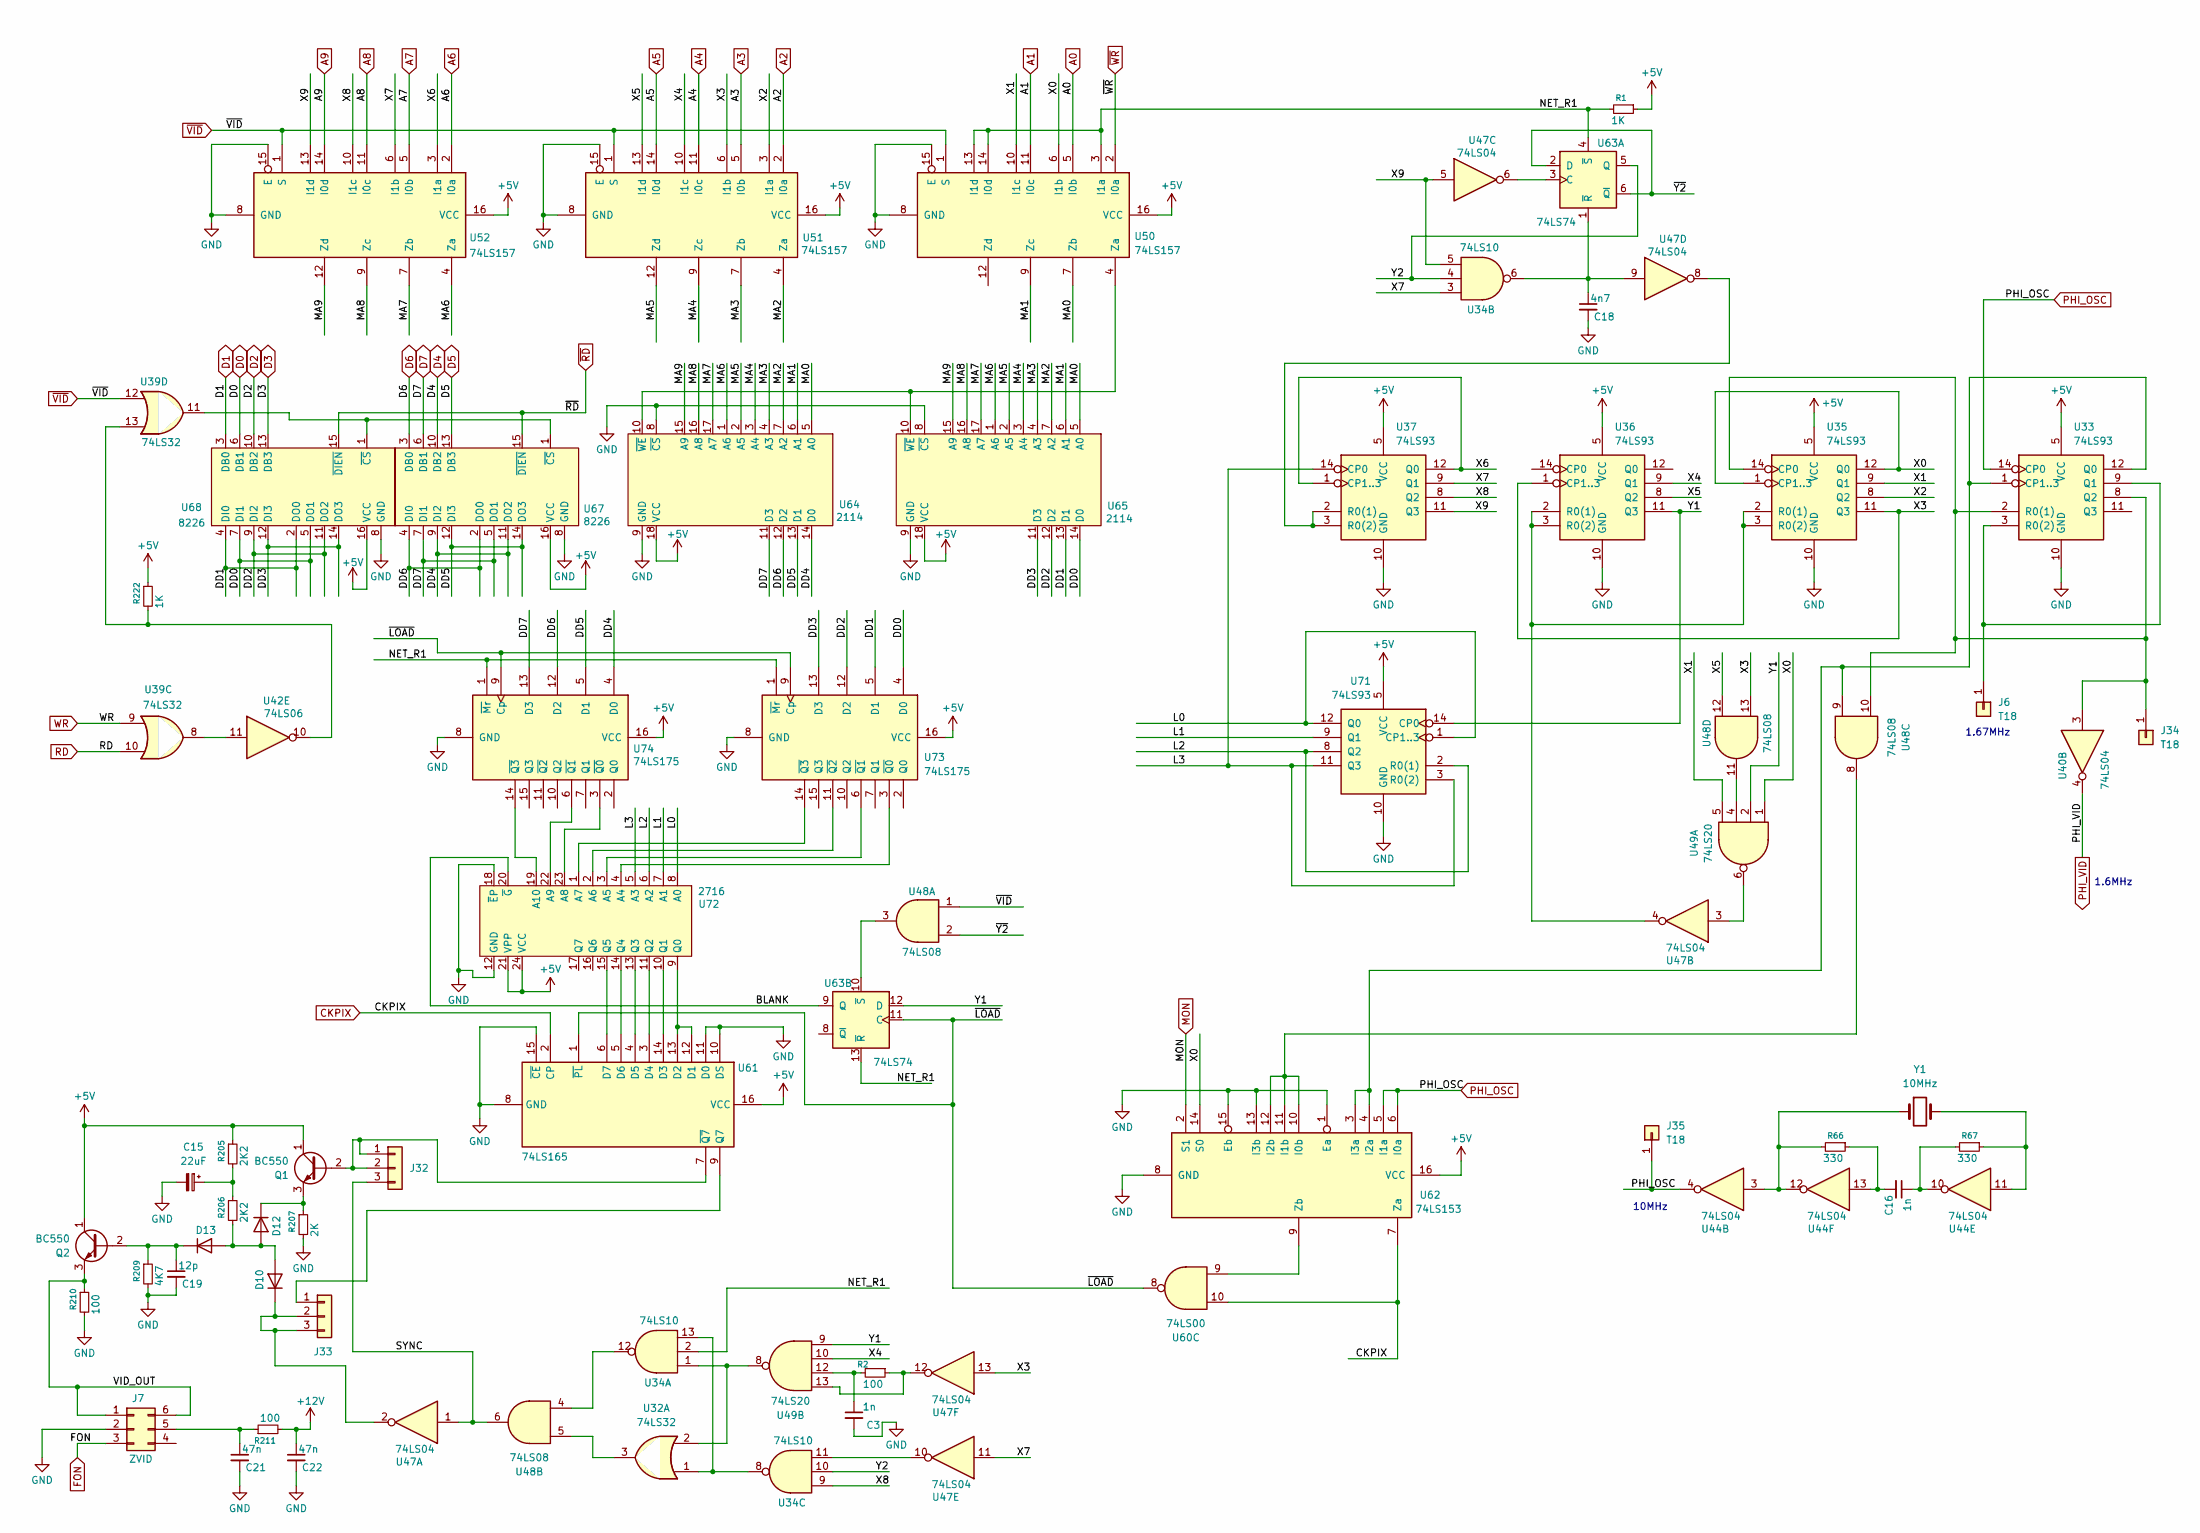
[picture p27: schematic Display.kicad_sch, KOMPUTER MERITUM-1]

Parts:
C3, C16: 1n; c_200
C15: 22uF; CP_Radial_D5.0mm_P2.50mm
C18: 4n7; c_100
C19: 12p; C_Rect_L7.0mm_W2.0mm_P5.00mm
C21, C22: 47n; c_200
D10, D12, D13: 1N4148WT; D_DO-35_SOD27_P10.16mm_Horizontal
J6, J34, J35: T18; pin
J7: ZVID; PinHeader_2x03_P2.54mm_Vertical
J32, J33: Conn_01x03; PinHeader_1x03_P2.54mm_Vertical
Q1, Q2: BC550; TO-92L
R1, R222: 1K; r_400
R2: 100; R_Axial_DIN0207_L6.3mm_D2.5mm_P7.62mm_Horizontal
R66, R67: 330; r_400
R205: 2K2; r_400
R206: 2K2; R_Axial_DIN0207_L6.3mm_D2.5mm_P2.54mm_Vertical
R207: 2K; r_400
R209: 4K7; r_400
R210, R211: 100; r_400
U32, U39: 74LS32; DIP-14_W7.62mm_LongPads
U33, U35, U36, U37, U71: 74LS93; DIP-14_W7.62mm_LongPads
U34: 74LS10; DIP-14_W7.62mm_LongPads
U40, U44, U47: 74LS04; DIP-14_W7.62mm_LongPads
U42: 74LS06; DIP-14_W7.62mm_LongPads
U48: 74LS08; DIP-14_W7.62mm_LongPads
U49: 74LS20; DIP-14_W7.62mm_LongPads
U50, U51, U52: 74LS157; DIP-16_W7.62mm_LongPads
U60: 74LS00; DIP-14_W7.62mm_LongPads
U61: 74LS165; DIP-16_W7.62mm_LongPads
U62: 74LS153; DIP-16_W7.62mm_LongPads
U63: 74LS74; DIP-14_W7.62mm_LongPads
U64, U65: 2114; DIP-18_W7.62mm_Socket_LongPads
U67, U68: 8226; DIP-16_W7.62mm_LongPads
U72: 2716; DIP-24_W15.24mm_LongPads
U73, U74: 74LS175; DIP-16_W7.62mm_LongPads
Y1: 10MHz; Crystal_HC49-4H_Vertical

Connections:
+5V: Q1.1 (C), Q2.1 (C), R1.1, R205.1, R222.1, U33.5 (VCC), U35.5 (VCC), U36.5 (VCC), U37.5 (VCC), U50.16 (VCC), U51.16 (VCC), U52.16 (VCC), U61.16 (VCC), U62.16 (VCC), U64.18 (VCC), U65.18 (VCC), U67.16 (VCC), U68.16 (VCC), U71.5 (VCC), U72.21 (VPP), U72.24 (VCC), U73.16 (VCC), U74.16 (VCC); also elsewhere on the board
+12V: C22.1, R211.2; also elsewhere on the board
/Display/BLANK: U63.9 (Q), U72.20 (~G)
/Display/DD0: U65.14 (D0), U68.5 (DO1), U68.7 (DI1), U73.4 (D0)
/Display/DD1: U65.13 (D1), U68.2 (DO0), U68.4 (DI0), U73.5 (D1)
/Display/DD2: U65.12 (D2), U68.9 (DI2), U68.11 (DO2), U73.12 (D2)
/Display/DD3: U65.11 (D3), U68.12 (DI3), U68.14 (DO3), U73.13 (D3)
/Display/DD4: U64.14 (D0), U67.9 (DI2), U67.11 (DO2), U74.4 (D0)
/Display/DD5: U64.13 (D1), U67.12 (DI3), U67.14 (DO3), U74.5 (D1)
/Display/DD6: U64.12 (D2), U67.2 (DO0), U67.4 (DI0), U74.12 (D2)
/Display/DD7: U64.11 (D3), U67.5 (DO1), U67.7 (DI1), U74.13 (D3)
/Display/L0: U71.1 (CP1..3), U71.12 (Q0), U72.8 (A0)
/Display/L1: U71.9 (Q1), U72.7 (A1)
/Display/L2: U71.2 (R0(1)), U71.8 (Q2), U72.6 (A2)
/Display/L3: U37.14 (CP0), U71.3 (R0(2)), U71.11 (Q3), U72.5 (A3)
/Display/MA0: U50.7 (Zb), U64.5 (A0), U65.5 (A0)
/Display/MA1: U50.9 (Zc), U64.6 (A1), U65.6 (A1)
/Display/MA2: U51.4 (Za), U64.7 (A2), U65.7 (A2)
/Display/MA3: U51.7 (Zb), U64.4 (A3), U65.4 (A3)
/Display/MA4: U51.9 (Zc), U64.3 (A4), U65.3 (A4)
/Display/MA5: U51.12 (Zd), U64.2 (A5), U65.2 (A5)
/Display/MA6: U52.4 (Za), U64.1 (A6), U65.1 (A6)
/Display/MA7: U52.7 (Zb), U64.17 (A7), U65.17 (A7)
/Display/MA8: U52.9 (Zc), U64.16 (A8), U65.16 (A8)
/Display/MA9: U52.12 (Zd), U64.15 (A9), U65.15 (A9)
/Display/NET_R1: R1.2, U34.2, U50.3 (I1a), U50.13 (I1d), U50.14 (I0d), U63.4 (~S), U63.13 (~R), U73.1 (~Mr), U74.1 (~Mr)
/Display/SYNC: J32.3, U47.1, U48.6
/Display/VID_OUT: J7.1, J7.6, Q2.3 (E), R210.1
/Display/X0: U35.1 (CP1..3), U35.12 (Q0), U49.1, U50.6 (I1b), U62.14 (S0)
/Display/X1: U35.9 (Q1), U49.5, U50.10 (I1c)
/Display/X2: U35.8 (Q2), U51.3 (I1a)
/Display/X3: U35.11 (Q3), U36.1 (CP1..3), U47.13, U48.13, U51.6 (I1b)
/Display/X4: U36.9 (Q1), U49.10, U51.10 (I1c)
/Display/X5: U36.8 (Q2), U48.12, U51.13 (I1d)
/Display/X6: U37.1 (CP1..3), U37.12 (Q0), U52.3 (I1a)
/Display/X7: U34.3, U37.9 (Q1), U47.11, U52.6 (I1b)
/Display/X8: U34.9, U37.8 (Q2), U52.10 (I1c)
/Display/X9: U34.5, U37.11 (Q3), U47.5, U52.13 (I1d)
/Display/Y1: U36.11 (Q3), U49.2, U49.9, U63.12 (D), U71.14 (CP0)
/Display/Y2: U34.4, U34.10, U63.5 (Q)
/Display/~LOAD: U60.8, U61.1 (~PL), U63.11 (C), U73.9 (Cp), U74.9 (Cp)
/Display/~Y2: U48.2, U63.2 (D), U63.6 (~Q)
A0: U50.5 (I0b); also elsewhere on the board
A1: U50.11 (I0c); also elsewhere on the board
A2: U51.2 (I0a); also elsewhere on the board
A3: U51.5 (I0b); also elsewhere on the board
A4: U51.11 (I0c); also elsewhere on the board
A5: U51.14 (I0d); also elsewhere on the board
A6: U52.2 (I0a); also elsewhere on the board
A7: U52.5 (I0b); also elsewhere on the board
A8: U52.11 (I0c); also elsewhere on the board
A9: U52.14 (I0d); also elsewhere on the board
BD0: U68.6 (DB1); also elsewhere on the board
CKPIX: U60.10, U61.2 (CP), U62.7 (Za)
D1: U68.3 (DB0); also elsewhere on the board
D2: U68.10 (DB2); also elsewhere on the board
D3: U68.13 (DB3); also elsewhere on the board
D4: U67.10 (DB2); also elsewhere on the board
D5: U67.13 (DB3); also elsewhere on the board
D6: U67.3 (DB0); also elsewhere on the board
D7: U67.6 (DB1); also elsewhere on the board
FON: J7.3; also elsewhere on the board
GND: C3.2, C15.2, C18.2, C19.2, C21.2, C22.2, J7.2, R207.2, R209.2, R210.2, U33.10 (GND), U35.10 (GND), U36.10 (GND), U37.10 (GND), U50.8 (GND), U50.15 (E), U51.8 (GND), U51.15 (E), U52.8 (GND), U52.15 (E), U61.8 (GND), U61.10 (DS), U61.11 (D0), U61.15 (~CE), U62.1 (Ea), U62.8 (GND), U62.13 (I3b), U62.15 (Eb), U64.8 (~CS), U64.9 (GND), U65.8 (~CS), U65.9 (GND), U67.8 (GND), U68.8 (GND), U71.10 (GND), U72.12 (GND), U72.18 (~EP), U73.8 (GND), U74.8 (GND); also elsewhere on the board
MON: U62.2 (S1); also elsewhere on the board
unnamed: C3.1, R2.2, U49.12
unnamed: C15.1, R205.2, R206.1
unnamed: C16.1, R67.2, U44.10
unnamed: C16.2, R66.1, U44.13
unnamed: D10.2 (A), D12.2 (A), D13.2 (A), R206.2
unnamed: D10.1 (K), J33.2, J33.3, U47.2
unnamed: D12.1 (K), Q1.3 (E), R207.1
unnamed: C19.1, D13.1 (K), Q2.2 (B), R209.1
unnamed: J6.1 (Pin_1_1), U33.3 (R0(2)), U33.9 (Q1)
unnamed: C21.1, J7.5, R211.1
unnamed: J32.1, J32.2, Q1.2 (B), U61.7 (~Q7)
unnamed: J33.1, U61.9 (Q7)
unnamed: J34.1 (Pin_1_1), U33.2 (R0(1)), U33.8 (Q2), U35.14 (CP0), U40.3, U48.10
unnamed: R2.1, U47.12, U49.13
unnamed: R66.2, U44.3, U44.12, Y1.1
unnamed: R67.1, U44.11, Y1.2
unnamed: R222.2, U39.13, U42.10
unnamed: U32.1, U34.8, U34.13
unnamed: U32.2, U34.1, U49.8
unnamed: U32.3, U48.5
unnamed: U33.1 (CP1..3), U33.12 (Q0), U48.9, U62.3 (I3a), U62.4 (I2a)
unnamed: U34.11, U47.10
unnamed: U34.12, U48.4
unnamed: U35.2 (R0(1)), U35.3 (R0(2)), U36.2 (R0(1)), U36.3 (R0(2)), U47.4
unnamed: U37.2 (R0(1)), U37.3 (R0(2)), U47.8
unnamed: U39.8, U42.11
unnamed: U47.3, U49.6
unnamed: U48.11, U49.4
unnamed: U50.4 (Za), U64.10 (~WE), U65.10 (~WE)
unnamed: U61.12 (D1), U61.13 (D2), U72.9 (Q0)
unnamed: U61.14 (D3), U72.10 (Q1)
unnamed: U61.3 (D4), U72.11 (Q2)
unnamed: U61.4 (D5), U72.13 (Q3)
unnamed: U61.5 (D6), U72.14 (Q4)
unnamed: U61.6 (D7), U72.15 (Q5)
unnamed: U48.8, U62.10 (I0b), U62.11 (I1b), U62.12 (I2b)
unnamed: U60.9, U62.9 (Zb)
unnamed: U47.6, U63.3 (C)
unnamed: C18.1, U34.6, U47.9, U63.1 (~R)
unnamed: U48.3, U63.10 (~S)
unnamed: U39.11, U67.1 (~CS), U68.1 (~CS)
unnamed: U72.4 (A4), U73.3 (~Q0)
unnamed: U72.3 (A5), U73.6 (~Q1)
unnamed: U72.2 (A6), U73.11 (~Q2)
unnamed: U72.1 (A7), U73.14 (~Q3)
unnamed: U72.23 (A8), U74.3 (~Q0)
unnamed: U72.22 (A9), U74.6 (~Q1)
unnamed: U72.19 (A10), U74.14 (~Q3)
PHI_OSC: J35.1 (Pin_1_1), U33.14 (CP0), U44.4, U62.5 (I1a), U62.6 (I0a); also elsewhere on the board
PHI_VID: U40.4; also elsewhere on the board
RD: U39.10; also elsewhere on the board
WR: U39.9; also elsewhere on the board
~RD: U67.15 (~DIEN), U68.15 (~DIEN); also elsewhere on the board
~VID: U39.12, U48.1, U50.1 (S), U51.1 (S), U52.1 (S); also elsewhere on the board
~WR: U50.2 (I0a); also elsewhere on the board

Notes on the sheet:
1.6MHz
10MHz
1.67MHz

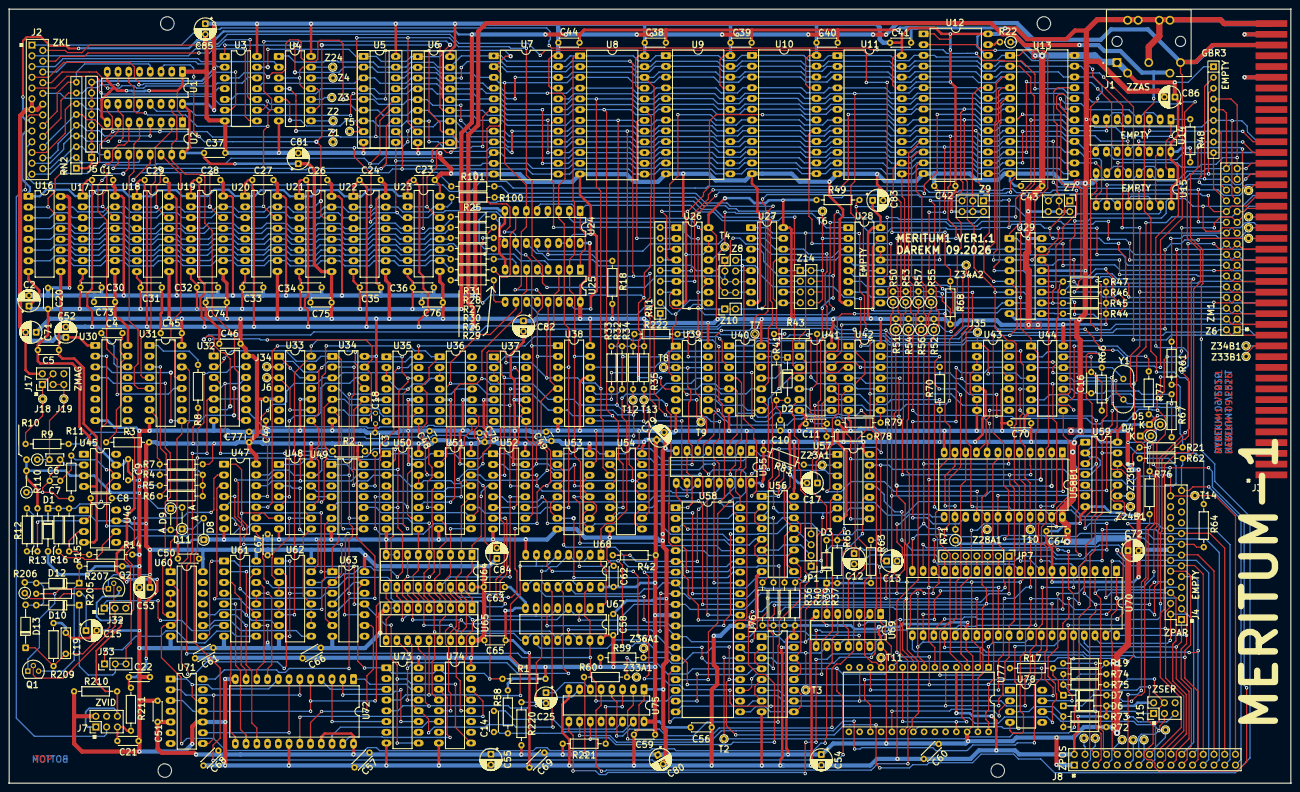
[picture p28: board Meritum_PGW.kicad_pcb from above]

Board: 4 copper layers, 303.0 x 183.0 mm, 331 parts (0 on the bottom side), 337 nets.
